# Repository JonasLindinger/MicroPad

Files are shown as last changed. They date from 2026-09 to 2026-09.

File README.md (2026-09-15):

# MicroPad — Wi-Fi MQTT Controller for Home Assistant

> AI-assisted development — firmware, HA automation, config generator and docs were created with AI (LLM) help, reviewed and tested by the author. Provided as-is, without warranty; verify on your own hardware, don't use for safety-critical applications.

MicroPad is a small ESP32-S3 desk controller with a 2.9" e-paper display, a 3×4
key matrix, and a rotary encoder. It talks to Home Assistant over MQTT and shows
clickable pages of your devices, media, scripts, scenes, and numbers. This
repository contains the firmware, the Home Assistant automation generator, the
web configurator, and the deployment/service assets.

## Safety

- **Not safety-critical.** This project is a convenience input device. Do not use
  it, or rely on it, for safety-critical applications (life-safety, medical,
  security, or anything where a missed or delayed press could cause harm). The
  room always retains the Home Assistant UI as the authoritative control surface.
- **Verify on your own hardware.** Firmware behaviour is validated by the compile
  matrix and host/static suites on this build machine, but no physical MicroPad
  hardware was available during development. Every hardware acceptance row is
  intentionally unchecked until an operator executes it on real hardware. Never
  assume a feature works on your specific board; test it.
- **Neutral placeholders only.** Source contains no real credentials. The broker
  host placeholder is `192.168.0.100`, the service user is `micropad`, and the
  placeholder password is `replace-me`. Real Wi-Fi/MQTT credentials are entered
  only through the on-device setup portal and stored in NVS.
- **Charge-only chargers.** A charge-only wall charger (no enumerated USB host)
  intentionally follows normal battery sleep behaviour: no power icon is drawn
  and light sleep is allowed. Only an enumerated USB data host keeps the device
  fully awake. See `docs/hardware-acceptance.md`.

## Reproducibility

The Python dependency graph is locked: `uv.lock` is the resolved source of
truth, and `requirements-lock.txt` is its content-hash materialization (every
wheel pinned with `sha256`, regenerated with `uv export --frozen`). The build
backend is pinned exactly (`setuptools==84.0.0`). This freezes dependency
*versions and content*; it does **not** claim byte-identical builds, because
pip/setuptools release artifacts can still vary between environments. Generated
automation/payload artifacts are deterministic per configuration (see below).

## Quick start

Create a virtualenv and install the package and dev tools (Ubuntu/Debian shown):

```bash
python3 -m venv .venv
.venv/bin/pip install --requirement requirements-dev.txt
```

For a content-hash-pinned runtime install (every transitive dependency locked in
`uv.lock` and materialized as `requirements-lock.txt` with `sha256` hashes)
instead use:

```bash
.venv/bin/pip install --requirement requirements-lock.txt
```

Run the configurator locally for development (Flask dev server):

```bash
.venv/bin/python -m flask --app micropad.wsgi:app run --host 127.0.0.1 --port 8080
```

Check it is healthy:

```bash
curl http://127.0.0.1:8080/healthz
# -> {"ok": true, "service": "micropad-configurator"}
```

For production, install the systemd service under `/opt/micropad/app` (root):

```bash
sudo ./scripts/setup.sh --enable-service
journalctl -u micropad.service -f
```

The on-device network setup and the build/flash workflow are described in
`docs/firmware.md`.

## Firmware

The firmware lives in `firmware/` (`MicroPad_HA_Controller.ino`,
`micropad_core.*`, and `protocol_contract.h`). It is built with Arduino CLI 1.5.1,
ESP32 core 3.3.11, GxEPD2 1.6.9, ArduinoJson 7.4.3, and PubSubClient 2.8.

```bash
./scripts/install-arduino-toolchain.sh        # pin the exact toolchain
./scripts/compile-firmware.sh --print-matrix  # list the three pinned FQBNs
./scripts/compile-firmware.sh                 # compile all matrix FQBNs
```

See `docs/firmware.md` for the pin map, build/flash commands, the setup portal,
and sleep behaviour.

## Home Assistant

A single MQTT automation (id `micropad_controller`) turns `micropad/event` and
`micropad/power` publications into device actions and re-publishes the
authoritative `micropad/pages/all`, `micropad/page/current`, and `micropad/keymap`
retained payloads. The automation and the retained initial payloads are generated
by `src/micropad/generator.py` and are byte-identical for the same configuration.

You can deliver the generated automation two ways:

- **API upload** — the configurator writes the automation directly to Home
  Assistant via its REST API and verifies the read-back, then publishes the
  retained MQTT payloads.
- **SSH upload** — the configurator uploads a YAML file to your Home Assistant
  host over SFTP/SSH with strict host-key checking and reloads, for setups where
  the REST API path is not available.

Both are covered in `docs/home-assistant.md`.

## Configurator

The Flask web configurator (`src/micropad/app.py`) validates your configuration,
lets you edit pages, key maps, and entity bindings in the browser, discovers
Home Assistant entities, and generates or uploads the automation.

- `GET /api/config` — current public configuration (credentials redacted).
- `POST /api/config` — validate and save a configuration.
- `POST /api/validate` — validate without saving.
- `POST /api/upload/api` — deploy via the Home Assistant REST API.
- `POST /api/upload/ssh` — deploy via SFTP/SSH.
- `GET /api/meta` — contract version, the fourteen key IDs, actions, item types,
  templates, and the default keymap.

See `docs/configurator.md` for the pages editor, key editor, entity discovery,
and validation rules, and `docs/deployment.md` for install/update/logs/uninstall.

---

Licensed under the [MIT License](LICENSE) (Copyright (c) 2026 Jonas Lindinger).
All content above is written in neutral English and uses only the placeholder
values described in the **Safety** section.

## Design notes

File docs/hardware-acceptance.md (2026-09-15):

# MicroPad Hardware Acceptance

> AI-assisted development — firmware, HA automation, config generator and docs were created with AI (LLM) help, reviewed and tested by the author. Provided as-is, without warranty; verify on your own hardware, don't use for safety-critical applications.

This document is a repeatable, row-by-row hardware acceptance gate for a physical
MicroPad bench unit. It is the English release companion to
`docs/firmware-hardware-validation.md`, which holds the full per-row checklists and
the compile/static evidence. Every check below records an **observed result** and a
**pass/fail**; no check may be marked pass from compilation or reasoning alone.

**IMPORTANT — observation rows.** No MicroPad hardware was available on the build
machine during development, so all physical device checks are intentionally left
**unchecked** in the committed revision, exactly as the F14/IT precedent did. The
compile matrix and the host/static suites prove the firmware builds green and the
source asserts hold; they prove *nothing* about physical behaviour. Each check must
be executed by an operator on real hardware and marked from direct observation.

> **Hardware validation not executed: compatible MicroPad hardware unavailable**

Credentials are the neutral placeholders only: broker host `192.168.0.100`, user
`micropad`, password `replace-me`. Real credentials are entered only through the
on-device setup portal and stored in NVS; never edit firmware, source, or docs to
embed real credentials.

## Record file, schema, and validator

The operator records every check in an anonymous, local acceptance record:

- **File (never committed):** `release/local-hardware-acceptance.json`
- **Strict contract:** `release/hardware-acceptance.schema.json`
  (`schema_version: 1`, 64-lowercase-hex `firmware_sha256`, anonymous `board_id`
  matching `bench-[0-9]{2}`, the exact 21 check IDs below all `true`, evidence
  entries `{check_id, kind, sha256, captured_at}`, `additionalProperties: false`
  throughout).
- **Validator:** `scripts/validate_hardware_acceptance.py` validates the record and,
  only when it is fully valid, writes the redacted
  `build/evidence/hardware-acceptance-summary.json` (check IDs, booleans,
  timestamps, firmware SHA-256, per-check evidence SHA-256). No operator, Wi-Fi,
  MQTT, Home Assistant, broker host, or device-entity data ever enters the summary.

```bash
.venv/bin/python scripts/validate_hardware_acceptance.py \
    --input release/local-hardware-acceptance.json \
    --output build/evidence/hardware-acceptance-summary.json
```

An incomplete record exits nonzero and lists every missing/invalid check; a fully
passing bench exits `0`. The local record stays ignored; only the redacted summary
joins the approval bundle.

## Equipment

- **Board:** ESP32-S3 (USB-CDC), wired as in the pin map in `docs/firmware.md`.
- **Display:** GxEPD2_290_T94_V2 2.9" e-paper (native 128x296, driven at rotation 1 as a 296x128 landscape canvas), CS8/DC40/RST41/BUSY42.
- **Inputs:** 3×4 matrix rows 47/48/45, columns 21/14/13/12; rotary encoder A10/B11
  (push = `r0c3` enter).
- **Power:** Li-Ion through a BQ24075 charge path; USB-C host or charge-only supply.
- **Network:** an MQTT broker on the host placeholder `192.168.0.100:1883` and a
  Home Assistant instance (or MQTT bridge) to reconcile state.

Timing checks use a hand stopwatch or the on-device/timing log; reference times are
exact thresholds, not approximations.

## Power and sleep

### `usb-host-icon-after-1500ms` — data-host icon edge-in

- **Setup:** bench unit awake on battery; attach an enumerated **USB-C data host**.
- **Action:** connect the data host and leave the device idle.
- **Observable:** **no** power icon before 1500 ms of host stability; after the
  stable window the power icon is drawn and the retained `micropad/power`
  `{"usb_host":true}` is published. Icon-edge interval measured **1.3–1.8 s**.
- **Evidence kind:** `video` (icon edge) + `timing-log` (edge interval).
- **Pass gate:** edge within 1.3–1.8 s and `usb_host:true` observed once.

### `usb-disconnect-clears-after-1500ms` — data-host icon edge-out

- **Setup:** data host enumerated (prior check state).
- **Action:** detach the data host.
- **Observable:** host removal is debounced the same window and the icon is cleared
  with `{"usb_host":false}` published; edge interval measured **1.3–1.8 s**.
- **Evidence kind:** `video` (icon removal) + `timing-log` (edge interval).
- **Pass gate:** `usb_host:false` observed once, edge within 1.3–1.8 s.

### `usb-host-prevents-sleep`

- **Setup:** enumerated data host connected, device awake.
- **Action:** leave idle past the normal idle-sleep threshold.
- **Observable:** while a data host is enumerated the device **never** enters light
  sleep — no sleep entry, no power icon change.
- **Evidence kind:** `timing-log` (elapsed idle) + `manual-observation`.
- **Pass gate:** no sleep entry for ≥ the idle-sleep threshold while host is up.

### `charge-only-follows-battery-sleep`

- **Setup:** attach a **charge-only wall charger** (no enumerated host).
- **Action:** leave idle past the normal idle-sleep threshold.
- **Observable:** the charger does **not** inhibit sleep — no power icon, and light
  sleep is entered at the normal battery idle threshold (mirror of the host case).
- **Evidence kind:** `timing-log` + `video`.
- **Pass gate:** light sleep entered at normal idle threshold; no power icon.

### `battery-idle-sleeps-near-60s`

- **Setup:** on battery, no USB host, freshly woken, no held keys.
- **Action:** stop touching the device; measure with a stopwatch.
- **Observable:** light sleep after ≈60 000 ms of idle; stopwatch threshold
  **55–70 s**; **no post-sleep watchdog reset** (loop-task TWDT mitigation).
- **Evidence kind:** `timing-log` (stopwatch) + `serial-disabled` (no marker output).
- **Pass gate:** sleep between 55 and 70 s; no watchdog reset after wake.

### `wake-action-immediate`

- **Setup:** device asleep on battery (prior sleep check).
- **Action:** wake with a matrix press or an encoder detent.
- **Observable:** the **waking press becomes the first action** and its effect is
  visible in the **first rendered post-wake snapshot**; no ghost pixels from the
  renderBusy race window; the encoder wake does not lose the next detent.
- **Evidence kind:** `video` (first post-wake snapshot) + `manual-observation`.
- **Pass gate:** first post-wake snapshot shows the waking action; no ghosting.

## Input

Input IDs: matrix `r0c0`…`r2c3` (12 IDs) plus `enc_up` and `enc_down` (14 bindable
IDs, `KEY_COUNT == 14`). Every press must emit exactly one `micropad/event` after
the 25 ms debounce, with no repeat while held.

### `matrix-all-twelve`

- **Setup:** awake, default keymap.
- **Action:** press each of the twelve matrix keys once.
- **Observable:** exactly one `micropad/event` per debounced press, no repeat while
  held, and all **twelve** matrix IDs (`r0c0`…`r2c3`) emit their expected binding.
- **Evidence kind:** `video` (visible presses) + `manual-observation`.
- **Pass gate:** all 12 IDs emit exactly once per press; no repeats while held.

### `encoder-clockwise-down`

- **Setup:** awake, on a page with a selection.
- **Action:** one clockwise/right detent.
- **Observable:** emits `enc_down` and the selection moves **+1**; one step per
  detent with no repeat while the knob stays in a detent.
- **Evidence kind:** `video` + `timing-log`.
- **Pass gate:** `enc_down` on clockwise detent and selection +1.

### `encoder-counterclockwise-up`

- **Setup:** awake, on a page with a selection.
- **Action:** one counterclockwise/left detent.
- **Observable:** emits `enc_up` and the selection moves **−1**; one step per detent.
- **Evidence kind:** `video` + `timing-log`.
- **Pass gate:** `enc_up` on counterclockwise detent and selection −1.

### `encoder-push-r0c3`

- **Setup:** awake, on a page where `r0c3` is the enter action.
- **Action:** press the enclosure **push** button on the encoder.
- **Observable:** the push acts as `r0c3` (enter): one `micropad/event` for `r0c3`
  and the mapped enter action fires.
- **Evidence kind:** `video` + `manual-observation`.
- **Pass gate:** push produces a single `r0c3` event and the enter action.

### `input-during-refresh`

- **Setup:** awake, a display refresh is about to be triggered.
- **Action:** trigger a refresh and hold a key during the BUSY window.
- **Observable:** the input state change is applied **before the refresh
  completes** — input scanning on Core 1 never starves matrix/encoder.
- **Evidence kind:** `video` + `manual-observation`.
- **Pass gate:** the held key registers before the refresh finishes.

## Display

The panel is a 2.9-inch e-paper (native 128x296) driven at rotation 1 as a 296x128
landscape logical canvas. "Four visible rows" refers to the readable item list
that must render fully across the 296-px-wide landscape canvas.

### `boot-full-refresh`

- **Setup:** device powered down/off.
- **Action:** power on / reset.
- **Observable:** boot performs a **full refresh** — the whole 128×296 panel clears
  and redraws before any partial content appears.
- **Evidence kind:** `video`.
- **Pass gate:** full-panel refresh visible once at boot.

### `display-four-rows`

- **Setup:** a page with at least four bindings, default keymap.
- **Action:** navigate to that page.
- **Observable:** the UI is readable: title/status strip, **four item rows**,
  selection cursor, conditional scrollbar, and network-status cell all render
  clearly in the 296×128 landscape canvas.
- **Evidence kind:** `photo`.
- **Pass gate:** four item rows fully visible and readable.

### `full-panel-partial-refresh`

- **Setup:** awake on a page with multiple rows.
- **Action:** trigger a navigation partial refresh.
- **Observable:** every partial refresh is a **single full-native-panel**
  `setPartialWindow(0,0,128,296)` window — no per-row windows and no partial-row
  striping.
- **Evidence kind:** `video` + `timing-log`.
- **Pass gate:** partial refresh uses the full native 128×296 window each time.

### `ghosting-bound`

- **Setup:** awake; perform several refreshes.
- **Action:** run repeated (partial) refreshes over the same area.
- **Observable:** **no per-row waveform / ghost banding** — prior content leaves no
  residual banding layer across refreshes (bounded ghosting).
- **Evidence kind:** `photo` + `manual-observation`.
- **Pass gate:** no visible residual banding after repeated refreshes.

## Connectivity

### `portal-random-password`

- **Setup:** first boot with no saved settings.
- **Action:** power on and observe the setup access point, then exit and
  re-enter the setup portal (or reboot twice).
- **Observable:** AP `MicroPad-Setup` appears and the panel shows a
  **16-character password**. The password is **generated once from hardware
  entropy and persisted in NVS** — the same password is shown on every later
  portal entry, so a phone that already joined reconnects with the saved
  network instead of a new code.
- **Evidence kind:** `photo` + `manual-observation`.
- **Pass gate:** AP name present, a 16-character password shown, and the same
  password after portal exit/re-entry.

### `portal-never-sleeps`

- **Setup:** setup portal open, battery powered.
- **Action:** leave the portal idle past the normal battery idle-sleep
  threshold (~60 s), then keep waiting.
- **Observable:** the portal stays fully awake — the AP keeps beaconing, the
  DNS/web server keeps answering, the phone stays connected. No light-sleep
  entry while the portal is active; the portal's own
  ≈5-minute inactivity restart is the only shutdown path.
- **Evidence kind:** `video` + `manual-observation`.
- **Pass gate:** no sleep entry while the portal is open (sleep only after
  portal exit / settings saved).

### `portal-input-responsive`

- **Setup:** setup portal open.
- **Action:** operate matrix/encoder while the portal is open.
- **Observable:** matrix and encoder remain **responsive** while the portal is open —
  inputs are never starved by the portal loop.
- **Evidence kind:** `video` + `manual-observation`.
- **Pass gate:** inputs respond while the portal is open.

### `portal-back-no-save`

- **Setup:** portal open with unsaved edits.
- **Action:** select **Back** / cancel.
- **Observable:** the portal exits leaving **NVS/settings unchanged** — no save and
  no reconnect to any saved network.
- **Evidence kind:** `video` + `manual-observation`.
- **Pass gate:** after Back, no stored credential change and no reconnect.

### `wifi-mqtt-nonblocking`

- **Setup:** device connected to station network and broker.
- **Action:** navigate and toggle while the network transmits/reconnects.
- **Observable:** Wi-Fi/MQTT operations **never block** matrix/encoder input (Core 1
  input scanning continuous), and there is **no USB CDC output on any hot path**.
- **Evidence kind:** `video` + `serial-disabled`.
- **Pass gate:** responsive input throughout; no CDC output on hot paths.

### `mqtt-reconnect-resubscribe`

- **Setup:** device connected; broker running.
- **Action:** interrupt the broker link (stop then restore the broker), then wait.
- **Observable:** the stale socket is invalidated and MQTT **reconnects immediately**
  after the interruption, **resubscribing** to `micropad/pages/all`,
  `micropad/page/current`, and `micropad/keymap`; retained payloads are recovered on
  (re)connect with concrete values.
- **Evidence kind:** `video` + `timing-log`.
- **Pass gate:** reconnect immediate; all three retained topics recovered.

### `authoritative-resync`

- **Setup:** local display diverges from authoritative state.
- **Action:** publish an authoritative update, then leave the device idle.
- **Observable:** an **authoritative correction arrives after the 350 ms quiet-period
  resync** when local and authoritative disagree; retained `micropad/pages/all` and
  `micropad/page/current` carry concrete states, not `{{ states(...) }}` templates.
- **Evidence kind:** `video` + `manual-observation`.
- **Pass gate:** correction arrives after resync; no templated retained payloads.

MicroPad is not safety-critical. It is provided as-is, without warranty, and every
row here must be verified on your own hardware before relying on the device.

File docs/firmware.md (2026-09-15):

# MicroPad Firmware Guide

> AI-assisted development — firmware, HA automation, config generator and docs were created with AI (LLM) help, reviewed and tested by the author. Provided as-is, without warranty; verify on your own hardware, don't use for safety-critical applications.

This guide covers building and flashing the MicroPad firmware
(`firmware/MicroPad_HA_Controller.ino`, `firmware/micropad_core.*`,
`firmware/protocol_contract.h`). It is written in English and contains no real
credentials — only the neutral placeholders described below.

## Contract

`contracts/mqtt-contract.json` is the single source of truth for the wire
protocol: version, topics, key IDs, actions, item types, the descriptor row per
item type, the payload ceilings and the device caps. Everything else is derived
from it:

- `firmware/protocol_contract.h` is **generated** —
  `python3 scripts/generate_contract.py --write` after a contract change, and
  `--check` is the drift gate (also asserted by
  `tests/integration/test_mqtt_contract.py`). Never hand-edit the header.
- `src/micropad/constants.py` and `src/micropad/ui_meta.py` read the contract at
  import time, so the backend, `/api/meta` and the browser cannot lag behind it.
- the browser's `static/js/contracts.js` key-ID/version block is generated too.

Adding an action, an item type, a topic or a limit is therefore a contract edit
plus a regenerate — no code path has to be kept in sync by hand. A static test
additionally asserts that the firmware's `Action`/`ItemType`/`KeyId` enums are in
contract order, that `micropad_core.h`'s caps equal the contract's, and that
`micropad_core.cpp`'s `ITEM_TYPE_DESCRIPTORS` table matches `item_type_meta`.

## Pin map

| Function | GPIO(s) |
|---|---|
| E-Paper CS / DC / RST / BUSY | 8 / 40 / 41 / 42 |
| Matrix rows (active-low) | 47, 48, 45 |
| Matrix columns | 21, 14, 13, 12 |
| Encoder A / B | 10 / 11 |

The display is a GxEPD2_290_T94_V2 2.9" e-panel (`128×296`, full-width partial
windows). Three rows × four columns plus the two encoder detents give the
fourteen bindable input IDs: `r0c0 … r2c3`, `enc_up`, `enc_down`. Rows are
driven active-low and restored after scanning.

## Build

The toolchain is pinned to Arduino CLI **1.5.1**, ESP32 core **3.3.11**,
GxEPD2 **1.6.9**, ArduinoJson **7.4.3**, and PubSubClient **2.8**. Preface the
commands with the repo `python3`-based workflows as needed; the toolchain script
is self-contained bash.

```bash
./scripts/install-arduino-toolchain.sh          # install + verify the pins (rootless, repo-local .arduino/)
./scripts/compile-firmware.sh --print-matrix    # show the three pinned FQBNs
./scripts/compile-firmware.sh                   # stage + compile all matrix FQBNs
./scripts/compile-firmware.sh --one <FQBN>      # stage + compile a single validated FQBN
./scripts/compile-firmware.sh --stage-only <FQBN>  # stage only (no toolchain), into build/arduino/
```

The script stages the reviewed sources into
`build/arduino/MicroPad_HA_Controller/`, compiles with `--warnings all`
plus `-Werror=return-type`, and compiles the three FQBNs:

```
esp32:esp32:esp32s3:USBMode=hwcdc,CDCOnBoot=cdc,PSRAM=opi
esp32:esp32:esp32s3:USBMode=default,CDCOnBoot=cdc,PSRAM=opi
esp32:esp32:esp32s3:USBMode=hwcdc,CDCOnBoot=default,PSRAM=disabled
```

## Flash

The recommended upload FQBN for a USB-CDC data host is
`esp32:esp32:esp32s3:USBMode=hwcdc,CDCOnBoot=cdc,PSRAM=opi`. Upload a staged
sketch with Arduino CLI against its enumerated serial device:

```bash
arduino-cli upload \
  --config-file arduino-cli.yaml \
  -p /dev/ttyACM0 \
  --fqbn "esp32:esp32:esp32s3:USBMode=hwcdc,CDCOnBoot=cdc,PSRAM=opi" \
  build/arduino/MicroPad_HA_Controller/
```

Do not embed real Wi-Fi or MQTT credentials in the firmware; they are entered
at runtime through the setup portal and stored in NVS.

## Setup portal

On first boot (or when no network settings are saved) the device starts a captive
portal AP named `MicroPad-Setup` with a 16-character password shown on the
panel. The password is generated once from hardware entropy, stored in NVS, and
**reused by every later portal entry** — it never rotates between sessions, so a
phone that already joined the AP reconnects with the same saved network. From
the portal you save the station Wi-Fi credentials and the MQTT broker
settings (host, port, user, password), then the device restarts its AP and
reconnects to the network and broker. The matrix and encoder remain responsive
while the portal is open; `Back` cancels and leaves settings unchanged; the
portal restarts itself after roughly 5 minutes of inactivity. Entering the portal
is bound to the `settings` action. While the setup portal is open the device
**never enters light sleep** — sleeping would silence the AP, DNS and web server
mid-setup.

The portal is also reachable without a working keymap: if the pad has stored
settings but cannot associate for 24 consecutive attempts (~2 minutes), it
re-opens the setup portal by itself, so a mistyped Wi-Fi password or a moved
access point cannot strand the device. The panel shows the portal view, and
`Back` (bound by default) cancels it and keeps the stored settings.

A save is applied atomically in the sense that the NVS commit marker (`cfg_ver`)
is cleared before the first field is written and set to `1` only after every
field was stored. An interrupted save is therefore an invalid record, and the
next boot falls back to the setup portal instead of connecting with a mixture of
old and new credentials.

The broker host placeholder used in source is `192.168.0.100`, the user
placeholder is `micropad`, and the password placeholder is `replace-me`. Replace
these only through the portal.

## Sleep

When the device is on battery and idle for about 60 seconds **and not powered by
a USB data host**, it enters warm light sleep (`esp_light_sleep_start`), waking on
the matrix or encoder (EXT1, ANY_LOW). Behaviours worth knowing:

- Sleep is refused while USB-powered, and "powered" means an enumerated **data**
  host. Detection lives in `isPowered()`: the USB-serial-JTAG host check
  (`Serial.isPlugged()`, the IDF SOF watchdog — true while a host holds the port
  open, even with no serial monitor attached) plus the HWCDC session flag. The
  debounced state (`stableUsbHost`, 500 ms sample / 1500 ms stable) blocks both
  sleep guards as well, so a single flapping raw read cannot open the sleep path.
- `configureCdc()` calls `Serial.begin(115200)` in the hwcdc build: the core
  starts USB CDC automatically for the TinyUSB build only
  (`cores/esp32/main.cpp`: `#if ARDUINO_USB_CDC_ON_BOOT && !ARDUINO_USB_MODE`), and
  without the driver being started the HWCDC interrupt handler — the only setter
  of the CDC session flag — and the D+ pull-up never exist. A pad on a plain USB
  cable would then read as battery-powered.
- A **charge-only wall charger** (no enumerated host) intentionally follows normal
  battery sleep behaviour: no power icon and light sleep allowed.
- Light sleep is currently **disabled** (`LIGHT_SLEEP_ENABLED = false`) until the
  S3 wake path is fixed (phantom key presses after wake, see the `loop()` comment).
  The detection above still drives the power icon and the retained
  `micropad/power` state, and it is what has to be correct before sleep is
  re-enabled.
- The 15-second MQTT keepalive is used to invalidate a stale socket after a long
  sleep, so MQTT reconnects immediately on wake.
- The render task's watchdog entry is removed before sleep and restored after
  wake; matrix rows are driven low and restored on wake so the waking press
  becomes the first action.
- After wake there is a short brake so the device does not immediately re-sleep.

For the full acceptance rows (including the >60 s sleep, watchdog, and ghost-pixel
checks) see `docs/hardware-acceptance.md`.

## Input, payload and stack limits

- **Values are never rejected for being long.** Item names, page titles, states
  and units are *clipped* to their 32-character fields (the renderer shows 12
  characters of a value and 22 of a title), so a long Home Assistant state — for
  example a template sensor with a verbose string — cannot discard a whole page
  or catalog payload. Identifiers (`page_id`, `entity`, `target_page`) keep the
  strict check: a silently clipped entity id would address the wrong device.
- **The MQTT buffer bounds the catalog.** The client buffer is 16 KiB
  (`MQTT_BUFFER_BYTES`, mirrored in `contracts/mqtt-contract.json`); a retained
  `micropad/pages/all` that exceeds it is discarded by PubSubClient without
  telling the application. While the pad is connected but has no catalog, it
  re-requests the catalog every 60 seconds, so a lost publication is repaired
  instead of leaving an empty page.
- **The loop task stack is 16 KiB.** The MQTT callback parses the PubSubClient
  receive buffer in place (no payload copy), which keeps its frame near 7 KB;
  16 KiB leaves a ~2.3x margin and returns the rest of the former 32 KiB to the
  heap, where the 16-KiB MQTT buffer and the WiFi/lwIP buffers live. The value is
  the core constant `LOOP_TASK_STACK_BYTES`, so the sketch, the device-info
  payload and the tests cannot disagree about it.
- **The pad advertises its own limits.** On every MQTT connection the device
  publishes the *retained* payload `micropad/device`:

  ```json
  {"fw": "1.2.0", "contract": 2, "caps": {"pages": 24, "items": 20, "name": 32,
   "title": 32, "page_id": 32, "entity": 96, "state": 32, "unit": 16,
   "mqtt_buffer": 16384, "stack": 16384}}
  ```

  Every value is read from the firmware's own constants, so it describes what
  this build really enforces instead of what the backend assumes. A late
  subscriber (the backend, the configurator) gets it without asking, which is
  what lets `/api/meta` report the pad's real field caps and warn before a value
  would be clipped on the panel.

## Input gestures

Each of the fourteen inputs behaves the same whether it is tapped or held, with one
exception that costs no extra binding storage: **holding the Enter key fires the
item's *alternate* action instead of its default one.** The item-type descriptor
decides which types have one — a light or a switch turns **off** on a hold instead
of toggling; every other type ignores the hold (`alternate_action` in
`contracts/mqtt-contract.json`, mirrored by `ITEM_TYPE_DESCRIPTORS`). The gesture
dispatches an ordinary action, so the MQTT event, the Home Assistant automation and
the payload schemas are unchanged.

* `LONG_PRESS_MS` (600 ms, core) is measured from the *debounced* press, so a tap
  can never fire it, and it fires exactly once per hold.
* A hold keeps the pad awake (it counts as input activity) and therefore cannot
  race the 60 s sleep gate.
* The press that woke the device from light sleep is consumed by the immediate wake
  scan, so holding it does not also fire the gesture — otherwise holding the key
  that woke the pad would turn something off.

## Stored settings and the setup portal

Settings live in NVS under the namespace `micropad`, guarded by a `cfg_ver` commit marker that
is invalidated first and written last, so an interrupted save is an invalid record rather than a
mixture of old and new credentials. A record is accepted only when the marker is current, every
expected key exists, every value reads back inside its field, and the whole candidate validates
(`micropad::validateSettings`), which is defined in terms of `settingsError()` so the rule and
the message cannot drift apart. A rejected record means the pad starts its own setup portal -
which is also what makes the read path worth pinning:

* **Strings are read with string APIs** (`isKey()` for presence, `getString()` for the value,
  which refuses an oversized value instead of truncating) and integers with the type-aware
  `getType()`/`getUShort()` pair. `Preferences::getBytesLength()` must never be used for either:
  it is a *blob* accessor (it calls `nvs_get_blob`), and an IDF blob read on an entry written
  with `nvs_set_str` fails with `ESP_ERR_NVS_TYPE_MISMATCH`. It therefore reports 0 for a value
  that is present, which makes every stored string look absent, rejects a complete record, and
  sends a fully configured pad back into the portal on **every boot**. A static test pins the
  type-correct API usage precisely because this failure is silent and looks like a Wi-Fi problem.
* A refused save answers with the reason (`settingsError()`: which field and what is expected,
  never its value), so the portal is fixable in place instead of showing "invalid settings".

## Diagnostics

The payload carries `uptime_s`, `mqtt_connects`, the accept/reject counters per payload type,
`event_drops`, the heap free and heap high-water figures, and `stack_min` - the loop task's stack
high-water mark in bytes free, sampled with `uxTaskGetStackHighWaterMark()` from the loop task
itself. `stack_min` is what confirms the 16 KiB loop stack on real hardware: the linked call
frames say the worst callback uses 6,704 B, and this number shows how much was actually left.
The worst-case payload (ten 10-digit values) measures 254 bytes against a 320-byte cap.

Every connection publishes the retained `micropad/diag` payload, refreshed once a
minute while connected:

```json
{"uptime_s":3661,"mqtt_connects":3,"catalog_parses":2,"catalog_rejects":1,
 "page_rejects":4,"keymap_rejects":5,"event_drops":6,"heap_free":123456,
 "heap_min":100000}
```

The counters answer the questions a serial console used to answer: is the pad
reconnecting in a loop, did a retained payload get rejected, did events get dropped
because the queue was full, and how close did the heap get to exhaustion. The
struct and the formatter live in `micropad_core.h`/`.cpp` (`formatDiagnostics`,
host-tested byte for byte), so the sketch only bumps counters and publishes; the
payload is rendered into a 256-byte stack buffer with no JSON document, and the
formatter refuses to write rather than emitting a truncated object.

## Host simulator (panel preview)

`tools/micropad_sim.cpp` compiles `micropad_core.cpp` into a host binary that
answers "what does the panel render for this page, and what does this key do?":

```bash
./scripts/build-simulator.sh                 # g++ only, no Arduino toolchain
printf 'page home Home\nitem Desk light\t on\t\t0\tlight\tlight.desk\t\nkey r0c3\tenter\tlight.desk\t\npress r0c3\n' \
  | ./build/host/micropad_sim
```

It prints one JSON object: the row window, the prim list from `layoutNormalUi` /
`layoutPortalUi`, `would_reject` plus `findings` for anything the pad would clip or
refuse, and — when a `press` directive is given — what the binding and the item
under the cursor resolve to. The configurator's preview and budget panel are
driven by it (`docs/configurator.md`), and `tests/test_simulator.py` pins the
output, including a check that the recorded browser fixture still matches the
current core.

The tool contains no geometry or policy of its own: it reads a small directive
format and calls the core. `fillPageSnapshot()` in the core is the shared
snapshot builder used by both the sketch and the simulator, so the row window,
title and selection flags cannot differ between the panel and the preview.

## Not safety-critical

This firmware drives an e-paper controller and sends MQTT events; it is a
convenience input device, not a safety mechanism. It is provided as-is, without
warranty, and must be verified on your own hardware. Do not use it for
safety-critical applications.

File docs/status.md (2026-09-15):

# MicroPad — status: what is done, what is left

> AI-assisted development — firmware, HA automation, config generator and docs were created with AI (LLM) help, reviewed and tested by the author. Provided as-is, without warranty; verify on your own hardware, don't use for safety-critical applications.

**Merged into `main`** through PR #9 (merge commit `de680e2`, both histories preserved: `main`'s own
line and this branch's, which share no ancestor). **Release: `v1.2.0`** — firmware `1.2.0`,
contract revision `2`; see `CHANGELOG.md` for what is in it, what was measured and what is
deliberately left out. Every claim below was verified with real
runs; nothing is "should work".

**Current baseline** (real `arduino-cli` build, pinned `hwcdc/PSRAM` FQBN):
flash **1 006 963 B (76 %)** · static RAM **173 364 B (52 %)** · 302 757 B flash free.
**Tests:** 834 pytest (44 of them browser) · 199 firmware static · host core binary · 193 release.

---

## ✅ Done (shipped, tested, pushed)

### Phase A — makes adding features cheap

| ID | What | Commit | Proof |
|---|---|---|---|
| **A1** | **Contract is the single source of truth.** `contracts/mqtt-contract.json` drives everything; `scripts/generate_contract.py --write/--check` generates `firmware/protocol_contract.h` + the browser key-ID block; Python derives at import | `ee98fcf` | 8 drift gates (codegen, enum order = wire order, firmware caps = contract caps, descriptor table = contract, backend rules, `/api/meta`, browser fixture) |
| **A2** | **One descriptor row per item type** (`ItemTypeDescriptor`: default action, alternate action, editable) drives `actionForSelectedItem`, `models.py`, `generator.py`, `/api/meta`, the editor | `ee98fcf` | host test `testItemTypeDescriptorTable` + drift gate |
| **A3** | **Pad advertises its own limits**: retained `micropad/device` (`fw`, `contract`, `caps` from its own constants) | `ee98fcf` | `/api/meta` exposes `limits`/`caps`/`item_type_meta` |
| **A4** | **Firmware-in-the-loop simulator**: `tools/micropad_sim.cpp` compiles the shipped core; the sketch's row loop moved into the core (`fillPageSnapshot`) so panel and preview share one builder | `6e2b1ce` | `tests/test_simulator.py`; fixture recorded from the real binary + a drift gate |
| **A5** | **`/api/simulate`** renders a page (or the portal) through that binary; 503 when missing, 400 with the offending field | `6e2b1ce` | route tests |
| **A6** | **Config-lint CLI** `scripts/lint_config.py` (exit 0/1/2, `--strict`, `--json`) + **a CI hole closed**: the `firmware-host` stage now also runs `test_core.cpp` and the 142 static tests (they ran nowhere in CI before) | `18644b9` | stage dry-run green |
| **A7** | **Golden-file tests**: automation YAML + the three published payloads frozen in `tests/fixtures/golden/`, regenerate with `MICROPAD_UPDATE_GOLDEN=1` | `d0f319d` | negative test: mutating a golden fails two tests |
| **A8** | **Pre-commit gate** `.githooks/pre-commit` (ruff, mypy, contract drift, firmware host ≈ 4 s) — documented, deliberately **not** auto-enabled | `d0f319d` | hook dry-run |
| **A9** | **Developer guide** `docs/developer.md`: recipes (action / item type / topic / template), gate table, conventions tests enforce | `d0f319d` | — |

### Phase B — the config website

| ID | What | Commit | Proof |
|---|---|---|---|
| **B1** | **Faithful panel preview**: `panel-preview.js` draws the core's prim model as SVG (296×128, monochrome, FreeMono) + portal toggle — no layout knowledge in the browser | `6e2b1ce` | browser tests against a real recorded model |
| **B2** | **Budget meters**: page/catalog/MQTT-buffer/pages/items from `/api/lint` | `6e2b1ce` | browser test |
| **B3** | **"What the device changes"**: `field_clipped` warnings vs `identifier_too_long` errors with `where` paths | `6e2b1ce` | route + browser tests |
| **B4** | **Hardware-shaped keymap board**: 3×4 + encoder; each face shows the effective action and its origin (`global` / `inherited` / `override`) | `a8d4262` | browser test incl. the scope transitions |
| **B5** | **Page generation from the entity cache**: `/api/entity-groups` + `/api/build-pages` (one page per domain, split at 20, 24-page ceiling, real `number` ranges, clipping reported in `notes`) + UI buttons | `a9be614` | 8 backend + 3 browser tests |
| **B7** | **Config history / diff / restore**: content-addressed snapshots beside the config (mode 600, git-ignored), list, structural diff that never prints secrets, confirmed restore in the UI | `26f41d0` | 10 backend + 3 browser tests incl. traversal + stale revision |

### Phase C — device features

| ID | What | Commit | Proof |
|---|---|---|---|
| **C1** | **Long press**: a hold dispatches the item's *alternate* action (light/switch → off); timing in the core (`LONG_PRESS_MS` 600, once per hold), wake press exempt, no protocol change, +184 B flash / +48 B RAM | `a6467cb` | host test (tap/hold/re-arm/None) + static pin |
| **C2** | **Diagnostics**: retained `micropad/diag` (uptime, MQTT connects, parse accept/reject counters, dropped events, heap high-water), formatter in the core, 256 B stack buffer, +768 B flash / +40 B RAM | `38cffc0` | host test byte-for-byte incl. worst case |
| **Fix** | **The pad re-entered the setup portal on every boot**: the NVS read helpers used the blob accessor `getBytesLength()`, which reports 0 for a value stored as a string, so `loadSettings()` rejected a complete record every time. Fixed with the string-shaped APIs and pinned by a static test (the old test *required* the broken accessor) | `e751e45` | 199 static + host core; needs one flash to confirm on hardware |
| **Fix** | **The `ci` workflow was red on this branch, and nobody was watching it**: a test read `Dockerfile.local`, a file that only ever existed on one machine, so the workflow failed at the `coverage` stage and the eleven stages behind it never ran. Fixed by shipping the (secret-free) Dockerfile and testing the tracked file; the whole stage list now runs | *CI fix* | the deployment test was re-run in a clean checkout, i.e. the exact CI condition |
| **Fix** | **The firmware CI stage silently skipped four contract classes** — `unittest.main()` sat above them, so the stage exercised 142 of 198 cases and reported green | `28ce2ea` | the stage and pytest now report the same count |
| **C4** | **Four new item types**: `cover`, `fan`, `input_boolean`, `lock` — each one contract row + one firmware descriptor row + the HA service mapping; the editor, `/api/meta` and the validation follow automatically. Tapping toggles (a lock *locks*), holding turns off (a lock *unlocks*); a cover has no hold action because HA's cover integration has no `turn_off` | `d2ec93b` | 7 new generator service rows, host descriptor assertions, all item-type pins updated. +64 B flash, 0 B RAM |

---

## 🔜 Left, and unblocked

| ID | Item | Effort |
|---|---|---|
| **C4b** | **`select`/`input_select` item type** — the encoder cycles the options; needs the option list in the payload plus a "next option" behaviour, i.e. a small contract decision | M |
| **C6** | **Icon/glyph set** in the prim model (wifi-error, lock, play/pause, thermometer, brightness) | S |
| **C7** | **Portal: factory reset + connection result** (reset part; OTA is bigger) | M |
| **C8** | **Per-page refresh policy** + dashboard template (periodic partial refresh) | M |
| **C9** | **Breadcrumb depth in the title strip** + long-press context menu on a row | S–M |
| **B8** | **Post-upload read-back**: after upload, re-read the retained topics and compare (`scripts/verify_live_mqtt.py` is the basis) | S–M |
| **B9** | **German/English, dark mode, mobile layout** of the configurator | S–M |
| **C5** | **Dimmer interaction** (hold + encoder steps a light's brightness) | M |

## ⛔ Left, blocked on an open decision

| ID | Item | The decision |
|---|---|---|
| **B6** | **Live device mirror + remote key press** — would have made the last debugging session much faster | The backend needs **broker credentials** (a new secret surface in the configurator, redaction, and a paho-mqtt dependency). Or: skip the mirror, do only remote key press via HA's `mqtt.publish` service (uses the existing HA token). |
| **C1b** | **Double press + encoder acceleration** (rest of C1) | A *contract* decision: a repeat/step parameter, or a second action + target per key (≈ +1.8 KB RAM) — or drop double press and do only encoder acceleration. |
| **B12** | **"One page per *room*"** | Needs the HA **area registry** (WebSocket API / a second credential), not `/api/states`. |
| **B11** | **Move payload decoding into the core** (removes the last mirrored logic and ArduinoJson from the hot path) | Device-facing refactor of the MQTT callback — needs a hardware test pass to be called done. |

## 🔌 Left, needs the real pad

| ID | Item |
|---|---|
| **D1** | Battery gauge (needs a PCB revision) |
| **D2** | Wall-dashboard mode (timer wake + deep sleep) |
| **D3** | Encoder push button (verify the part first) |
| **C1/C2** | the shipped gestures/diagnostics are host-verified only — one press on the pad and one look at `micropad/diag` would close them (the payload now carries `stack_min`, the loop stack's high-water mark, so the 16 KiB stack is confirmed by reading a topic) |
| **Settings fix** | flash, configure once through the portal, restart: the pad must come up in normal mode instead of reopening the portal |
| **C3** | Notification banner (HA → pad): firmware render work, then a real-pad check |
| **C10** | Multi-device support |

---

## How to verify any of this yourself

```bash
bash scripts/test_firmware_contract.sh        # contract + core host + 142 static (~2 s)
.venv/bin/python -m pytest -q                 # everything (~75 s)
.venv/bin/python -m pytest tests/browser -q   # just the UI in Chromium (~30 s)
python3 scripts/lint_config.py config.json    # would the pad store/show this config
python3 scripts/generate_contract.py --check  # generated sources not stale
./scripts/build-simulator.sh                  # the host binary the preview uses
./scripts/compile-firmware.sh --one "esp32:esp32:esp32s3:USBMode=hwcdc,CDCOnBoot=cdc,PSRAM=opi"
```

Explicitly **not** done, on purpose: a second protocol version, any cloud dependency, a scripting
engine on the device, bigger buffers, OTA outside the portal. ("Don't do" list kept honest: see the
roadmap at `docs/roadmap.md` for effort/risk per item and the reasoning.)

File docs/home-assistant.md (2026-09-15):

# MicroPad × Home Assistant

> AI-assisted development — firmware, HA automation, config generator and docs were created with AI (LLM) help, reviewed and tested by the author. Provided as-is, without warranty; verify on your own hardware, don't use for safety-critical applications.

This guide explains how MicroPad talks to Home Assistant and the two ways to
deploy the generated automation. The broker host placeholder used throughout is
`192.168.0.100` (user `micropad`, password `replace-me`); real values are entered
only through the configurator or the on-device setup portal, never in source.

## MQTT contract

MicroPad and Home Assistant share one versioned contract
(`contracts/mqtt-contract.json`, bindings in `firmware/protocol_contract.h` and
`src/micropad/constants.py`, contract version **1**). Seven exact topics:

| Topic | Direction | Retain | Purpose |
|---|---|---|---|
| `micropad/event` | device → HA | no | decoded key/encoder action |
| `micropad/pages/all` | HA → device | yes | boot-time page catalog |
| `micropad/page/current` | HA → device | yes | current page payload |
| `micropad/keymap` | HA → device | yes | effective per-page key map |
| `micropad/power` | device → HA | yes | USB/power state (`usb_host` true/false) |
| `micropad/device` | device → HA | yes | firmware build + the caps the pad enforces (`fw`, `contract`, `caps`) |
| `micropad/diag` | device → HA | yes | uptime, MQTT connects, parse accept/reject counters, dropped events, heap high-water mark |

The generator (`src/micropad/generator.py`) turns a validated configuration into
one automation with id `micropad_controller` plus the three retained initial
publications (`micropad/pages/all`, `micropad/page/current`, `micropad/keymap`).
Payload ceilings are 8192 bytes per page, 16000 per catalog, 16380 per keymap,
with a 16384-byte firmware MQTT buffer. Generation is deterministic: the same
config produces byte-identical YAML, JSON, and MQTT payloads.

## API upload

`POST /api/upload/api` (implemented by `src/micropad/ha_deploy.py`) deploys
directly to a running Home Assistant over its REST API:

1. verifies auth (`/api/ha/test`), then create-or-update the automation by id;
2. calls `automation.reload`, then **reads back** the automation and confirms the
   structure matches what was generated;
3. re-generates with fresh entity state and publishes the three retained MQTT
   topics, verifying each publication.

Requirements: a Home Assistant long-lived access token
(`settings.ha_token`), the instance URL (`settings.ha_url`, e.g.
`http://homeassistant.local:8123`), and **TLS verification on by default**
(`settings.verify_tls` defaults to `true`). The token is redacted from every
public response (`ha_token_configured` reports only a boolean). A verified
evidence record (automation id, SHA-256, request order, published-topic list) is
emitted through the deployer's evidence sink.

## SSH upload

`POST /api/upload/ssh` (implemented by `src/micropad/ssh_upload.py`) targets
installations where the REST/automation path is not usable, by pushing the
generated YAML over SFTP/SSH with **strict host-key checking**:

- writes a temp copy next to `settings.remote_path` (default
  `/config/automations/micropad.yaml`);
- runs a fixed, in-code validation `test -s <temp>` — no user-supplied command;
- atomically `mv`s it into place, then applies the fixed reload for the
  `settings.ssh_reload_strategy` enum (`core_restart` → `ha core restart`, or
  `none` to skip);
- rejects placeholders, non-absolute remote paths, and any shell-metacharacter
  path values. No free-form remote command is accepted from the API, so a
  compromised config endpoint can never inject a remote shell command.

`GET /api/download/ssh` returns a secret-free `upload_micropad.sh` operator
script that reproduces the same SFTP upload from environment variables
(`SSH_KEY`, `AUTOMATION_YAML`) without embedding credentials.

**Difference from API upload:** SSH upload transfers only the automation YAML and
reloads; it does **not** publish the three retained MQTT topics itself, and it
relies on your existing Home Assistant automation layer (and the reload to pick
it up) rather than creating the automation through the REST API. Choose SSH when
the device cannot be reached over the HA REST API, and API upload when it can
(the API path is fully verified end-to-end).

## Rollback

- **API upload:** because the automation is create-or-update by a fixed id, deploy
  replaces it. To roll back, re-generate from a known-good configuration and
  deploy again, or restore the previous automation in Home Assistant's automation
  editor. The retained MQTT topics are re-published on every successful deploy, so
  the device re-syncs to the new state on reconnect.
- **SSH upload:** the deployed file replaces `settings.remote_path`
  atomically. Keep a backup of the previous file; to roll back, `scp`/`sftp` your
  backup back to `remote_path` and re-apply the fixed reload
  (`ssh_reload_strategy: core_restart` → `ha core restart`).
- **Local previews:** the live-deployment gate is hash-locked. Run
  `scripts/render_live_ha_preview.py --config <config> --output build/live-ha-preview`
  to produce `automation.json`, `automation.yaml`, `mqtt-publications.json`, and
  a `release.sha256`, approve that digest, then `scripts/apply_live_ha_preview.py`.
  **Operator note:** after a live apply, the automation read-back and the actual
  retained publications can drift from the rendered preview; re-render (regenerate
  `mqtt-publications.json`) using the same config to keep the digest, preview, and
  live broker in lock-step, then re-verify retained payloads with
  `scripts/verify_live_mqtt.py`. That live-broker verifier requires the
  `paho-mqtt` package (it is listed in `requirements-dev.txt`) and `jsonschema`;
  it reads the broker endpoint from the git-ignored `config.json`.

MicroPad is not safety-critical; always keep the Home Assistant web UI as the
authoritative control surface and verify deployment behaviour on your own
installation.

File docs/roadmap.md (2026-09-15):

# MicroPad — feature roadmap / backlog (2026-09-15)

> AI-assisted development — firmware, HA automation, config generator and docs were created with AI (LLM) help, reviewed and tested by the author. Provided as-is, without warranty; verify on your own hardware, don't use for safety-critical applications.

Working document for choosing the next work packages. Every item carries its effort, risk and
whether it can be validated without the physical pad; "done" means the definition of done at the top
of each phase was actually met, not that code exists.

**Status: Phase A complete (A1–A9); B1–B5 and B7 shipped; C1 (long press), C2 (diagnostics) and
C4 (cover, fan, input_boolean, lock) shipped.** See `docs/status.md` for the current ship list and
how each item was verified. Next slice: B8 (post-upload read-back), C6 (icon set), C7 (portal
factory reset) — or the items marked "blocked" once their open decision is made.

**How to read it**
* **Effort:** S ≤ 2 h · M ≈ half a day · L ≈ 1–2 days · XL = 3+ days (incl. tests/docs).
* **Risk:** low = host-testable, no hardware · med = touches a pinned contract or the core data model ·
  high = only verifiable on the physical pad.
* **HW** = needs the real MicroPad (or someone pressing keys on it) before it counts as done.
* **DoD** = definition of done; every item ends in the existing gates: host core binary +
  `test_firmware_static.py` + `scripts/test_firmware_contract.sh` + the 3-FQBN compile matrix
  (+ browser/backend suites for UI work), no push without approval.

Current baseline for reference: flash 1 006 747 B (76 %), static RAM 173 364 B (52 %), free DRAM
154 316 B, live catalog 118 344 B, callback frame 6 704 B, loop stack 16 KiB.
Measured with a real `arduino-cli` build of the pinned hwcdc/PSRAM FQBN: A1–A3 +1 004 B flash /
0 B RAM, A4's shared snapshot builder +36 B, C2's diagnostics +768 B flash / +40 B RAM, C1's long
press +184 B flash / +48 B RAM. Flash is not the constraint: 23 % of the partition (302 973 B) is
free.)

---

## Shipped (2026-09-15)

**A1 — contract is the single source of truth.** `contracts/mqtt-contract.json` gained
`action_meta`, `item_type_meta`, `caps` and the sixth topic; `scripts/generate_contract.py`
(`--write` / `--check`) renders `firmware/protocol_contract.h` and the browser's key-ID/version
block, and `micropad.constants` / `micropad.ui_meta` derive from the JSON at import time.
Drift gates: `scripts/test_firmware_contract.sh`, the new
`tests/integration/test_mqtt_contract.py` block (generated sources, enum order, firmware caps,
descriptor table, backend item rules, `/api/meta`), and `tests/test_frontend_delivery.py` (browser
fixture vs live meta). The codegen `--check` runs inside the `mqtt-contract` CI stage, so no new CI
stage (the stage list is a pinned release contract) was needed.
*Deviation from the plan:* Python is derived at import (no generated file) — one less artefact to
keep in sync; the C++ header and the JS block still need codegen because they cannot read JSON.

**A2 — one descriptor row per item type.** `ItemTypeDescriptor` + `ITEM_TYPE_DESCRIPTORS` in
`micropad_core.h/.cpp` (`{type, defaultAction, editable}`) now feeds `actionForSelectedItem`; the
contract's `item_type_meta` feeds `models.py` (entity/target-page rules), `generator.py`
(reflected/state-column types), `/api/meta` and the editor's `draftErrors`. Magic table sizes
(`kActionNames[21]`, `kItemTypeNames[11]`, the loop-stack literal, `items max_length=20`) replaced
by enum-bounded/contract constants. Room for the item-type row: this is the baseline for C4.
*Deviation:* the firmware row carries only what the firmware uses (`defaultAction`, `editable`);
HA domains stay in `item_type_meta`, and a test asserts the two agree.

**A3 — the pad advertises its own limits.** Every connection publishes the retained
`micropad/device` payload (`fw`, `contract`, `caps` — all read from the firmware's own constants,
`…_CAP - 1` for the string fields). `/api/meta` now exposes `limits`, `caps` and `item_type_meta`
so the configurator can warn before the pad clips a value or drops a catalog.
*Deviation:* the topic is `micropad/device` (a sixth contract topic) instead of `micropad/hello`;
the payload is flat `caps` rather than top-level fields. Backend-side *enforcement* (refusing to
publish) is still A6/B3 — today the data is exposed, the warning UI is not built yet.

**Still to do from this slice:** A6's config-lint gate and B2/B3 (budget meters + callouts) are the
natural follow-ups that consume A3's caps.

**A4 — firmware-in-the-loop core.** `tools/micropad_sim.cpp` (+ `scripts/build-simulator.sh`,
plain g++) compiles the shipped core into a host binary that answers "what does the panel render
for this page / what does this key do" in one JSON object: the row window, the prim list from
`layoutNormalUi`/`layoutPortalUi`, `would_reject` + `findings` for clipped or refused fields, and
the resolved binding/item action for a pressed key. The sketch and the simulator now share one
snapshot builder (`fillPageSnapshot()` moved from the sketch into the core), so the row window
cannot differ between panel and preview. Cost: +36 B flash, 0 B RAM.
*Honest limitation:* the JSON→struct decoding still lives in the sketch (ArduinoJson), so the
simulator reads a tiny documented directive format instead. Moving the payload decoder into the
core remains a named follow-up (it would also remove ArduinoJson from the hot path) — see B11 below.

**A5 — `/api/simulate`.** POST a page (draft accepted) + pad state, get the core's model back.
`src/micropad/simulator.py` owns the wrapper; a missing binary answers 503 `simulator_unavailable`
and rejected input answers 400 with the offending field, so the UI never shows an invented panel.

**B1/B2/B3 — the website.** `static/js/panel-preview.js` draws the prim model as SVG at hardware
resolution (296x128, monochrome, FreeMono) with a "show setup portal" toggle; it contains no layout
knowledge — the geometry is whatever the firmware returns. `static/js/analysis-panel.js` renders the
budget meters (page/catalog/MQTT buffer/pages/items) and the findings list from `/api/lint`
(`src/micropad/lint.py`), which combines the contract caps with the real generator's byte sizes and
reports `field_clipped` (warning) vs `identifier_too_long` (blocks publish) with a `where` path.
Tests: `tests/test_simulator.py` (12, including a gate that the recorded browser fixture still
matches the current core), `tests/browser/test_preview_and_budgets.py` (3, drawing a recorded
real-core model), plus a browser-fixture-vs-`/api/meta` drift test.

**A6 — the same analysis without the browser.** `scripts/lint_config.py` exposes `micropad.lint`
on the command line (exit 0 publishable / 1 findings / 2 unreadable, `--strict`, `--json`), and the
`firmware-host` CI stage now also builds and runs `tests/firmware/test_core.cpp` and
`tests/firmware/test_firmware_static.py`. Those two ran *only* on a developer machine before: the
stage called `scripts/test_firmware_contract.sh`, which covered the header/contract checks alone, so
a core regression could reach review unnoticed. The stage takes ~1 s longer.

**C1 (long press) — the first gesture.** A hold on the row under the cursor dispatches that item
type's **alternate action** (light/switch: turn *off* instead of toggling); every other type ignores
the hold. Deliberately storage-free: the alternate comes from a new `alternate_action` column in
`item_type_meta`, so no per-binding gesture fields were added (that would have cost ~1.8 KB of RAM
and a keymap-schema change for the same user-visible behaviour). The core owns the timing
(`LONG_PRESS_MS` = 600 ms from the *debounced* press, emitted once per hold as `Edge::LongPress`),
the dispatch reuses the ordinary action path — so the MQTT event, the HA automation and the payload
schemas are untouched. The wake press is exempt: holding the key that woke the pad never fires the
gesture (a host test caught that case). Cost: +184 B flash, +48 B RAM.
*Still open from C1:* double-press and encoder acceleration — both need a parameter or a binding
field (a "repeat N" / second action per key), i.e. a contract decision rather than more core code.

**C2 — diagnostics.** The pad publishes the retained `micropad/diag` payload on every connect and
then once a minute while connected: uptime, MQTT connects, catalog/page/keymap parse accept+reject
counters, dropped events (queue full) and the heap high-water mark. `Diagnostics` +
`formatDiagnostics()` live in the core (host-tested byte for byte, incl. the worst-case length), the
sketch only bumps counters and publishes from a 256-byte stack buffer — no ArduinoJson document, so
the format is testable on the host and costs no heap. Cost: +768 B flash, +40 B RAM. The topic was
added by editing the contract and running the codegen — the A1 foundation doing its job.

**A7 — golden files.** `tests/test_golden_output.py` freezes the automation YAML and the three
published payloads for `tests/fixtures/golden_config.json` (3 pages, category with target page,
editable number, scene, per-page keymap override) into `tests/fixtures/golden/` as real files, so an
intended change produces a reviewable diff. Regenerate with `MICROPAD_UPDATE_GOLDEN=1`. The unit
tests assert properties, so a generator refactor could change published bytes silently before this.
Also verified negatively: mutating one golden key fails two tests.
*Note:* the captured artifacts are exempt from the "every file carries the AI notice" rule (same
reasoning as the machine-generated lock file) — a notice field would change the payload under test.

**A8 — pre-commit gate.** `.githooks/pre-commit` runs ruff, mypy, the contract drift check and the
firmware host checks (~4 s). Deliberately not enabled automatically: the hook changes the behaviour
of every other session/agent in the clone, so `git config core.hooksPath .githooks` is an explicit
operator decision (documented in `docs/developer.md`).

**A9 — developer guide.** `docs/developer.md`: recipes the codegen cannot express (add an action /
item type / topic / page template), the generated-vs-derived table, the gate table with timings, the
golden regeneration workflow, and the conventions tests enforce (enum order = wire order, caps mirror
the contract, clipped vs rejected fields, manifest completeness, the AI notice, the no-secrets gate).

**B5 — page generation from the entity cache.** `/api/entity-groups` reports the cached domains with
counts and their item type (from `item_type_meta`); `/api/build-pages` returns page drafts — one page
per domain, split at 20 entities, stopping at the 24-page ceiling, `number` items carrying the
entity's real min/max/step, names/states/units clipped to the firmware caps with every shortening
reported in `notes`, and non-pageable domains listed in `skipped`. The UI (`page-generator.js`) adds
one button per domain plus "all pageable domains" and a cache-refresh button; drafts are appended to
the open configuration, which autosaves like any other edit. Room grouping is deliberately not
offered: `/api/states` carries no area information, so "one page per room" would need the area
registry (WebSocket API) — a separate decision (B12 below).

**B12 (new)** — area/room grouping for page generation: needs the HA area registry (WebSocket API or
`/api/config/area_registry/list` with a long-lived token), i.e. a new credential/API surface.
Effort M, risk med (new HA API surface), decision needed.

**B11 (new)** — move the payload decoding into the core so the sketch and the simulator share the
JSON→struct step as well (removes the last mirrored logic and ArduinoJson from the hot path).
Effort M/L, risk med (device-facing path), needs a hardware pass.

---

## Phase A — make "adding a feature" cheap (foundations, no hardware)

| ID | Item | Why | Effort | Risk |
|---|---|---|---|---|
| **A1** | **Contract codegen** — `scripts/generate_contract.py` emits `protocol_contract.h`, the Python constants and `static/js/contracts.js` from one source (`contracts/mqtt-contract.json`), plus a CI drift check | Actions/item types/key ids are hand-maintained in 5 places today; this is the single biggest drag on new features | M | low |
| **A2** | **Item-type descriptor table in the core** — one host-tested row per type: `{ha_domain, default_action, editable, has_value, needs_target_page, unit_hint}`; `actionForSelectedItem`, the generator and the UI read the same table | A new item type becomes one row instead of edits in 6 files | M | med |
| **A3** | **Firmware capability handshake** — pad publishes retained `micropad/hello` (`fw_version`, `contract_version`, `mqtt_buffer_bytes`, field caps, `max_pages`, `max_items`) | Lets the backend refuse a config the device cannot parse and lets the UI say "firmware too old"; closes the silent-drop class we just fixed | M | low |
| **A4** | **Firmware-in-the-loop core CLI** — compile `micropad_core.cpp` into a small host binary (`parse page/keymap JSON → apply key event → emit prim model`), used by tests *and* by the configurator | Preview, lint and simulate all run the **real** firmware logic instead of a re-implementation | M | low |
| **A5** | **`/api/simulate`** — feed a page payload + a key event, return the prim model, the resulting event queue and whether the payload would be clipped/rejected | Turns "does this config work on the device?" into a button; basis for the preview in B1 | S–M | low |
| **A6** | **Config lint CLI + CI** — `scripts/lint_config.py config.json` = validate → generate → byte budgets → real-core parse → exit non-zero with the reason; add it (and the host core/static tests) to CI plus a **contract-drift gate** | Catches an unpublishable config before it reaches the broker | S | low |
| **A7** | **Golden-file tests for generated output** — snapshot the generated automation YAML + retained payloads per example config | A generator refactor can currently change published payloads silently | S | low |
| **A8** | **Pre-commit hook** (ruff, mypy, host core, static firmware tests) | Cheap to add, removes the "which suite do I run" friction | S | low |
| **A9** | **Developer guide "add an action / item type / page template"** (`docs/developer.md`) with the checklist the codegen can't cover | Makes the process explicit for future sessions | S | low |

**Suggested first slice: A1 + A2 + A3** (one coherent "contract is the source of truth" step).

## Phase B — config website (no hardware needed)

| ID | Item | Why | Effort | Risk |
|---|---|---|---|---|
| **B1** | **Faithful panel preview** (SVG from the prim model: 296×128, FreeMono metrics, title clip 22, value column 12, cursor, scrollbar, portal view) | "What will the panel look like" is asked every single time; there is no preview at all today | M | low |
| **B2** | **Budget meters + limits in `/api/meta`** (page 8192, catalog 16000 vs 16384 buffer, items ≤ 20, pages ≤ 24, field caps name/title/state 32, entity 96) | The UI currently cannot warn about clipping or an oversized catalog | S | low |
| **B3** | **"What the device changes" callout** (clipped values, dropped pages, entity mismatch) on top of A5 | Makes the silent behaviour of the firmware visible while editing | S | low |
| **B4** | **Hardware-shaped keymap editor** — clickable 3×4 matrix + encoder wheel, inherited-vs-overridden per page, drag action chips | Keymaps are edited as text rows today; the physical layout is the mental model | M | low |
| **B5** | **Entity-first page generation** — pick areas/domains/favourites → generated pages ("one page per room", lights/scenes/media/Spotiify) on top of the template picker | Adding a page becomes a 3-click operation | M | low |
| **B6** | **Live device mirror + remote key injection** — backend subscribes to `micropad/event`/`power`, UI shows the pad state and adds "press r0c3" buttons | Test a keymap without touching the pad; would have made the last debugging session much faster | M | low |
| **B7** | **Config history / undo / diff-before-apply** — versioned snapshots (the approval-hash flow already exists) + one-click rollback | Recover from a bad config in seconds | M | low |
| **B8** | **Apply read-back verification** — after upload, re-read the retained topics from the broker and compare with the generated payloads (`scripts/verify_live_mqtt.py` is the basis) | Proves the broker really holds what was published | S–M | low |
| **B9** | **UI polish**: German/English switch, dark mode, keyboard navigation, mobile layout | The UI is English-only and desktop-ish | S–M | low |
| **B10** | **Diagnostics tab** — render A3/C2 data: firmware version, uptime, heap, reconnect count, rejected payloads, last error | Field debugging without a serial console | S | low |

## Phase C — device features (firmware/HA, host-testable)

| ID | Item | Why | Effort | HW |
|---|---|---|---|---|
| **C1** | **Gesture layer in the core**: long-press, double-press, hold-to-repeat, encoder acceleration | 14 inputs → ~40 actions with no hardware change; purely host-testable | M | – |
| **C2** | **Diagnostics topic** (`micropad/diag`, retained): uptime, min free heap, MQTT reconnects, parse rejections, stack high-water mark, queue overflow | We just removed a lot of silence; this makes the next issue visible | S–M | – |
| **C3** | **Notification service** — HA publishes `micropad/notify`, the pad shows a banner row until dismissed (any key) | Turns the pad into an output device, not just an input | M | – |
| **C4** | **New item types**: `cover` (blinds), `climate` (setpoint), `select`/`input_select` (encoder cycles options), `fan`, `lock`, `input_boolean` | Depends on A2: each is one descriptor row + generator mapping + UI entry | M per 2–3 types | – |
| **C5** | **Dimmer interaction** — `edit` on a light steps brightness (5 % steps via the encoder), optimistic state | The encoder currently only scrolls; a dimmer is the most-requested missing interaction | M | – |
| **C6** | **Icon/glyph set** in the prim model (wifi-error, lock, play/pause, thermometer, battery, brightness) | Cheap (~200 B flash), lifts the UI a lot | S | – |
| **C7** | **Portal: factory reset + connection result + OTA upload** — "forget settings / erase NVS", show the Wi-Fi/MQTT result on the page after saving, and accept a firmware `.bin` behind the portal (`Update.h`) | No more USB-tethering, and no bricked-feeling device after a bad save | M (reset/test) / L (OTA) | OTA yes |
| **C8** | **Per-page refresh policy** — optional periodic partial refresh for sensor/dashboard pages (e.g. every 5 min) + a dashboard page template | Sensor values are static until the backend republishes; a wall display wants fresh numbers | M | – |
| **C9** | **Elapsed/back-stack indicator** in the title strip (breadcrumb depth) + long-press context menu on a row (toggle/pin/edit) | Better orientation in deep page trees | S–M | – |
| **C10** | **Multi-device support** — per-device pages/keymaps (client ids already derive from the MAC) + a device picker in the UI | Two pads, different keymaps, one configurator | L | – |

## Phase D — hardware-dependent (needs the pad + a decision)

| ID | Item | Note | Effort |
|---|---|---|---|
| **D1** | **Battery gauge** — ADC divider → battery % in the retained `micropad/power` payload, low-battery icon | Needs a PCB revision (Rev C) before it can be built | M + PCB |
| **D2** | **Wall-dashboard mode** — timer wake → refresh a dashboard page → deep sleep, with a battery/no-USB profile | The sleep path and the render mailbox already exist; battery life depends on the panel refresh cost | L |
| **D3** | **Encoder push button** (if the part has one) / additional inputs | Verify the PCB and the encoder datasheet first | S–M + HW |

## Phase E — deliberately not doing (keeps the project clean)

* A second protocol version or a compatibility matrix beyond A3's handshake.
* Any cloud dependency; the pad talks to its own broker and nothing else.
* A scripting/template engine inside the firmware (RAM-bound: live catalog is already 118 KB).
* Bigger event queue/buffers — the contract limits are pinned and the RAM cost is real.
* OTA *without* the portal (an unauthenticated update path is a security regression).

## Mapping to the earlier chat list (nothing lost)

* "One source of truth + codegen" → **A1** · "Item-type descriptor table" → **A2** ·
  "Capability handshake" → **A3** · "Firmware-in-the-loop preview" → **A4/A5**.
* "Faithful panel preview" → **B1** · "Budget meters" → **B2/B3** · "Hardware-shaped keymap editor" → **B4** ·
  "Entity-first authoring" → **B5** · "Live device mirror + key injection" → **B6** ·
  "Config history/undo/diff" → **B7**.
* "Gestures" → **C1** · "OTA via portal" → **C7** · "Diagnostics topic" → **C2** ·
  "Battery gauge" → **D1** · "Icon/glyph table" → **C6** · "Multi-device" → **C10**.

## Proposed order (my recommendation)

1. **A1 + A2 + A3** — contract single-source + handshake (unblocks everything else).
2. **A4 + A5 + B1 + B2 + B3** — real-core preview + budget meters on the website.
3. **C1 + C2** — gestures and diagnostics (device value, host-testable).
4. **B4 + B5 + B6** — keymap editor, page generation, live mirror.
5. **C7 (portal)** — factory reset + OTA.
6. Everything else as it fits; **D*** only with hardware on the desk.

Pick the items (or a different order) and I start with the first two or three.

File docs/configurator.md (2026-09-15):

# MicroPad Configurator

> AI-assisted development — firmware, HA automation, config generator and docs were created with AI (LLM) help, reviewed and tested by the author. Provided as-is, without warranty; verify on your own hardware, don't use for safety-critical applications.

The configurator is the Flask web app (`src/micropad/app.py`) that validates your
configuration, edits pages and key maps, discovers Home Assistant entities, and
generates or uploads the automation. It talks to the repo over these endpoints:

| Endpoint | Purpose |
|---|---|
| `GET /` | web UI (`src/micropad/templates/index.html`, `static/js/*`) |
| `GET /healthz` | liveness probe → `{"ok": true, "service": "micropad-configurator"}` |
| `GET/POST /api/config` | read / validate-and-save configuration |
| `POST /api/validate` | validate without saving |
| `GET /api/meta` | contract version, key IDs, actions, item types **and their descriptors** (`item_type_meta`), payload ceilings (`limits`), device caps (`caps`), templates, default keymap |
| `GET /api/generate` | generated automation YAML + retained MQTT payloads |
| `POST /api/lint` | payload budgets (per page + catalog) and "what the device changes" findings for a candidate config |
| `POST /api/simulate` | the panel's prim model for one page (or the setup portal), rendered by the firmware core |
| `POST /api/ha/test` | test Home Assistant auth |
| `GET /api/ha/entities` | discover and cache Home Assistant entities |
| `GET /api/entity-groups` | cached domains with entity counts and the item type each maps to |
| `POST /api/build-pages` | page drafts built from cached entities (nothing is saved) |
| `POST /api/upload/api` | deploy via Home Assistant REST API |
| `POST /api/upload/ssh` | deploy via SFTP/SSH (see `docs/home-assistant.md`) |

## Configuration history

Every save leaves a revision next to the configuration file
(`config.json.history/<UTC stamp>-<content hash>.json`), so a bad edit is a restore
instead of a re-typing session:

- `GET /api/history` lists the revisions (metadata only, newest first), `GET
  /api/history/<id>` returns one revision with the structural diff against the
  current configuration, and `POST /api/history/<id>/restore` makes it current again
  through the normal validated save path.
- Revisions are **content-addressed**: an unchanged document is not recorded, so the
  UI's autosave does not bury the interesting revisions, and restoring a state that
  is already in the history adds no duplicate. The newest 20 are kept.
- The diff is structural ("page \"office\" added (3 items)", "global keymap r0c0:
  home -> back") rather than a text diff, and it compares secrets without printing
  them: a changed Home Assistant token reads `ha_token: changed`.
- Snapshot ids are validated against an exact pattern before any file is opened, so
  a revision id from the browser can never escape the history directory.
- Snapshots contain the same credentials as the configuration itself: they are
  written with mode 600, live beside the config file and are git-ignored. They are
  never part of the release manifest.

## Keymap editor

The key editor is laid out like the hardware: three rows of four keys next to the
encoder, in the same arrangement the operator's fingers find on the pad. Each key
face shows its id and the action that key currently performs, and `data-binding-origin`
marks where that action comes from — `global`, `inherited` (from global or an
ancestor page) or `override` (this page's own) — so a page's whole keymap is readable
without clicking through fourteen keys. Selecting a face loads it into the binding
panel below, which is the only place a binding is edited, and the scene remains the
single source of the effective action (`keymap-model.js`).

## Page generation

"One page per domain" is one click. `GET /api/entity-groups` reports the domains in
the cached entity list with their counts and the item type each maps to (that mapping
comes from the contract's `item_type_meta`, so it cannot drift from the firmware).
`POST /api/build-pages` turns the cache into page drafts: one page per domain, split
when a domain holds more entities than a page takes (20), named "Lights" / "Lights 2",
with item types that match the entity domains, `number` items carrying the entity's
real min/max/step, and names/states/units clipped to the firmware's field caps — every
shortening is reported in `notes` rather than applied silently. Pages stop at the
pad's 24-page ceiling, and drafts are appended to the open configuration (which
autosaves like any other edit); publishing to the pad stays the normal deploy action.
Domains with no item type are listed in `skipped`, never dropped quietly.

Rooms are not offered yet: the REST endpoints the configurator uses (`/api/states`)
carry no area information. Area grouping would need the area registry (WebSocket API),
which is a separate decision.

## Panel preview and budgets

The editor shows the panel as the device will draw it. The picture is not redrawn
in JavaScript: `POST /api/simulate` runs `tools/micropad_sim.cpp`, which compiles
the shipped core (`firmware/micropad_core.cpp`) and answers with the core's prim
model for the page (296x128, FreeMono metrics, title/value clipping, selection
cursor, scrollbar, status icons) or for the setup portal view. Build the tool once
with `./scripts/build-simulator.sh`; when it is missing the endpoint answers 503
`simulator_unavailable` and the UI says so instead of showing an invented panel.

`POST /api/lint` reports the byte budgets and the changes the device would make:

- per-page payload bytes against 8192, the catalog against 16000 and against the
  pad's 16384-byte MQTT buffer (a catalog over the buffer is dropped by the MQTT
  client without an error), pages against 24 and items against 20;
- `field_clipped` warnings for display fields (title/name/state/unit) that exceed
  the firmware's 32-character budgets, and `identifier_too_long` errors for
  `page_id`/`entity`/`target_page`, which make the pad discard the whole payload.

The same analysis is available without the web UI, for CI or a pre-deployment
check:

```bash
python3 scripts/lint_config.py config.json          # 0 publishable, 1 errors, 2 unreadable
python3 scripts/lint_config.py config.json --strict # warnings fail too
python3 scripts/lint_config.py config.json --json   # machine-readable
```

The limits and caps come from `contracts/mqtt-contract.json` — the same values the
pad advertises on its retained `micropad/device` payload — and the byte sizes come
from the real generator, so the meters cannot drift from what a deployment
publishes. `docs/firmware.md` describes the firmware side.

Configuration is stored in `config.json` (git-ignored local) or the path in
`MICROPAD_CONFIG_PATH`. Secrets (`ha_token`, `ssh_key`) are redacted from every
public response — only `ha_token_configured` / `ssh_key_configured` booleans are
exposed. All placeholder values used in this documentation are neutral
(`192.168.0.100`, user `micropad`, password `replace-me`).

## Authentication

Sensitive API routes are fail-closed. The admin secret comes only from the
`MICROPAD_ADMIN_SECRET` environment variable (in production, the optional
`EnvironmentFile` `/etc/micropad/admin.env` described in `docs/deployment.md`):

- `GET /healthz` and `GET /api/meta` are anonymous and expose no sensitive data.
- With a secret configured, every other `/api/*` route requires
  `Authorization: Bearer <secret>` (constant-time comparison). Without a
  configured secret, sensitive routes are served to loopback clients only, and a
  non-loopback bind refuses to start — an unauthenticated public endpoint cannot
  come up silently.
- State-changing requests from non-loopback clients also require the
  `X-Requested-With: XMLHttpRequest` cross-site guard.
- The browser holds the secret in `sessionStorage` only (never in the URL, the
  persisted config, logs, or generated files) and sends it as a request header.
  On a `401` it shows the sign-in dialog; entering the secret re-loads the app.

Use HTTPS (reverse proxy) for remote `ha_url` values; `http` is accepted only as
a local-trust-network value such as `http://homeassistant.local:8123`.

## Pages editor

A configuration contains up to 24 pages. Each page has an id (a normalized
lowercase slug), a title, an optional parent (for navigation), up to 20 items,
and a per-page key-map override. Item types are: `category`, `light`, `switch`,
`script`, `button`, `scene`, `sensor`, `media_player`, `number`, `cover`, `fan`,
`input_boolean`, `lock`, `settings`, and `back`. A `category` item requires a
`target_page`; entity-backed item types require an entity in the matching domain
(`light.foo` for a `light`, etc.). Tapping a `cover`/`fan`/`input_boolean` toggles it
and holding turns it off; a `cover` has no hold action (the cover integration has no
turn_off service); a `lock` locks on tap and unlocks on hold, because the lock
integration has no toggle service.
Editable starter templates (Spotify, Discord, Lights, generic media) are offered
by the pages editor.

## Key editor

Every input maps to an action. The fourteen key IDs are fixed by the contract:
`r0c0, r0c1, r0c2, r0c3, r1c0, r1c1, r1c2, r1c3, r2c0, r2c1, r2c2, r2c3, enc_up,
enc_down`. The global key map must contain all fourteen in canonical order; a page
may override any subset. Actions (from `src/micropad/ui_meta.py`):

- **Navigation:** `enter`, `back`, `home`, `navigate`, `keymap`.
- **Scrolling:** `scroll`, `scroll_up`, `scroll_down`.
- **Device:** `toggle`, `on`, `off`, `press`, `edit`, `confirm`.
- **Media:** `volume_up`, `volume_down`, `media_next`, `media_prev`.
- **System:** `settings`, `get_all_pages`, `none`.

`navigate` and `keymap` take a `target_page`; the device actions (except `none`,
`settings`, `get_all_pages`) take an `entity` argument.

## Entity discovery

`GET /api/ha/entities` calls Home Assistant's entity API with the stored token,
returns the discovered entities, and caches them in `entity_cache` so the UI can
autocomplete entity ids. Discovery requires a configured `ha_url` and `ha_token`;
**TLS verification defaults to on** (`verify_tls: true`). Entities are matched for
editing against the item-type domains, and the generator reflects current state
(light switch state, number value/min/max/step, media volume, sensor unit) into
generated retained payloads whenever the cached state is concrete. Unknown or
`unavailable` states are left alone rather than guessing.

## Validation

Validation is strict and real:

- **Model validation** (`src/micropad/models.py`): unknown fields are rejected,
  page-graph cycles/unknown parents are rejected, key maps must use only the
  fourteen known ids, global keys must be exactly the canonical set, item shape
  rules (category needs `target_page`; entity types need a matching-domain
  entity; `min <= max`).
- **Generation validation**: every publishable payload is generated and rejected
  if it exceeds its byte budget (page 8192, catalog 16000, keymap 16380).
- **Template safety**: user-controlled Jinja delimiters (`{{`, `{%`, `{#`) and
  malformed entity ids are rejected before any payload is embedded.
- **Net effect**: `POST /api/validate`, `POST /api/config`, and every upload
  path fail closed (HTTP 422 validation error / 502 upload error) rather than
  shipping a partial or unsafe configuration.

MicroPad is not safety-critical; always keep the Home Assistant UI as the
authoritative control surface.

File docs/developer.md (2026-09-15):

# MicroPad Developer Guide

> AI-assisted development — firmware, HA automation, config generator and docs were created with AI (LLM) help, reviewed and tested by the author. Provided as-is, without warranty; verify on your own hardware, don't use for safety-critical applications.

How to change this project without breaking the parts that are pinned. It answers
the question the codegen cannot: *which files do I touch, and what proves it still
works?* Companion docs: `docs/firmware.md` (device), `docs/configurator.md` (web),
`docs/home-assistant.md` (broker/automation), `docs/security-release.md` (release).

## The one rule

`contracts/mqtt-contract.json` is the only source of truth for the wire protocol:
version, topics, key IDs, actions, item types, the descriptor row per item type,
payload ceilings and device caps. Everything else is either **generated** from it or
**derived at import time**:

| Consumer | How it stays in sync |
|---|---|
| `firmware/protocol_contract.h` | generated — `scripts/generate_contract.py --write` |
| `src/micropad/static/js/contracts.js` (key IDs, version) | generated, same script |
| `src/micropad/constants.py`, `ui_meta.py` | read the JSON at import |
| `firmware/micropad_core.{h,cpp}` enums + caps | asserted by tests (enum order, caps, descriptors) |

So: **edit the contract, run the generator, run the tests.** Never hand-edit
`protocol_contract.h` or the generated block in `contracts.js`.

## Recipes

### Add an action (a new keymap verb)

1. `contracts/mqtt-contract.json`: append to `actions` **at the end** (the firmware
   indexes its name table by enum value, so insertion reorders the wire vocabulary),
   and add a matching `action_meta` row (label, group, argument kind).
2. `firmware/micropad_core.h`: add the enumerator to `enum class Action` in the same
   position; `micropad_core.cpp`: add the name to `kActionNames` in the same position.
3. `python3 scripts/generate_contract.py --write`.
4. Implement the behaviour in the sketch (`applyAction`) and the Home Assistant
   template if it needs a service call.
5. Tests: extend `tests/firmware/test_core.cpp` (`testAllActionsReachDefinedOutcome`
   covers "every action has a defined outcome"), and the generator tests.
   `scripts/test_firmware_contract.sh` compares the header, the JSON and the sketch.

### Add an item type

1. Contract: append to `item_types`, add an `item_type_meta` row
   (`ha_domains`, `default_action`, `alternate_action`, `editable`, `has_value`,
   `needs_target_page`) — `alternate_action` is what a *hold* on the row dispatches
   (`none` when the type has no meaningful second action).
2. Regenerate (`--write`), then add the enumerator + name in `micropad_core.{h,cpp}`
   and one row to `ITEM_TYPE_DESCRIPTORS`
   (`{type, defaultAction, alternateAction, editable}`).
3. Nothing else: `models.py` (entity/target-page rules), `generator.py`
   (reflected/state types), `/api/meta`, the editor's validation and the keymap
   editor read the descriptor rows. A test asserts the firmware table and
   `item_type_meta` agree, so a half-done addition fails immediately.
4. Tests: `testItemTypeDescriptorTable` (host), `test_generator.py` for rendering.

### Add a topic

1. Contract `topics` — `{name, retain}`; `python3 scripts/generate_contract.py --write`.
2. Subscribe/publish it in the sketch via `mp::TOPIC_<KEY>` (never a literal: a static
   test asserts the sketch does not contain the topic strings).
3. Docs: the topic table in `docs/home-assistant.md`; the topic list in
   `tests/firmware/test_firmware_static.py` and `tests/integration/test_mqtt_contract.py`.
4. If Home Assistant must react, extend the automation template **and** the golden
   files (below).

### Add or change a page template

`src/micropad/ui_meta.py` (`page_templates()`). `/api/meta` publishes the list, so
the configurator's template picker and the API test pick it up automatically; the
browser test `tests/browser/test_items_and_entities.py::test_template_cards_create_editable_child_page`
covers the flow end to end. A template that changes a generated payload also needs
the golden update below.

### Change generated output (payloads, YAML)

The exact bytes are frozen in `tests/fixtures/golden/`. Change the generator, then

```bash
MICROPAD_UPDATE_GOLDEN=1 .venv/bin/python -m pytest tests/test_golden_output.py
git diff tests/fixtures/golden/          # review the diff: this is what gets published
```

## The gates

| Command | What it proves | Time |
|---|---|---|
| `scripts/test_firmware_contract.sh` | header↔contract↔sketch, core host tests, 140+ static contract tests | ~2 s |
| `.venv/bin/pytest tests/browser` | the real UI in Chromium against a mocked API | ~30 s |
| `.venv/bin/pytest tests/release` | manifest, notices, public-release audit | ~15 s |
| `.venv/bin/python -m pytest -q` | everything above plus backend/integration | ~70 s |
| `scripts/ci.sh` | the full stage list CI runs (adds the 3-FQBN firmware compile matrix) | minutes |
| `scripts/compile-firmware.sh --one <FQBN>` | one real firmware build + flash/RAM numbers | ~3 min |
| `python3 scripts/lint_config.py <config>` | would the pad store and show this config | <1 s |
| `python3 scripts/generate_contract.py --check` | generated sources are not stale | <1 s |

`scripts/build-simulator.sh` builds `tools/micropad_sim.cpp` (the host binary the
preview and lint use); `tests/test_simulator.py` builds it automatically.

### Pre-commit hook

```bash
git config core.hooksPath .githooks
```

Runs ruff, mypy, the contract drift gate and the firmware host tests before each
commit. It is **not** enabled automatically: enabling it changes the behaviour of
every other session and agent working in this clone.

## Conventions that are enforced by tests

- `protocol_contract.h` and the generated block in `contracts.js` must match the
  contract (`--check`; also asserted from `tests/integration/test_mqtt_contract.py`).
- Firmware `Action`/`ItemType`/`KeyId` enum order **is** the wire order.
- Firmware caps (`…_CAP`, `MAX_PAGES`, `MQTT_BUFFER_BYTES`, `LOOP_TASK_STACK_BYTES`)
  equal the contract's `caps` block, which is what the pad advertises on
  `micropad/device`.
- Display fields clip (name/title/state/unit at 32 chars); identifiers are rejected
  (`page_id`, `entity`, `target_page`). `micropad.lint` and the simulator report
  which of the two applies.
- Every file a deployment publishes must satisfy the JSON Schemas in `contracts/`.
- New files must be added to `release/software-files.txt` (bytewise sorted) — a
  release test compares that manifest with `git ls-files`.
- Every source/doc file carries the AI-assisted-development notice
  (`python3 scripts/audit_notices.py`).
- Never commit real credentials, private IPs, entity lists or keys: the
  public-release audit (`scripts/audit_public_release.py`) is the gate, and
  `release/allowed-public-values.json` lists the only approved placeholders.

## Where things live

```
contracts/          the contract + JSON Schemas (and the audit allowlist in release/)
firmware/           sketch (device I/O, WiFi, MQTT, NVS, portal) + dependency-free core
tools/              micropad_sim.cpp — the core on the host (preview and lint)
src/micropad/       Flask configurator, generator, models, lint, simulator wrapper, static UI
tests/              backend, integration, browser (playwright), firmware, release, cpp
scripts/            toolchain, compiles, gates, codegen, lint CLI, approvals
docs/               this guide, firmware, configurator, home-assistant, deployment, security
```

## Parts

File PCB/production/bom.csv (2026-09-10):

Designator | Footprint | Quantity | Value | LCSC Part #
C1 | CP_Elec_6.3x7.7 | 1 | 220u
C10, C13, C14, C9 | 0805 | 4 | 1uF
C11, C12 | 0805 | 2 | 4,7uF
C15, C8 | 0805 | 2 | 100n
C7 | 0805 | 1 | 10u
D1 | D_DO-201AD_P15.24mm_Horizontal | 1 | 1N5822
D10, D11, D12, D13, D14, D15, D4, D5, D6, D7, D8, D9 | D_SMA | 12 | D
D16 | LED_D3.0mm | 1 | BLUE
D17, D19 | LED_D3.0mm | 2 | GREEN
D18 | LED_D3.0mm | 1 | ORANGE
F1 | 0805 | 1 | 2A
FB1 | 0805 | 1 | BLM21PG220
J10, J11, J12, J9 | SolderJumper-2_P1.3mm_Open_TrianglePad1.0x1.5mm | 4 | Conn_01x02
J2 | USB_C_Receptacle_GCT_USB4085 | 1 | USB_C_Receptacle_USB2.0_16P
J4 | PinHeader_2x03_P2.54mm_Vertical | 1 | Programming header
J5 | PinHeader_1x08_P2.54mm_Vertical | 1 | SPI for E-Ink Display
J6 | JST_B2B-PH-K-S | 1 | B2B-PH-K-S (Battery)
R1, R2 | 0805 | 2 | 5.1k
R10, R11, R8 | 0805 | 3 | 10k
R12 | 0805 | 1 | 100
R13 | 0805 | 1 | 330
R14, R15, R16 | 0805 | 3 | 1,5k
R17 | 0805 | 1 | 1,8k
S1 | SW_500ASSP1SM6QE | 1 | 500ASSP1SM6QE
SW1 | SW_PUSH_6mm | 1 | RESET
SW10, SW11, SW13, SW14, SW3, SW4, SW5, SW6, SW7, SW8, SW9 | SW_Cherry_MX_1.00u_PCB | 11 | SWITCH
SW12 | RotaryEncoder_Alps_EC11E-Switch_Vertical_H20mm | 1 | RotaryEncoder_Switch
SW2 | SW_PUSH_6mm | 1 | BOOT
U1 | VQFN-16-1EP_3x3mm_P0.5mm_EP1.6x1.6mm | 1 | BQ24075RGT
U2 | SOT-23-6 | 1 | USBLC6-2SC6
U3 | ESP32-S3-WROOM-1 | 1 | ESP32-S3-WROOM-1
U6 | SOT-23-5 | 1 | AP2112K-3.3

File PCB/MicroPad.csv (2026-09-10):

Status | Reference | Qty | Value | Footprint | Datasheet
In Liste | C1 | 1 | 220u | Capacitor_SMD:CP_Elec_6.3x7.7
hab ich | C7 | 1 | 10u | Capacitor_SMD:C_0805_2012Metric_Pad1.18x1.45mm_HandSolder
hab ich | C8,C15 | 2 | 100n | Capacitor_SMD:C_0805_2012Metric_Pad1.18x1.45mm_HandSolder
hab ich | C9,C10,C13,C14 | 4 | 1uF | Capacitor_SMD:C_0805_2012Metric_Pad1.18x1.45mm_HandSolder
In Liste | C11,C12 | 2 | 4,7uF | Capacitor_SMD:C_0805_2012Metric_Pad1.18x1.45mm_HandSolder
In Liste | D1 | 1 | 1N5822 | Diode_THT:D_DO-201AD_P15.24mm_Horizontal | http://www.vishay.com/docs/88526/1n5820.pdf
hab ich | D4,D5,D6,D7,D8,D9,D10,D11,D12,D13,D14,D15 | 12 | D | Diode_SMD:D_SMA
hab ich | D16 | 1 | BLUE | LED_THT:LED_D3.0mm
hab ich | D17,D19 | 2 | GREEN | LED_THT:LED_D3.0mm
hab ich | D18 | 1 | ORANGE | LED_THT:LED_D3.0mm
In Liste | F1 | 1 | 2A | Fuse:Fuse_0805_2012Metric_Pad1.15x1.40mm_HandSolder
In Liste | FB1 | 1 | BLM21PG220 | Inductor_SMD:L_0805_2012Metric_Pad1.05x1.20mm_HandSolder
hab ich | J2 | 1 | USB_C_Receptacle_USB2.0_16P | Connector_USB:USB_C_Receptacle_GCT_USB4085 | https://www.usb.org/sites/default/files/documents/usb_type-c.zip
hab ich | J4 | 1 | Programming header | Connector_PinHeader_2.54mm:PinHeader_2x03_P2.54mm_Vertical
hab ich | J5 | 1 | SPI for E-Ink Display | Connector_PinHeader_2.54mm:PinHeader_1x08_P2.54mm_Vertical
 | J6 | 1 | B2B-PH-K-S (Battery) | B2B-PH-K-S:JST_B2B-PH-K-S
hab ich | J9,J10,J11,J12 | 4 | Conn_01x02 | Jumper:SolderJumper-2_P1.3mm_Open_TrianglePad1.0x1.5mm
hab ich | R1,R2 | 2 | 5.1k | Resistor_SMD:R_0805_2012Metric_Pad1.20x1.40mm_HandSolder
hab ich | R8,R10,R11 | 3 | 10k | Resistor_SMD:R_0805_2012Metric_Pad1.20x1.40mm_HandSolder
hab ich | R12 | 1 | 100 | Resistor_SMD:R_0805_2012Metric_Pad1.20x1.40mm_HandSolder
In Liste | R13 | 1 | 330 | Resistor_SMD:R_0805_2012Metric_Pad1.20x1.40mm_HandSolder
In Liste | R14,R15,R16 | 3 | 1,5k | Resistor_SMD:R_0805_2012Metric_Pad1.20x1.40mm_HandSolder
In Liste | R17 | 1 | 1,8k | Resistor_SMD:R_0805_2012Metric_Pad1.20x1.40mm_HandSolder
hab ich | SW1 | 1 | RESET | Button_Switch_THT:SW_PUSH_6mm
hab ich | SW2 | 1 | BOOT | Button_Switch_THT:SW_PUSH_6mm
Amazon | SW3,SW4,SW5,SW6,SW7,SW8,SW9,SW10,SW11,SW13,SW14 | 11 | SWITCH | Button_Switch_Keyboard:SW_Cherry_MX_1.00u_PCB
hab ich | SW15 | 1 | RotaryEncoder_Switch_MP | Rotary_Encoder:RotaryEncoder_Alps_EC11E-Switch_Vertical_H20mm_MountingHoles
In Liste | U1 | 1 | BQ24075RGT | Package_DFN_QFN:VQFN-16-1EP_3x3mm_P0.5mm_EP1.6x1.6mm | http://www.ti.com/lit/ds/symlink/bq24075.pdf
hab ich | U2 | 1 | USBLC6-2SC6 | Package_TO_SOT_SMD:SOT-23-6 | https://www.st.com/resource/en/datasheet/usblc6-2.pdf
hab ich | U3 | 1 | ESP32-S3-WROOM-1 | RF_Module:ESP32-S3-WROOM-1 | https://www.espressif.com/sites/default/files/documentation/esp32-s3-wroom-1_wroom-1u_datasheet_en.pdf
In Liste | U6 | 1 | AP2112K-3.3 | Package_TO_SOT_SMD:SOT-23-5 | https://www.diodes.com/assets/Datasheets/AP2112.pdf

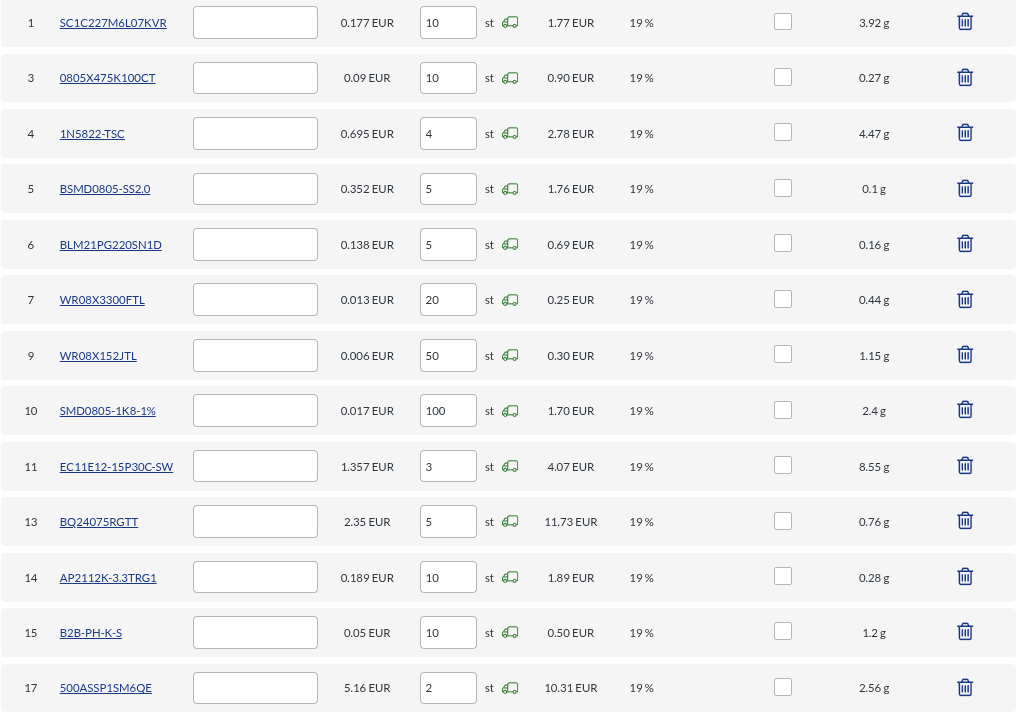
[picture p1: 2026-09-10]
PCB/Parts.png

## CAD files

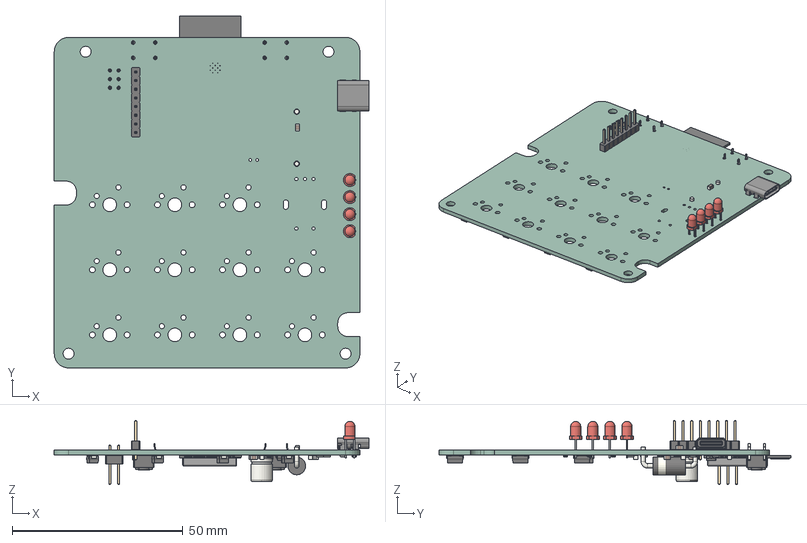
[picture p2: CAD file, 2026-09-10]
PCB/MicroPad.step
92.1 x 103.1 x 18.7 mm
C_0805_2012Metric x 9
PinHeader_1x08_P254mm_Vertical
LED_D3.0mm x 4
USB_C_Receptacle_GCT_USB4085
R_0805_2012Metric x 11
CP_Elec_63x77
D_SMA x 12
PinHeader_2x03_P254mm_Vertical
L_0805_2012Metric
SW_PUSH_6mm x 2
Fuse_0805_2012Metric
SOT-23-6
D_DO-201AD_P15.24mm_Horizontal
SOT-23-5
ESP32-S3-WROOM-1
MicroPad_PCB

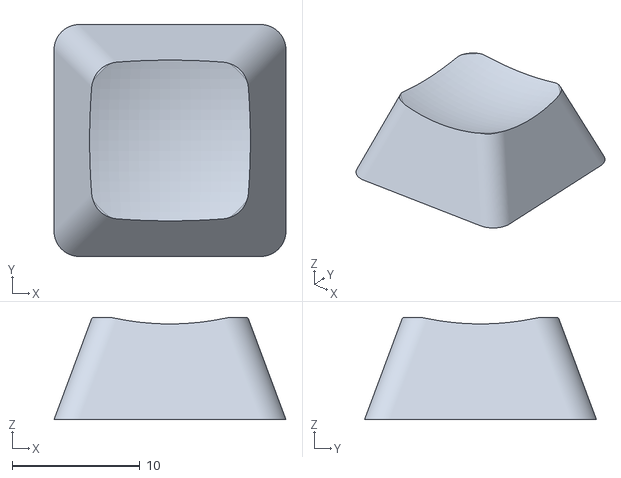
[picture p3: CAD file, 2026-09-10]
STL Files/Keycap.stl
18.2 x 18.2 x 8.00

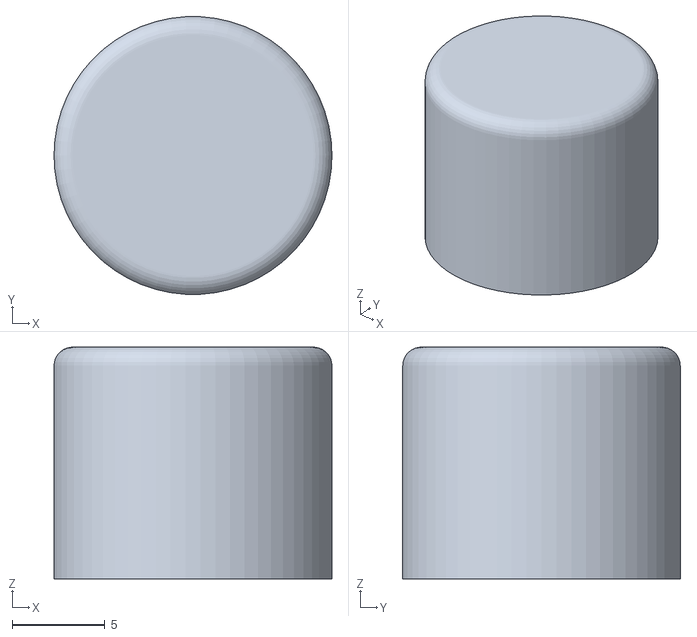
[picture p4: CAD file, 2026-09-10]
STL Files/Knob.stl
15.0 x 15.0 x 12.5

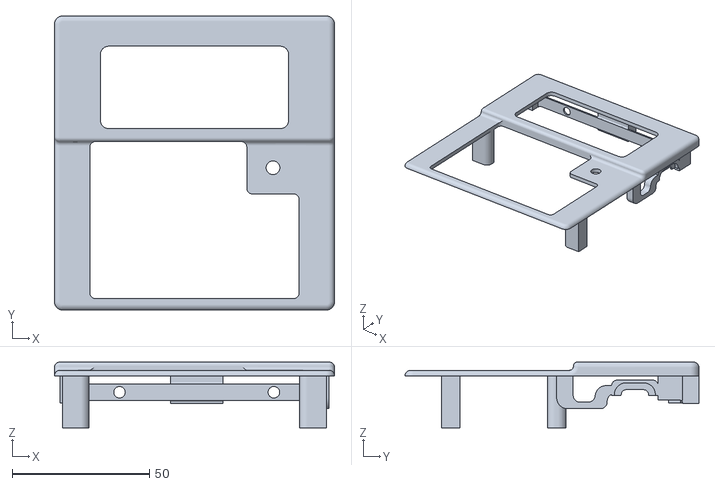
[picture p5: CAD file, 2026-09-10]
STL Files/Top.stl
102.0 x 107.0 x 24.0

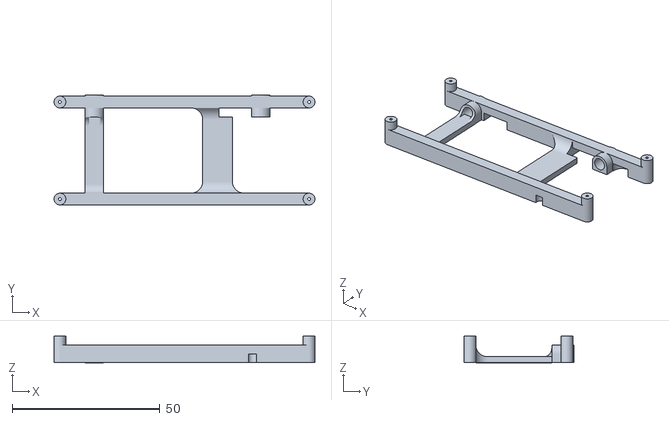
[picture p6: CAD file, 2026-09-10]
STL Files/E-Ink Display mount.stl
88.2 x 37.2 x 9.11

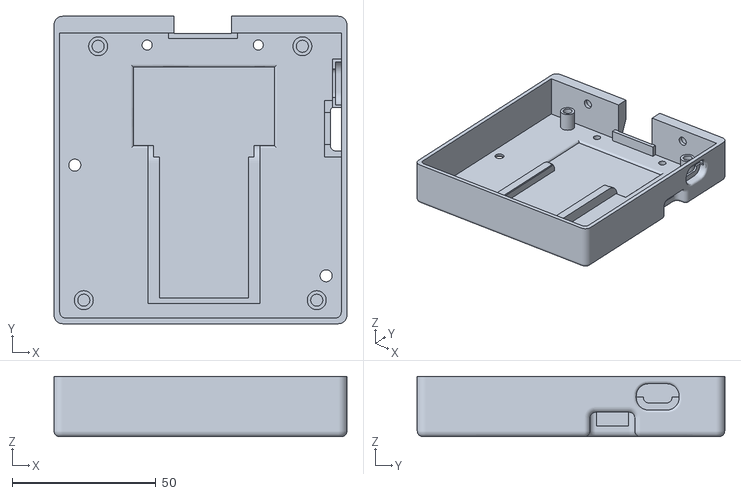
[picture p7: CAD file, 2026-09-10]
STL Files/Case.stl
102.0 x 107.0 x 21.0

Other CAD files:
PCB/MicroPad.stl

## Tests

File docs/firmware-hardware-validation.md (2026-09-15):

# MicroPad Firmware Hardware Acceptance Gate

> AI-assisted development — firmware, HA automation, config generator and docs were created with AI (LLM) help, reviewed and tested by the author. Provided as-is, without warranty; verify on your own hardware, don't use for safety-critical applications.

This document is a repeatable, row-by-row hardware acceptance gate for the clean-room MicroPad firmware. Execution requires a physically attached MicroPad (ESP32-S3 + GxEPD2_290_T94_V2 e-paper + 3×4 matrix + rotary encoder + Li-Ion/BQ24075 + USB-CDC), a running MQTT broker on the documented test namespace, and a Home Assistant instance (or its MQTT bridge) to reconcile state. Every row records an **observed result** and a **pass/fail**; no row may be marked pass from compilation or reasoning alone.

**IMPORTANT — observation rows.** The Final Verification Gate scripted on this build machine (Step 8) has no MicroPad hardware, so *all* acceptance rows below are intentionally left **unchecked** in this committed revision. The compile matrix and static/host suites prove the firmware builds green and the source asserts hold; they prove *nothing* about the physical behaviour. Each hardware row must be executed by an operator on real hardware and marked from direct observation.

> **Hardware validation not executed: compatible MicroPad hardware unavailable**

---

## 1. Executed environment (record at run time)

| Field | Value |
|---:|---|
| Firmware commit SHA | `48b970ac347acbf76fad7f1cfe1f6c4bed190a63` |
| Compile-mode FQBN (matrix row used to flash) | `esp32:esp32:esp32s3:USBMode=hwcdc,CDCOnBoot=cdc,PSRAM=opi` |
| Arduino CLI | 1.5.1 |
| ESP32 (esp32:esp32) core | 3.3.11 |
| GxEPD2 | 1.6.9 |
| ArduinoJson | 7.4.3 |
| PubSubClient | 2.8 |
| Broker test namespace | `micropad` (topics below) |
| Broker host (authoritative config via on-device portal) | `192.168.0.100` (placeholder; real credentials are never in source) |
| MQTT port | `1883` |
| Run start (UTC) | *fill in* |
| Run end (UTC) | *fill in* |
| Operator / notes | *fill in* |

> **Credentials.** Source contains only the neutral placeholders (`192.168.0.100`, user `micropad`, password `replace-me`). Real Wi-Fi/MQTT credentials are entered **only through the on-device captive portal** and stored in NVS; never edit firmware, `micropad_core.*`, scripts, or this document to embed real credentials.

**Flash command (record the exact binary and upload line).**

```bash
# Stage produces build/arduino/MicroPad_HA_Controller/ from the sourced firmware.
./scripts/compile-firmware.sh --one esp32:esp32:esp32s3:USBMode=hwcdc,CDCOnBoot=cdc,PSRAM=opi
# Binary (build-generated path, confirm before upload):
#   build/arduino/MicroPad_HA_Controller/build/.../*.bin
# Upload, e.g.:
#   arduino-cli upload -p /dev/ttyACM0 --fqbn <FQBN> build/arduino/MicroPad_HA_Controller/
```

Record each emitted `micropad/event`, `micropad/power`, and received `micropad/pages/all`, `micropad/page/current`, `micropad/keymap` payload verbatim in the row's notes.

**Carried-in acceptance items.** The following were recorded as Important carries to T14 and are explicit acceptance items, not footnotes:

- **HA template round-trip (retained catalog/current-page).** The backend publishes retained `micropad/pages/all`, `micropad/page/current`, and `micropad/keymap` payloads. If those payloads carry HA template strings (`{{ states(...) }}`, etc.), the firmware parsers reject them because they accept only concrete values. During the MQTT cache row (Step 5b below), capture the **actual retained bytes** of `micropad/pages/all` and `micropad/page/current` on-device and confirm they contain concrete states, not templates. If the retained payloads carry literal `{{ ... }}` templates, the backend publish path must be fixed to publish concrete payloads (or the parsers relaxed) — do not ship templated retained payloads to the firmware.
- **`CONFIG_ARDUINO_LOOP_STACK_SIZE`.** The 16-KiB MQTT callback buffer plus a `Page` (and `Binding[KEY_COUNT]`) on the Arduino loop-task stack exceeds the default 8-KiB loop-task stack. The firmware setup/build must raise `CONFIG_ARDUINO_LOOP_STACK_SIZE` (**sdkconfig/setup bump**, e.g. via `-DCONFIG_ARDUINO_LOOP_STACK_SIZE=32768` in the compile build-properties, or a target-specific `sdkconfig`). Confirm the callback path does not overflow the loop task under a full `micropad/pages/all` payload. *(The compile matrix in Task 13 compiles with the pinned properties; add and verify the stack bump as part of hardware bring-up.)*
- **Loop-task TWDT through light sleep.** A sleep longer than the default loop-task watchdog period can trip a post-sleep watchdog reset. The firmware removes/suspends the render task and the mitigation is `esp_task_wdt_deinit()` at sleep entry with re-init on wake. Row W1 (Step 7) must validate a >60 s sleep explicitly and confirm no watchdog reset after wake.
- **`renderBusy` race window.** Core 0 can claim a render notify between the sleep gate's acquire-load and `vTaskSuspend`, freezing mid-`drawSnapshot`; it resumes post-wake and completes. Row W3 (Step 7) must confirm no ghost pixels appear after resume.

---

## 2. Result notation

- `[ ]` **unchecked** — not executed (no hardware on this build machine), or not yet observed.
- `[x]` **PASS** — observed directly and matching the numbered acceptance criterion.
- `[x]` **FAIL** — observed directly and not matching; record the observed bytes/times in the notes.

---

## Step 4. Matrix and encoder acceptance

### 4.1 Physical inputs (one MQTT event per debounced press, no repeat while held)

For each input, press once and observe exactly one `micropad/event` publish (after the 25 ms debounce), then hold and observe **no further** publish while still held (release emits one `Released` edge only when an action uses the release edge).

| Input | Observed result | Pass/Fail | Emitted `micropad/event` payload |
|---:|---|---:|---|
| `r0c0` | *record* | [ ] | *record* |
| `r0c1` | *record* | [ ] | *record* |
| `r0c2` | *record* | [ ] | *record* |
| `r0c3` (encoder push / enter) | *record* | [ ] | *record* |
| `r1c0` | *record* | [ ] | *record* |
| `r1c1` | *record* | [ ] | *record* |
| `r1c2` | *record* | [ ] | *record* |
| `r1c3` | *record* | [ ] | *record* |
| `r2c0` | *record* | [ ] | *record* |
| `r2c1` | *record* | [ ] | *record* |
| `r2c2` | *record* | [ ] | *record* |
| `r2c3` | *record* | [ ] | *record* |
| `enc_up` | *record* | [ ] | *record* |
| `enc_down` | *record* | [ ] | *record* |

### 4.2 Encoder direction and selection increment

| Criterion | Observed result | Pass/Fail |
|---:|---|---:|
| Clockwise/right detent emits `enc_down` and selection moves `+1` | *record* | [ ] |
| Counterclockwise/left detent emits `enc_up` and selection moves `-1` | *record* | [ ] |
| One encoder step per detent, no repeat while the knob stays in a detent | *record* | [ ] |

### 4.3 Rebinding changes behaviour without reflashing

Prove that a per-page `micropad/keymap` update changes behaviour on the device without a reflash: publish a keymap rebinding `r0c0` (and `enc_up`/`enc_down`) to different actions, observe the new action on the next press/detent, then restore. Record the before/after payloads.

| Criterion | Observed result | Pass/Fail |
|---:|---|---:|
| Rebinding a matrix key changes its action without reflashing | *record* | [ ] |
| Rebinding `enc_up`/`enc_down` changes selection/action without reflashing | *record* | [ ] |

### 4.4 Held key during refresh

During a display refresh (busy), hold a key and confirm the input state change is applied before the refresh completes (input is scanned on Core 1 continuously; the refresh never starves matrix/encoder input).

| Criterion | Observed result | Pass/Fail |
|---:|---|---:|
| Key held during an active refresh changes input state before refresh completion | *record* | [ ] |

---

## Step 5a. Captive-portal acceptance

| # | Criterion | Observed result | Pass/Fail |
|--:|---:|---|---:|
| P1 | First boot with no saved settings shows AP `MicroPad-Setup` with a 16-character password on the panel; the password persists in NVS and the same password appears on portal re-entry | *record* | [ ] |
| P2 | Matrix/encoder remain responsive while the portal is open | *record* | [ ] |
| P3 | Back/cancel exits the portal leaving NVS/settings unchanged (no save, no reconnect to saved network) | *record* | [ ] |
| P4 | Valid save stores Wi-Fi/MQTT credentials, restarts the AP, and reconnects to the station network + broker | *record* | [ ] |
| P5 | Portal restarts (inactivity) near 300 000 ms (≈5 min) of no activity | *record elapsed ms* | [ ] |

---

## Step 5b. MQTT cache and queue acceptance

| # | Criterion | Observed result | Pass/Fail |
|--:|---:|---|---:|
| Q1 | Disconnect the broker, perform discrete actions (navigate, toggle, press) and value edits; reconnect | *record* | [ ] |
| Q2 | After reconnect, the queue flushes **at most four** events per `loop()` pass (via the compile-time debug counter — `#if MICROPAD_DEBUG`), **without CDC output** | *record counter* | [ ] |
| Q3 | Retained `micropad/pages/all` catalog, `micropad/page/current`, and `micropad/keymap` are recovered on (re)connect | *record* | [ ] |
| Q4 | **Carried-in:** capture the actual retained `micropad/pages/all` / `micropad/page/current` bytes and confirm concrete values, not `{{ states(...) }}` templates (see §1) | *record bytes* | [ ] |

---

## Step 5c. Predictive display and resync acceptance

| # | Criterion | Observed result | Pass/Fail |
|--:|---:|---|---:|
| R1 | Immediate local navigation/toggle/number rendering appears without waiting for the broker | *record* | [ ] |
| R2 | Authoritative correction arrives after the 350 ms quiet-period resync when local and authoritative disagree | *record* | [ ] |

---

## Step 6. Display and USB/power acceptance

### 6.1 Refresh policy

| # | Criterion | Observed result | Pass/Fail |
|--:|---:|---|---:|
| D1 | Boot performs a full refresh | *record* | [ ] |
| D2 | Ten partial refreshes followed by an 11th forced full refresh | *record counts* | [ ] |
| D3 | Portal enter and portal exit each perform a full refresh | *record* | [ ] |
| D4 | UI is readable: title/status strip, four item rows, selection cursor, conditional scrollbar, and network-status cell | *record* | [ ] |
| D5 | **No per-row waveform / ghost banding** — every partial refresh is a single full-native-panel `setPartialWindow(0,0,128,296)` window | *record* | [ ] |

### 6.2 USB-CDC host connect/disconnect (enumerated data host)

| # | Criterion | Observed result | Pass/Fail |
|--:|---:|---|---:|
| U1 | Connect an enumerated CDC host: **no** power icon before 1500 ms of stability | *record ms* | [ ] |
| U2 | After the 1500 ms stable window: power icon drawn **and** retained `micropad/power` `{"usb_host":true}` published | *record* | [ ] |
| U3 | While a host is enumerated, light sleep is prevented (no sleep entry) | *record* | [ ] |
| U4 | Host removal is debounced the same 1500 ms: icon removed and `{"usb_host":false}` published symmetrically | *record ms* | [ ] |
| U5 | A charge-only supply (no enumerated host) intentionally follows normal battery sleep behaviour (no power icon, light sleep allowed) | *record* | [ ] |

---

## Step 7. Warm-sleep and reconnect acceptance (battery / no host)

| # | Criterion | Observed result | Pass/Fail |
|--:|---:|---|---:|
| W1 | On battery/no host, light sleep after ≈60 000 ms idle; **carried-in:** validate a >60 s sleep with no post-sleep watchdog reset (TWDT mitigation) | *record ms* | [ ] |
| W2 | No sleep with a held key or an active/pending refresh (`renderBusy` / pending snapshot) | *record* | [ ] |
| W3 | Immediate matrix wake: the waking press becomes the first action; **carried-in:** confirm no ghost pixels from the renderBusy race window | *record* | [ ] |
| W4 | Encoder wake does not lose the next detent after wake | *record* | [ ] |
| W5 | No second sleep for at least 3000 ms after wake (post-wake brake) | *record ms* | [ ] |
| W6 | Wi-Fi association is preserved across sleep/wake (no reassociation) | *record* | [ ] |
| W7 | When sleep exceeded the 15 s MQTT keepalive, the stale socket is invalidated and MQTT reconnects immediately | *record* | [ ] |

---

## 3. Compile / static evidence (this build machine)

Executed and green on this build machine (no hardware):

| Check | Result |
|---:|---:|
| Host C++ behaviour suite (`scripts/test-firmware-host.sh` step 1) | PASS (exit 0, `-Wall -Wextra -Werror`) |
| Static contract suite (`tests/firmware/test_firmware_static.py`) | ALL PASS |
| Compile-matrix wrapper (`tests/firmware/test_compile_matrix.py`) | ALL PASS |
| Compile matrix: HWCDC/JTAG + PSRAM (`USBMode=hwcdc,CDCOnBoot=cdc,PSRAM=opi`) | exit 0 |
| Compile matrix: TinyUSB CDC + PSRAM (`USBMode=default,CDCOnBoot=cdc,PSRAM=opi`) | exit 0 |
| Compile matrix: CDC-disabled / no PSRAM (`USBMode=hwcdc,CDCOnBoot=default,PSRAM=disabled`) | exit 0 |
| `git diff --check` | silent |
| Working tree after the acceptance commit | clean (only the doc + static-test change in the commit) |

The compile and static results do **not** transmit to any hardware row; hardware rows stay unchecked until executed.

---

## 4. Release assertions encoded in `tests/firmware/test_firmware_static.py`

The final static layer pins, in source:

- **Step 1a** — exact pins (CS8/DC40/RST41/BUSY42, rows 47/48/45, cols 21/14/13/12, encoder A10/B11), active-low row drive + restore, and all fourteen bindable input IDs (`r0c0`..`r2c3`, `enc_up`, `enc_down`) with `KEY_COUNT == 14`.
- **Step 1b** — 16384-byte MQTT buffer, 16-slot queue, 4-event flush cap, exactly three subscriptions (`micropad/pages/all`, `micropad/page/current`, `micropad/keymap`), single-pass deserialization, and one first-connect `get_all_pages`.
- **Step 1c** — two fixed render slots (`SLOT_COUNT == 2`), the two independent sleep power guards, 500/1500 ms USB sample/stable window, only the full-native-panel partial window, `display.init(0)`, `DISABLE_DIAGNOSTIC_OUTPUT`, and no unconditional draw in `loop()`.
- **Step 1d** — neutral placeholder credentials only (no real/routable IP, no `mqtt://`/`wss://`), no CDC/Serial writes on any hot path, and the exact AI-assisted notice in **every** firmware, test, script, workflow, config, `.gitignore`, and firmware-document file.

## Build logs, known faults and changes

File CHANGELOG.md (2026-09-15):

# Changelog

> AI-assisted development — firmware, HA automation, config generator and docs were created with AI (LLM) help, reviewed and tested by the author. Provided as-is, without warranty; verify on your own hardware, don't use for safety-critical applications.

Two numbers describe a build. The **firmware version** is what the pad publishes on
`micropad/device` and what the configurator shows; the **contract revision** is the wire
format both sides speak. The clean-room line was merged into `main` through PR #9 and is
released from there; the entries below are grouped by the release they shipped in.

## [Unreleased]

### Fixed

- **A powered pad is no longer treated as battery.** `isPowered()` used
  `static_cast<bool>(Serial)` only, which in the hwcdc build is
  `HWCDC::isCDC_Connected()`: its session flag is set by the HWCDC interrupt
  handler, and that handler is installed **only** by `HWCDC::begin()`. The sketch
  never called it (the core calls `Serial.begin()` automatically for the TinyUSB
  build only, `cores/esp32/main.cpp`: `#if ARDUINO_USB_CDC_ON_BOOT && !ARDUINO_USB_MODE`),
  so `isPowered()` was permanently `false`: the pad counted as battery-powered on
  every cable, slept after 60 s idle, stopped pumping `mqttClient.loop()`, lost the
  15 s keepalive, and the broker dropped it. Detection now uses the USB-serial-JTAG
  host check (`Serial.isPlugged()`, the IDF SOF watchdog) before the session flag —
  the v6 semantics, restored — and `configureCdc()` starts the HWCDC driver. The
  TinyUSB build uses the v6 `tud_cdc_n_connected(0)` arm, and both sleep guards
  additionally honour the debounced `stableUsbHost` state.
- **Repository cleanup:** the `.arduino` toolchain symlink and the
  `src/micropad_configurator.egg-info/` build artifacts that an accidental commit
  added to the tree are removed again, and `.gitignore` ignores both (the
  `*.egg-info/` line had been merged into `*.egg-info/.arduino`). The committed
  symlink pointed at a local `/tmp` toolchain tree, which made the firmware CI job
  fail at the toolchain install step.

## [1.2.0] — 2026-09-15

First release of the clean-room line: 13 commits, and every claim here was measured, not
assumed.

### Added

- **Four item types** — `cover`, `fan`, `input_boolean`, `lock`, each one contract row plus
  one firmware descriptor row plus the Home Assistant service mapping.
- **Long press** — holding Enter dispatches an item's *second* action (a light turns off, a
  lock unlocks), resolved through the same descriptor table as a tap.
- **`micropad/diag`** — retained diagnostics: uptime, MQTT connects, accept/reject counters
  per payload type, dropped events, the heap high-water mark and `stack_min`, the loop task's
  stack high-water mark, so the 16 KiB stack is confirmed by reading a topic rather than by
  attaching a debugger. Formatted in the core with a
  256-byte stack buffer, no ArduinoJson.
- **`micropad/device`** — the pad advertises its firmware version, contract revision and
  field caps, so the configurator can refuse a configuration the device cannot parse
  instead of watching it disappear.
- **Firmware-in-the-loop preview** — `tools/micropad_sim.cpp` compiles the shipped core into
  a host binary; the configurator's panel preview (`/api/simulate`) and the browser SVG are
  drawn from that model, so the preview cannot disagree with the device's layout code.
- **Config lint** — `scripts/lint_config.py` (exit 0/1/2, `--strict`, `--json`) and
  `POST /api/lint`, with budget meters for page bytes, catalog bytes, pages, items and
  per-field length against the firmware caps.
- **Config history** — every save leaves a content-addressed revision beside the config
  file (mode 600, git-ignored); `GET /api/history`, a structural diff that never prints a
  secret, and a restore behind a confirmation dialog.
- **Page generation from the entity cache** — `/api/entity-groups` and `/api/build-pages`
  turn Home Assistant domains into pages, reporting every shortened name and every skipped
  domain instead of silently trimming.
- **Single source of truth** — `contracts/mqtt-contract.json` drives `protocol_contract.h`,
  the browser constants and the Python constants; `scripts/generate_contract.py --write/--check`
  plus drift tests keep them from diverging.
- **Developer documentation** — `docs/developer.md` (how to add an action, an item type, a
  topic or a template), `docs/roadmap.md` (the 33-item backlog) and `docs/status.md` (what is
  shipped, with its evidence).

### Changed

- **Contract revision 1 → 2.** The wire format gained two topics (`micropad/device`,
  `micropad/diag`), four item types and the `alternate_action` binding field. A
  contract-2 configuration must not be pushed to a pad that reports revision 1 on
  `micropad/device`; the configurator warns on the mismatch. The codegen refuses a
  revision it has not been taught, so a future bump is a conscious edit.
- **Display strings are clipped, identifiers are not.** A 40-character name is shortened to
  fit the panel; a too-long entity id is still rejected, because silently trimming one
  would address a different device.
- Display caps 49 → 33 bytes and the render prim budget 48 → 32 (still > 25 % headroom over
  the measured worst case).

### Fixed

- **Silent failure paths** (the 1.2.0 firmware set): the MQTT payload is parsed in place
  (the 16 385-byte stack copy is gone); a failed `subscribe`, `publish` or watchdog
  subscription is treated as a lost connection instead of being ignored; an NVS save
  invalidates its commit marker first, so an interrupted write cannot boot with a mixture
  of old and new credentials; an unreachable Wi-Fi record re-opens the setup portal
  instead of stranding the device; a missing retained catalog is re-requested every 60 s.
- **A configured pad re-entered the setup portal on every boot.** The NVS read helpers used
  `Preferences::getBytesLength()`, a *blob* accessor (`nvs_get_blob`) that fails with
  `ESP_ERR_NVS_TYPE_MISMATCH` on an entry written with `nvs_set_str` and therefore reports 0 for a
  value that is present. Every stored string looked absent, so `loadSettings()` rejected the
  complete record and the pad fell back to the portal - which reads exactly like a Wi-Fi problem.
  Presence and values now use the string-shaped APIs, the port uses the type-aware `getType()`,
  and a static test keeps the blob accessor out of the sketch. A refused save now names the field
  and the rule instead of answering "invalid settings".
- **The firmware CI stage silently skipped four contract classes.** `unittest.main()` sat
  above them in `tests/firmware/test_firmware_static.py`, so the stage reported green with
  142 cases while 190 were collected — including every check for the fixes above. The entry
  point now sits at the end of the file, pinned by two tests that fail if it moves again.
- The long-press gesture no longer fires on the key press that wakes the pad; the panel
  simulator no longer drops the key id it was asked to press; configuration history lists
  revisions by write time, so several edits in one second keep their order.

### Measured

| Metric | Before | 1.2.0 |
|---|---|---|
| Flash | 1 004 527 B (76 %) | 1 006 811 B (76 %) |
| Static RAM | 181 548 B (55 %) | 173 364 B (52 %) |
| MQTT callback frame | 23 424 B | 6 704 B |
| Arduino loop stack | 32 KiB | 16 KiB (≈ +16 KiB heap at runtime) |
| Diagnostics payload | 9 fields | 10 fields, worst case 254 B of a 320 B cap |

Internal-heap gain from the fix set: ≈ 24.7 KB. Flash is not the constraint (≈ 303 KB free).

### Verified

832 pytest plus the tests added with the release commit (44 browser), 199 firmware static, 193 release tests,
the host core binary, a real `arduino-cli` build for
`esp32:esp32:esp32s3:USBMode=hwcdc,CDCOnBoot=cdc,PSRAM=opi`, plus ruff, mypy, the notice
audit and the public-release audit.

### Not verified on hardware

Nothing in this release has been flashed to a physical pad. What a flash and one press each
would close:

1. **The settings fix** - flash, configure once through the portal, restart: the pad must come
   up in normal mode with the panel showing the last page, and must *not* open the portal again.
2. **`stack_min`** - read `micropad/diag` after a full catalog parse: the number is the loop
   stack's remaining bytes (the linked frames predict 6,704 B used of 16 KiB).
3. **Long press and the four new item types** - hold Enter on a light (turns off), hold on a
   lock (unlocks), press a cover (toggles).
4. **Two behaviours worth watching** - the 250 ms sleep-predicate sampling, and the portal
   fallback after ~24 failed associations (it must not fire on a pad whose Wi-Fi is merely slow
   to come up).

### Deliberately not changed

Moving the catalog into PSRAM (≈ −122 KB static RAM) and shrinking `ENTITY_CAP` — both trade
a known-good failure mode for an unknown one and need their own change set with hardware
validation. No second protocol version, no cloud dependency, no scripting engine on the
device, no OTA outside the setup portal.

## 1.1.0 — clean-room baseline

Unreleased baseline for this branch; no changelog was kept. The firmware version it
publishes is `1.1.0` and the contract revision is `1`.

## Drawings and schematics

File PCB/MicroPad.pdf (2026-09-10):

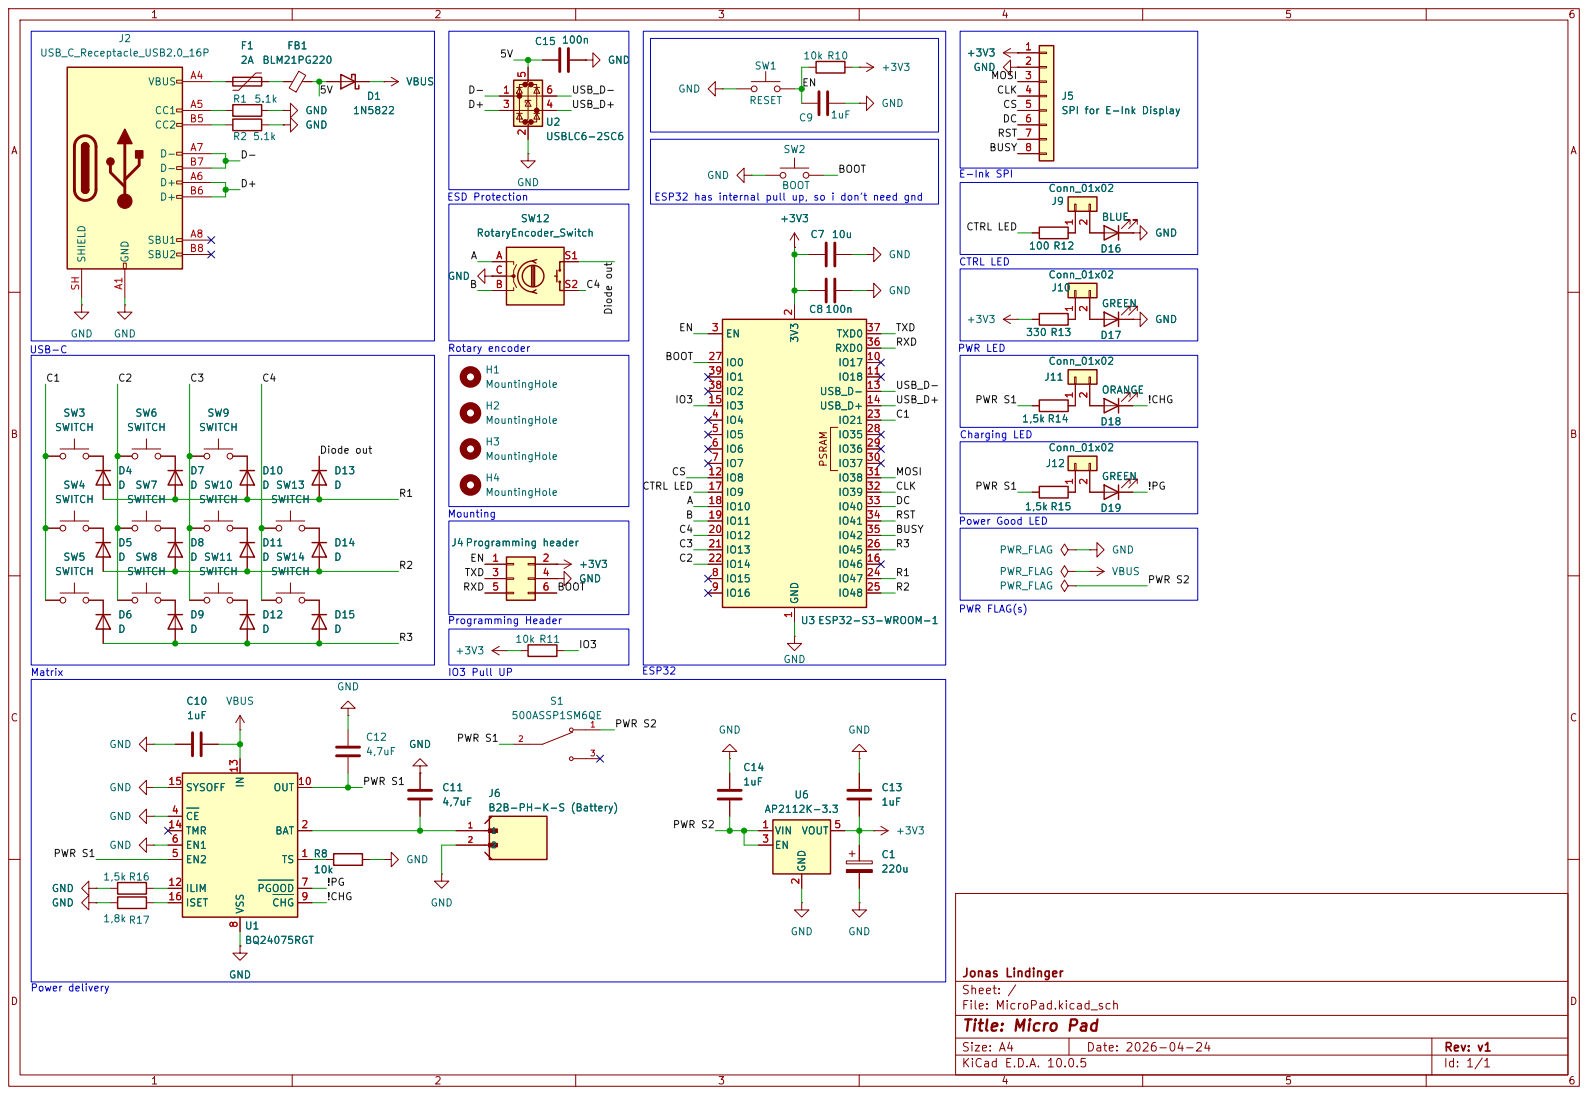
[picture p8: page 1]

SPI for E-Ink Display GND

Programming Header Matrix Power delivery

Size: A4 | Rev: v1
KiCad E.D.A. 10.0.5 | Id: 1/1

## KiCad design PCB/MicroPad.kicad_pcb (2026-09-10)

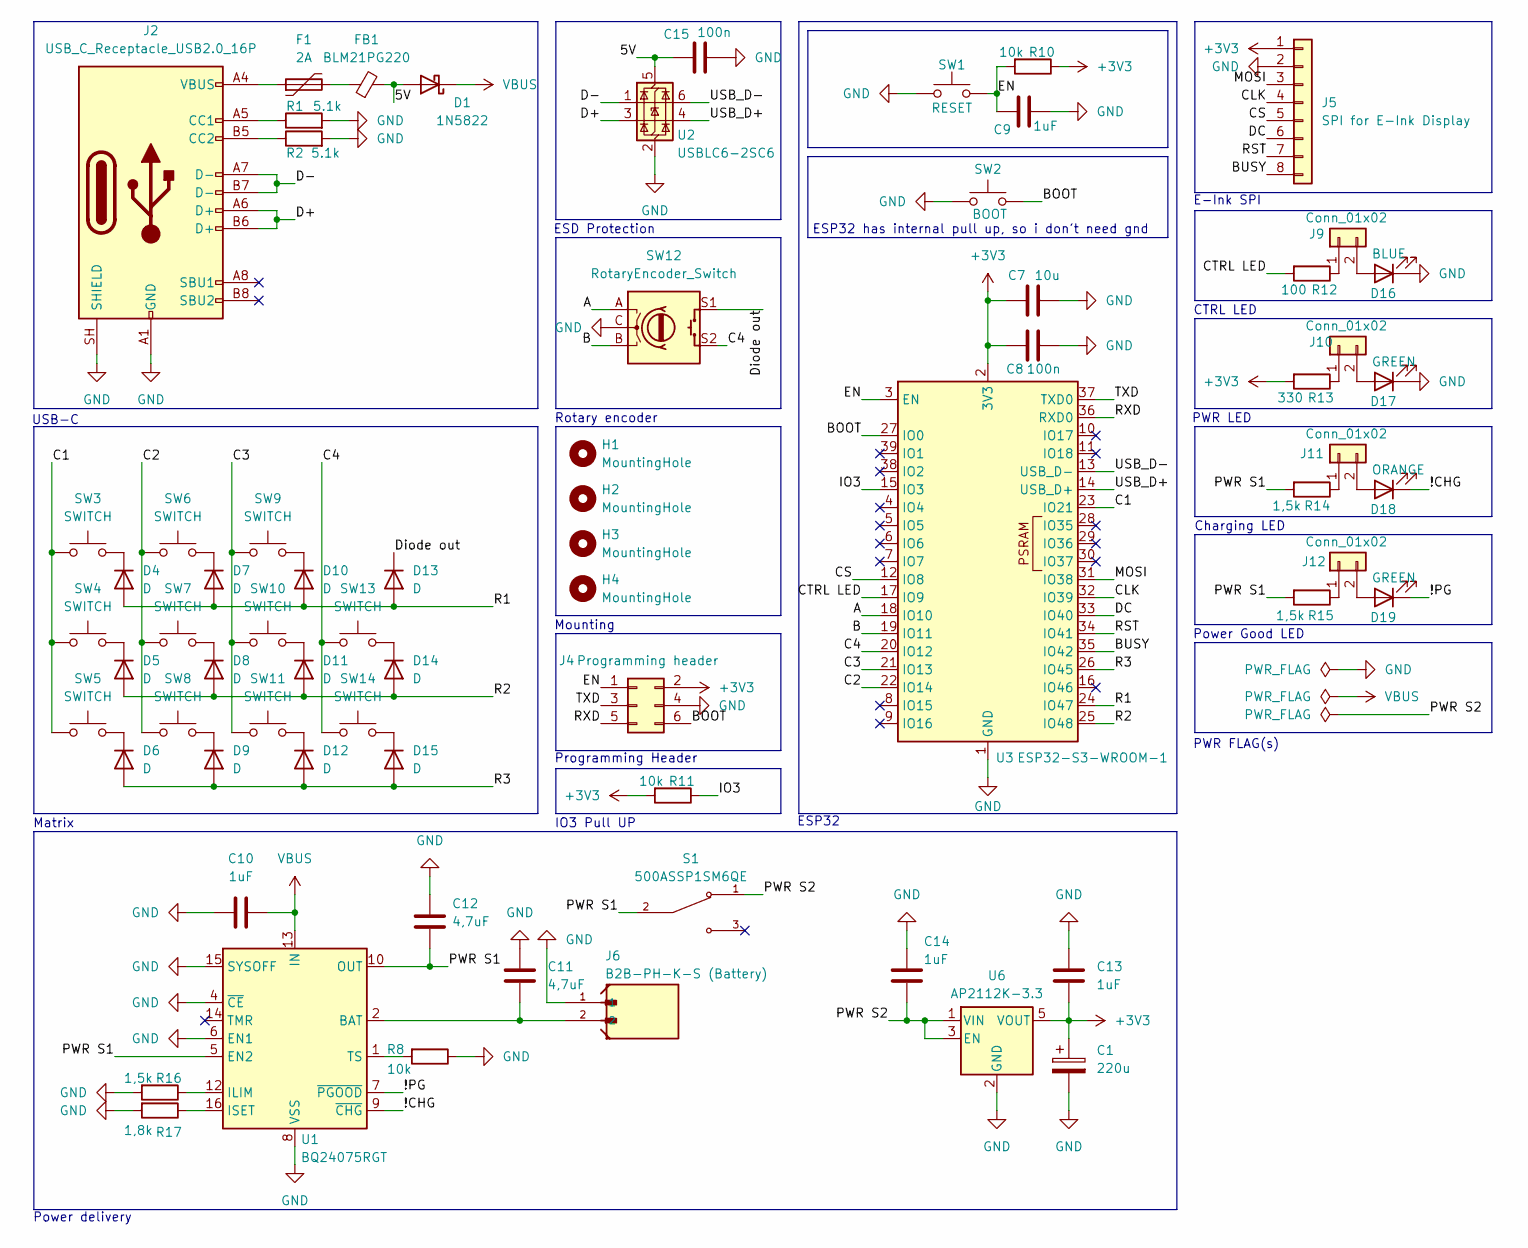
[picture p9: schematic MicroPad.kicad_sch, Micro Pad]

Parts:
C1: 220u; CP_Elec_6.3x7.7
C7: 10u; C_0805_2012Metric_Pad1.18x1.45mm_HandSolder
C8, C15: 100n; C_0805_2012Metric_Pad1.18x1.45mm_HandSolder
C9, C10, C13, C14: 1uF; C_0805_2012Metric_Pad1.18x1.45mm_HandSolder
C11, C12: 4,7uF; C_0805_2012Metric_Pad1.18x1.45mm_HandSolder
D1: 1N5822; D_DO-201AD_P15.24mm_Horizontal
D4, D5, D6, D7, D8, D9, D10, D11, D12, D13, D14, D15: D; D_SMA
D16: BLUE; LED_D3.0mm
D17, D19: GREEN; LED_D3.0mm
D18: ORANGE; LED_D3.0mm
F1: 2A; Fuse_0805_2012Metric_Pad1.15x1.40mm_HandSolder
FB1: BLM21PG220; L_0805_2012Metric_Pad1.05x1.20mm_HandSolder
H1, H2, H3, H4: MountingHole; MountingHole_3.2mm_M3_DIN965
J2: USB_C_Receptacle_USB2.0_16P; USB_C_Receptacle_GCT_USB4085
J4: Programming header; PinHeader_2x03_P2.54mm_Vertical
J5: SPI for E-Ink Display; PinHeader_1x08_P2.54mm_Vertical
J6: B2B-PH-K-S (Battery); JST_B2B-PH-K-S
J9, J10, J11, J12: Conn_01x02; SolderJumper-2_P1.3mm_Open_TrianglePad1.0x1.5mm
R1, R2: 5.1k; R_0805_2012Metric_Pad1.20x1.40mm_HandSolder
R8, R10, R11: 10k; R_0805_2012Metric_Pad1.20x1.40mm_HandSolder
R12: 100; R_0805_2012Metric_Pad1.20x1.40mm_HandSolder
R13: 330; R_0805_2012Metric_Pad1.20x1.40mm_HandSolder
R14, R15, R16: 1,5k; R_0805_2012Metric_Pad1.20x1.40mm_HandSolder
R17: 1,8k; R_0805_2012Metric_Pad1.20x1.40mm_HandSolder
S1: 500ASSP1SM6QE; SW_500ASSP1SM6QE; PARTREV A
SW1: RESET; SW_PUSH_6mm
SW2: BOOT; SW_PUSH_6mm
SW3, SW4, SW5, SW6, SW7, SW8, SW9, SW10, SW11, SW13, SW14: SWITCH; SW_Cherry_MX_1.00u_PCB
SW12: RotaryEncoder_Switch; RotaryEncoder_Alps_EC11E-Switch_Vertical_H20mm
U1: BQ24075RGT; VQFN-16-1EP_3x3mm_P0.5mm_EP1.6x1.6mm
U2: USBLC6-2SC6; SOT-23-6
U3: ESP32-S3-WROOM-1
U6: AP2112K-3.3; SOT-23-5

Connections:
+3V3: C1.1, C7.1, C8.1, C13.2, J4.2, J5.1, R10.1, R11.2, R13.2, U3.2 (3V3), U6.5 (VOUT)
/5V: C15.1, D1.2 (A), FB1.2, U2.5 (VBUS)
/!CHG: D18.1 (K), U1.9 (~CHG)
/!PG: D19.1 (K), U1.7 (~PGOOD)
/A: SW12.A, U3.18 (IO10)
/B: SW12.B, U3.19 (IO11)
/BOOT: J4.6, SW2.2, U3.27 (IO0)
/BUSY: J5.8, U3.35 (IO42)
/C1: SW3.1, SW4.1, SW5.1, U3.23 (IO21)
/C2: SW6.1, SW7.1, SW8.1, U3.22 (IO14)
/C3: SW9.1, SW10.1, SW11.1, U3.21 (IO13)
/C4: SW12.S2, SW13.1, SW14.1, U3.20 (IO12)
/CLK: J5.4, U3.32 (IO39)
/CS: J5.5, U3.12 (IO8)
/CTRL LED: R12.2, U3.17 (IO9)
/D+: J2.A6 (D+), J2.B6 (D+), U2.3 (I/O2)
/D-: J2.A7 (D-), J2.B7 (D-), U2.1 (I/O1)
/DC: J5.6, U3.33 (IO40)
/Diode out: D13.1 (K), SW12.S1
/EN: C9.1, J4.1, R10.2, SW1.2, U3.3 (EN)
/IO3: R11.1, U3.15 (IO3)
/MOSI: J5.3, U3.31 (IO38)
/PWR S1: C12.2, R14.2, R15.2, S1.2, U1.5 (EN2), U1.10 (OUT), U1.11 (OUT)
/PWR S2: C14.2, S1.1, U6.1 (VIN), U6.3 (EN)
/R1: D4.2 (A), D7.2 (A), D10.2 (A), D13.2 (A), U3.24 (IO47)
/R2: D5.2 (A), D8.2 (A), D11.2 (A), D14.2 (A), U3.25 (IO48)
/R3: D6.2 (A), D9.2 (A), D12.2 (A), D15.2 (A), U3.26 (IO45)
/RST: J5.7, U3.34 (IO41)
/RXD: J4.5, U3.36 (RXD0)
/TXD: J4.3, U3.37 (TXD0)
/USB_D+: U2.4 (I/O2), U3.14 (USB_D+)
/USB_D-: U2.6 (I/O1), U3.13 (USB_D-)
GND: C1.2, C7.2, C8.2, C9.2, C10.2, C11.1, C12.1, C13.1, C14.1, C15.2, D16.1 (K), D17.1 (K), J2.A1 (GND), J2.A12 (GND), J2.B1 (GND), J2.B12 (GND), J2.SH (SHIELD), J4.4, J5.2, J6.1, R1.2, R2.2, R8.1, R16.2, R17.2, SW1.1, SW2.1, SW12.C, U1.4 (~CE), U1.6 (EN1), U1.8 (VSS), U1.15 (SYSOFF), U1.17 (VSS), U2.2 (GND), U3.1 (GND), U3.40 (GND), U3.41 (GND), U6.2 (GND)
unnamed: C11.2, J6.2, U1.2 (BAT), U1.3 (BAT)
unnamed: D4.1 (K), SW3.2
unnamed: D5.1 (K), SW4.2
unnamed: D6.1 (K), SW5.2
unnamed: D7.1 (K), SW6.2
unnamed: D8.1 (K), SW7.2
unnamed: D9.1 (K), SW8.2
unnamed: D10.1 (K), SW9.2
unnamed: D11.1 (K), SW10.2
unnamed: D12.1 (K), SW11.2
unnamed: D14.1 (K), SW13.2
unnamed: D15.1 (K), SW14.2
unnamed: D16.2 (A), J9.2
unnamed: D17.2 (A), J10.2
unnamed: D18.2 (A), J11.2
unnamed: D19.2 (A), J12.2
unnamed: F1.1, J2.A4 (VBUS), J2.A9 (VBUS), J2.B4 (VBUS), J2.B9 (VBUS)
unnamed: F1.2, FB1.1
unnamed: J2.A5 (CC1), R1.1
unnamed: J2.B5 (CC2), R2.1
unnamed: J9.1, R12.1
unnamed: J10.1, R13.1
unnamed: J11.1, R14.1
unnamed: J12.1, R15.1
unnamed: R16.1, U1.12 (ILIM)
unnamed: R17.1, U1.16 (ISET)
unnamed: R8.2, U1.1 (TS)
VBUS: C10.1, D1.1 (K), U1.13 (IN)

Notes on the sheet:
CTRL LED
PWR FLAG(s)
PWR LED
ESP32
E-Ink SPI
IO3 Pull UP
Programming Header
Matrix
ESD Protection
Power delivery
Rotary encoder
Power Good LED
Mounting
Charging LED
ESP32 has internal pull up, so i don't need gnd
USB-C

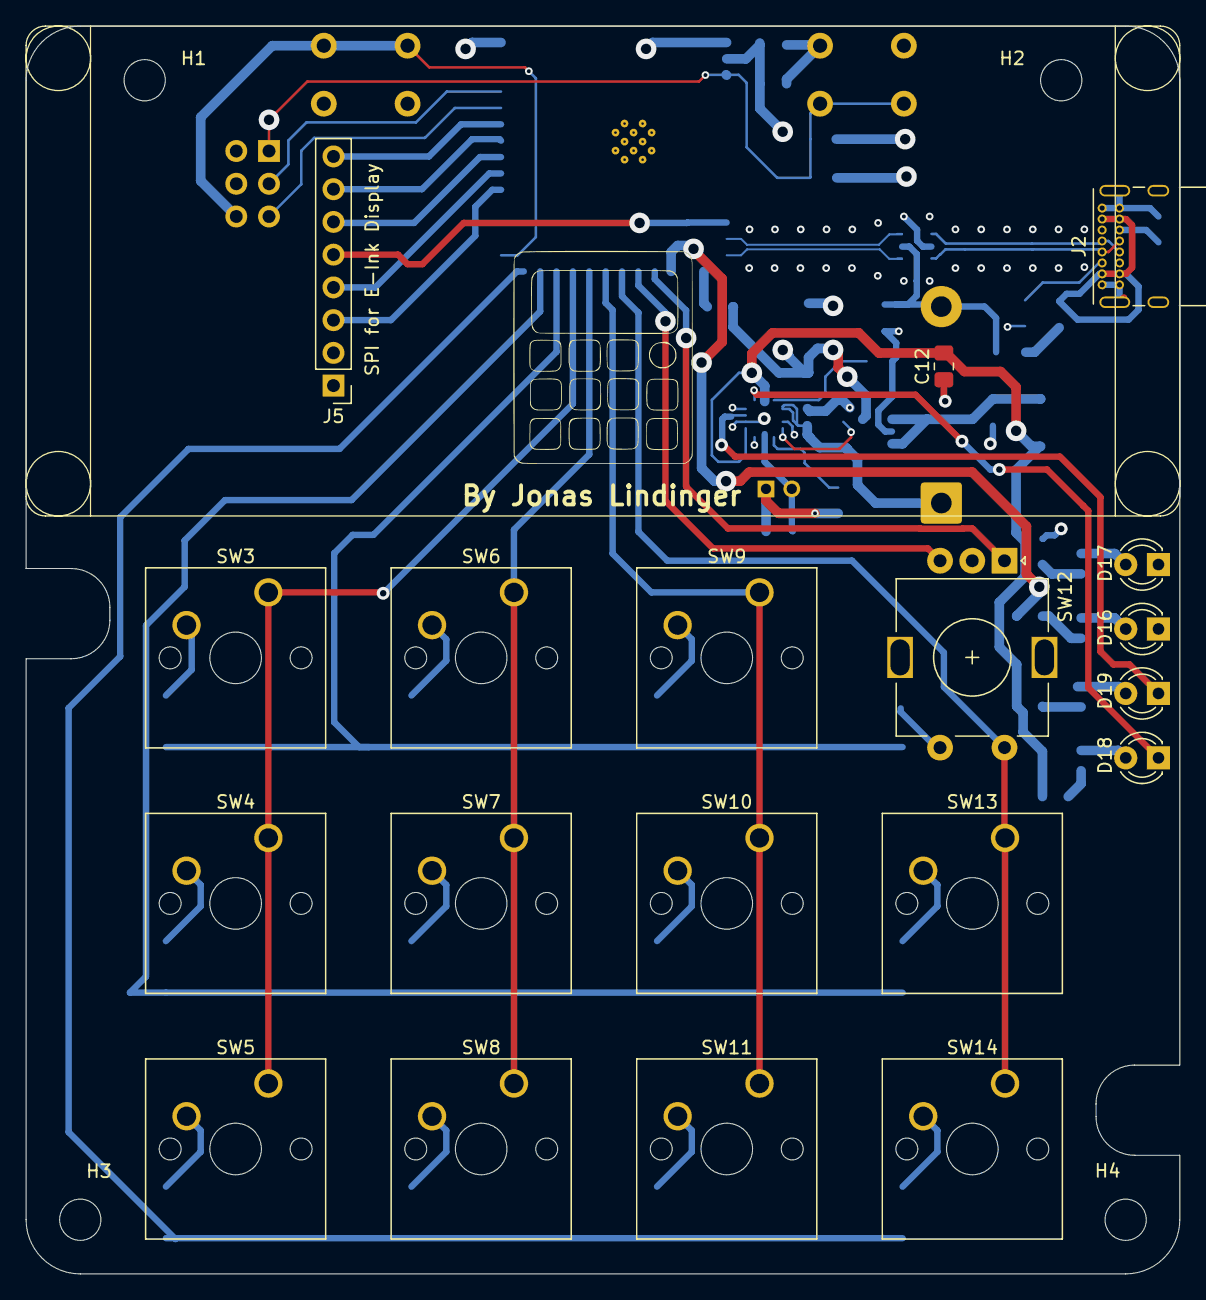
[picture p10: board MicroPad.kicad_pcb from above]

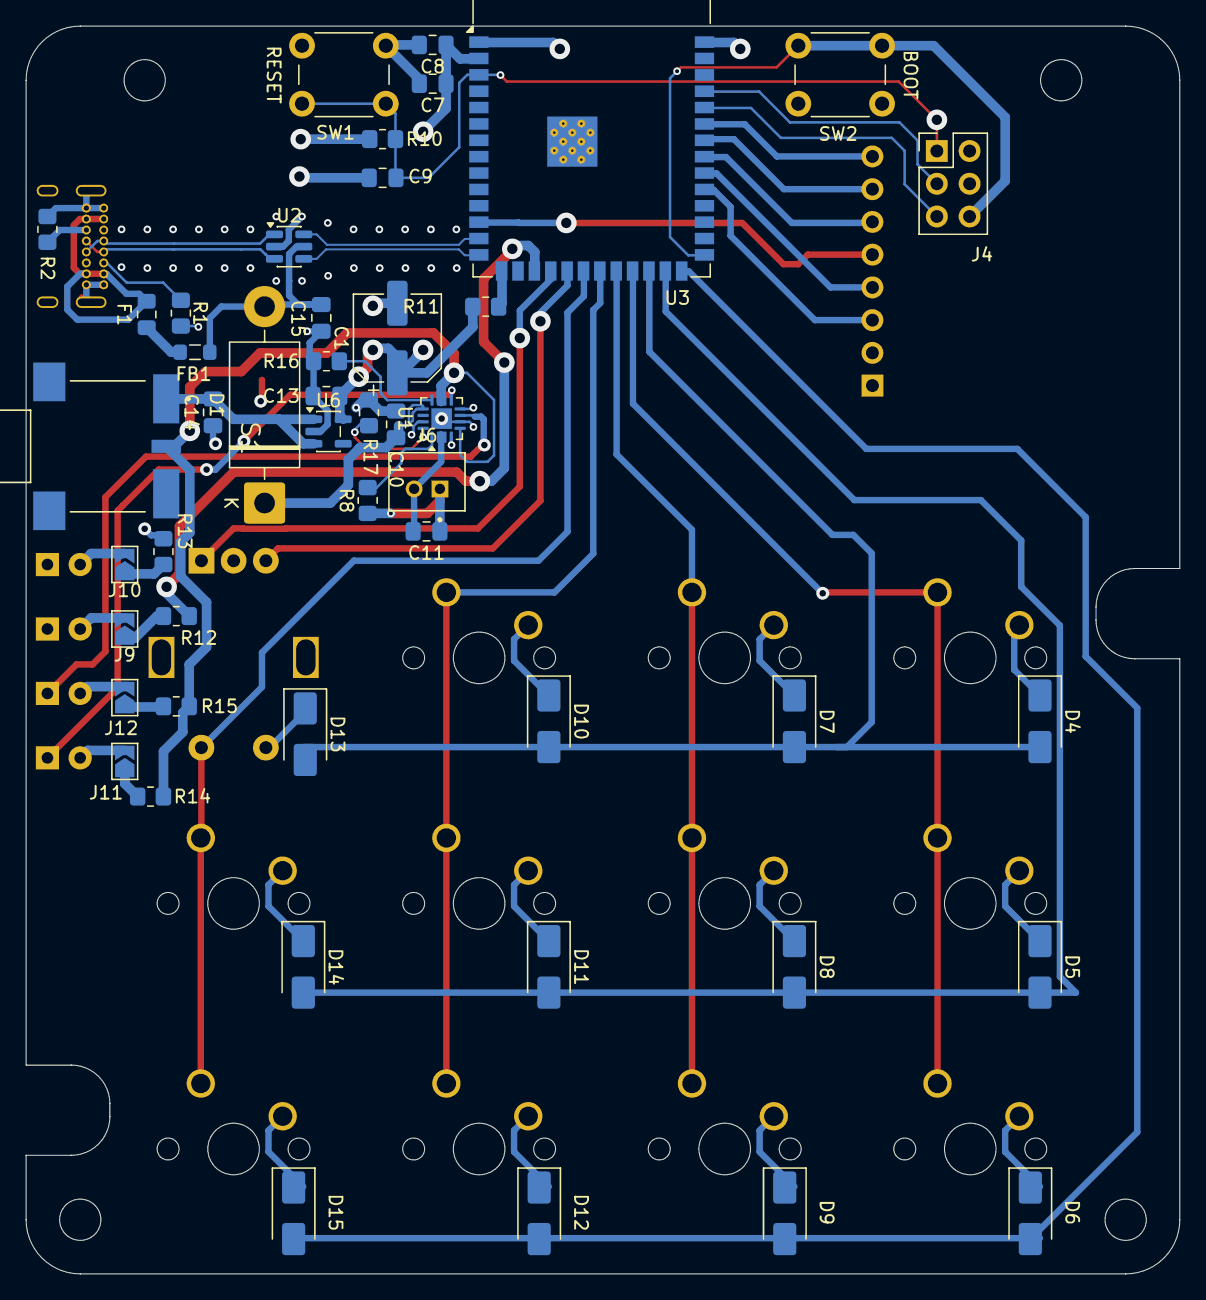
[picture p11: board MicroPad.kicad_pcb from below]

Board: 4 copper layers, 89.5 x 96.8 mm, 71 parts (48 on the bottom side), 61 nets.

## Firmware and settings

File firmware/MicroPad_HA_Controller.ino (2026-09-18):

// AI-assisted development — firmware, HA automation, config generator and docs were created with AI (LLM) help, reviewed and tested by the author. Provided as-is, without warranty; verify on your own hardware, don't use for safety-critical applications.
// MicroPad Home Assistant controller — Arduino entry point.
// This is the single Arduino sketch. All dependency-free logic lives in
// micropad_core.h/.cpp so it can be compiled and tested with a plain host C++
// toolchain (see scripts/test-firmware-host.sh and tests/firmware/).

#define DISABLE_DIAGNOSTIC_OUTPUT
#define MICROPAD_DEBUG 0
#include <GxEPD2_BW.h>
#include <Fonts/FreeMonoBold9pt7b.h>
#include <ArduinoJson.h>
#include <DNSServer.h>
#include <Preferences.h>
#include <PubSubClient.h>
#include <SPI.h>
#include <WebServer.h>
#include <WiFi.h>
#include <atomic>
#include <cassert>
#include <cmath>
#include <cstdio>
#include <cstdlib>
#include <cstring>
#include <esp_heap_caps.h>
#include <esp_sleep.h>
#include <esp_system.h>
#include <esp_task_wdt.h>
#include <esp_timer.h>
// USB-host detection (isPowered()): TinyUSB's tud_cdc_n_connected() only exists
// in the "USB Mode: USB-OTG (TinyUSB)" build (ARDUINO_USB_MODE == 0). With
// "Hardware CDC and JTAG" (ARDUINO_USB_MODE == 1) there is no TinyUSB stack, so
// the include stays conditional and the HWCDC host check is used instead.
#if defined(ARDUINO_USB_CDC_ON_BOOT) && ARDUINO_USB_CDC_ON_BOOT && \
    defined(ARDUINO_USB_MODE) && !ARDUINO_USB_MODE
#include "tusb.h"
#endif
#include <freertos/FreeRTOS.h>
#include <freertos/task.h>
#include "micropad_core.h"
#include "protocol_contract.h"

// Bring the bounded copy helpers into the sketch namespace. safeCopy() and
// safeCopyClip() are micropad templates taking char[N]/const char* args —
// neither is a micropad type, so unqualified calls get no ADL and only an
// explicit using-declaration resolves them. Every other core call is either
// prefixed (micropad::) or found by ADL from a micropad:: argument type.
using micropad::safeCopy;
using micropad::safeCopyClip;

// The Arduino loop task runs setup/loop and the MQTT callback. The callback no
// longer copies the payload onto this stack (it parses the PubSubClient buffer
// in place), which shrank its frame from 23,424 to ~7 KB; 16 KiB therefore
// keeps a ~2.3x margin over the measured frame while returning 16 KiB to the
// heap, where the 16-KiB MQTT buffer and the WiFi/lwIP buffers are allocated.
// The value lives in the core so the device-info payload (micropad/device) and
// the tests report the same number the linker actually reserves.
size_t getArduinoLoopTaskStackSize(void) { return micropad::LOOP_TASK_STACK_BYTES; }

// Render adapters defined at the end of the sketch (see the Task 8 render
// block): requestDraw publishes on Core 1, renderTask draws on pinned Core 0.
void buildSnapshot(micropad::RenderSnapshot &out);
void renderTask(void *argument);

constexpr uint8_t PIN_EPD_CS = 8;
constexpr uint8_t PIN_EPD_DC = 40;
constexpr uint8_t PIN_EPD_RST = 41;
constexpr uint8_t PIN_EPD_BUSY = 42;
constexpr uint8_t PIN_EPD_SCK = 39;
constexpr uint8_t PIN_EPD_MOSI = 38;
constexpr uint8_t ROW_PINS[3] = {47, 48, 45};
constexpr uint8_t COL_PINS[4] = {21, 14, 13, 12};
constexpr uint8_t ENCODER_A_PIN = 10;
constexpr uint8_t ENCODER_B_PIN = 11;

// First MATRIX_KEY_COUNT entries map to KeyIds r0c0..r2c3 by (row*4+col).
micropad::DebouncedInput matrixDebounce[micropad::MATRIX_KEY_COUNT];
micropad::QuadratureDecoder encoderDecoder;

// ============================================================================
// Nonblocking captive portal. One DNSServer + WebServer pass runs per loop
// (portalTick), input scanning continues while the portal is active, Back
// cancels without touching NVS, and a valid POST saves through saveSettings()
// after the complete candidate validates. The AP password is generated once
// from hardware entropy, saved to NVS, and reused by every later portal entry
// (issue #7); while the portal is open the device never light-sleeps (issue
// #6). No credential is a source constant.
// ============================================================================

// Fixed sketch-side portal display state, copied by the display task into
// RenderSnapshot (Task 8). Only the three fields the panel renders are kept:
// the former `active` and `instructions` members were written and never read.
struct PortalViewState {
  char ssid[33];
  char password[micropad::SETUP_PASSWORD_LENGTH + 1];
  char address[16];
};

bool portalActive = false;
bool portalExitSaved = false;
bool portalRoutesRegistered = false;
uint32_t portalLastActivityMs = 0;
char setupPassword[micropad::SETUP_PASSWORD_LENGTH + 1] = {};
PortalViewState portalView = {};
DNSServer dnsServer;
WebServer webServer(80);

// ============================================================================
// Streamed video player mode (the `player` action, sibling of `settings`).
// While playerActive the pad draws raw 1-bit frames from micropad/display/frame
// instead of the menu snapshot, and the buttons steer the host player service
// through micropad/player/control. Frames only render while the mode is open
// (the menu is never painted over); the PlaybackViewState holds the last
// micropad/player/state payload so buildSnapshot can render a title/status
// screen when no frame has arrived yet. playerFramePending is written by the
// MQTT callback on Core 1 and consumed by the render task on Core 0.
// ============================================================================
struct PlaybackViewState {
  char title[65];
  char status[16];
  char index[8];
  char videos[8];
};

bool playerActive = false;
std::atomic<bool> playerFramePending{false};
uint8_t playerFrame[micropad::PLAYER_FRAME_BYTES] = {};
PlaybackViewState playbackView = {};
// Core 0 -> Core 1 ready handshake (same shape as recoveryDrawNeeded): the
// render task must not call mqttClient (PubSubClient is not thread-safe), so it
// only raises this flag and loop() publishes the frame-ack topic once.
std::atomic<bool> playerReadyPending{false};

// 6-bit password alphabet: the & 0x3f index below needs exactly 64 entries.
constexpr char SETUP_ALPHABET[] =
    "ABCDEFGHIJKLMNOPQRSTUVWXYZabcdefghijklmnopqrstuvwxyz0123456789-_";
static_assert(sizeof(SETUP_ALPHABET) - 1 == 64);

// Active-low matrix pins: every column pull-up means a released switch reads
// HIGH and a pressed switch pulls it LOW. Rows idle HIGH and are driven LOW one
// at a time while a single column is sampled, then restored HIGH before the
// next row is strobed so no address ghost leaks into an unattended switch.
void setupInputPins() {
  for (uint8_t row = 0; row < micropad::MATRIX_ROWS; ++row) {
    digitalWrite(ROW_PINS[row], HIGH);
    pinMode(ROW_PINS[row], OUTPUT);
  }
  for (uint8_t col = 0; col < micropad::MATRIX_COLS; ++col) {
    pinMode(COL_PINS[col], INPUT_PULLUP);
  }
  pinMode(ENCODER_A_PIN, INPUT_PULLUP);
  pinMode(ENCODER_B_PIN, INPUT_PULLUP);
  encoderDecoder.reset(static_cast<uint8_t>(
      (digitalRead(ENCODER_A_PIN) << 1) | digitalRead(ENCODER_B_PIN)));
}

bool readMatrixKey(uint8_t row, uint8_t col) {
  digitalWrite(ROW_PINS[row], LOW);
  const bool pressed = digitalRead(COL_PINS[col]) == LOW;
  digitalWrite(ROW_PINS[row], HIGH);
  return pressed;
}

// Seam where every debounced input leaves the scanners. Resolving the
// effective keymap and dispatching the resolved action (queue, optimistic
// state, portal, sleep) is wired by the event-queue task; scanners never call
// any other subsystem directly.
micropad::PadController pad;
bool catalogReady = false;

// Activity clocks for the warm-sleep gate (Task 11). lastActivityMs is
// refreshed by every emitted input so the idle timeout counts real inactivity;
// awakeStartedMs anchors the 3000 ms post-wake minimum-awake brake and is set
// at every wake (setup() seeds it at boot in Task 12).
uint32_t lastActivityMs = 0;
uint32_t awakeStartedMs = 0;

void requestDraw(micropad::DrawReason reason);

void emitInput(const micropad::InputEvent &input) {
  const size_t index = static_cast<size_t>(input.key);
  if (index >= micropad::KEY_COUNT) return;
  lastActivityMs = input.atMs;  // every emitted event is input activity
  const micropad::Binding &binding = pad.activeKeymap[index];
  micropad::Action action = micropad::resolveBinding(binding, input);
  if (!input.pressed) return;
  // P1.1: a direct key binding steers exactly its own entity. Enter is the one
  // device-owned resolution that acts on the selected item, so the item's
  // entity is bound into a local copy of the binding — the stored keymap is
  // never rewritten and no selected item is substituted for a keymap entity.
  micropad::Binding resolved = binding;
  if (action == micropad::Action::Enter) {
    // A hold asks the item for its second action (light/switch: turn off instead
    // of toggle); a type without one ignores the hold, so nothing is dispatched
    // that the operator did not ask for. The tap path is untouched.
    if (input.longPress) {
      const micropad::Action alternate = pad.selectedItemLongPressAction();
      if (alternate == micropad::Action::None) return;
      action = alternate;
    } else {
      action = pad.selectedItemAction();
    }
    resolved.action = action;
    const micropad::Item *selected = pad.currentItem();
    if (selected != nullptr) safeCopy(resolved.entity, selected->entity);
  }
  // While the setup portal is active every input refreshes its inactivity
  // clock; only Back acts on it, exiting without touching saved settings.
  if (portalActive) {
    portalLastActivityMs = input.atMs;
    if (action == micropad::Action::Back) cancelPortal();
    return;
  }
  // While the video player is open the keys steer the host player service and
  // the menu item logic (including the Enter resolution below) is bypassed.
  // Enter toggles play/pause (long-press restarts the current video), the
  // encoder switches videos, Back (or the `player` action again) exits.
  if (playerActive) {
    switch (action) {
      case micropad::Action::Back:
      case micropad::Action::Home:
        stopPlayer();
        break;
      // The Enter key is keymapped to the `player` action (it opens the mode
      // from the menu), so inside the player Action::Player *is* Enter:
      // toggle play/pause, long-press restarts the current selection.
      case micropad::Action::Player:
        publishPlayerControl(input.longPress ? "restart" : "toggle");
        break;
      case micropad::Action::ScrollUp:
        publishPlayerControl("prev");
        break;
      case micropad::Action::ScrollDown:
        publishPlayerControl("next");
        break;
      default:
        break;
    }
    return;
  }
  // Settings entry through normal keymap resolution opens the setup portal.
  if (action == micropad::Action::Settings) {
    startPortal(input.atMs);
    return;
  }
  // The `player` action opens the streamed-video mode.
  if (action == micropad::Action::Player) {
    startPlayer(input.atMs);
    return;
  }
  const micropad::ApplyResult result =
      pad.applyAction(action, resolved, input.atMs);
  if (result.stateChanged) {
    requestDraw(micropad::DrawReason::StateChange);
  }
}

void scanMatrix(uint32_t nowMs) {
  micropad::scanMatrixPass(matrixDebounce, readMatrixKey, emitInput, nowMs);
}

void scanEncoder(uint32_t nowMs) {
  const uint8_t phase = static_cast<uint8_t>(
      (digitalRead(ENCODER_A_PIN) << 1) | digitalRead(ENCODER_B_PIN));
  micropad::scanEncoderPass(encoderDecoder, phase, emitInput, nowMs);
}

// Sleep-gate probe: the OR of every debounced held switch and a fresh
// active-low pass. Every row is restored HIGH before any press is acted on;
// resting encoder A/B levels are not held keys.
bool anyKeyHeld() {
  return micropad::anyMatrixKeyHeld(matrixDebounce, readMatrixKey);
}

// ============================================================================
// Persisted device settings (WiFi + MQTT), stored in Preferences/NVS. The
// dependency-free Settings type, neutral defaults and the validation rule live
// in micropad_core so host tests prove them without NVS; these two functions
// are the only NVS-touching seams and are pinned by static contract checks.
// ============================================================================

// Active settings. On first boot this is defaultSettings() (empty SSID ->
// first-boot portal); after loadSettings() it is populated from NVS when a
// complete, valid record exists.
micropad::Settings deviceSettings = micropad::defaultSettings();
bool mqttClientConfigured = false;

// Load and accept a stored settings record read-only. A value is used only
// when the version marker is current (cfg_ver == 1), every expected key is
// present, every bounded copy succeeds, and the complete result validates.
// The active settings are updated only on full success; NVS is closed on
// every path.
// Bounded, checked NVS string read (P1.5). A stored value that is absent, empty
// where the field is required, or longer than the field can hold must not be
// accepted: silently keeping a truncated value would let a corrupt record pass
// as a valid setting (and connect to a placeholder broker). Nothing is logged.
// The presence check uses isKey() and the read uses getString(): both are
// string-shaped APIs. getBytesLength() must NOT be used here - it is a blob
// accessor (nvs_get_blob under the hood) and an IDF blob read on an entry that
// was written with nvs_set_str fails with ESP_ERR_NVS_TYPE_MISMATCH, so it
// reports 0 for a value that is present. That turned every stored string into
// "absent", made loadSettings() reject a complete record, and sent a fully
// configured pad back into the setup portal on every single boot.
// getString() itself already refuses an oversized value (it returns 0 instead of
// truncating), which is the guarantee the length pre-check was trying to add.
bool readSettingString(Preferences &preferences, const char *key, char *out,
                       size_t capacity, bool required) {
  if (capacity == 0) return false;
  out[0] = '\0';
  if (!preferences.isKey(key)) return !required;  // absent: ok only if optional
  const size_t written = preferences.getString(key, out, capacity);
  if (written == 0 || written > capacity) {
    out[0] = '\0';
    return false;
  }
  return true;
}

// A wrong-sized or absent port record is not a valid setting either (P1.5).
// Type-aware for the same reason: getType() probes with the typed accessors, so
// a port stored with putUShort() is recognised as PT_U16. getBytesLength() would
// report 0 for it (blob read on an integer entry) and reject every stored port.
bool readSettingUShort(Preferences &preferences, const char *key,
                       uint16_t &out) {
  if (preferences.getType(key) != PT_U16) return false;
  out = preferences.getUShort(key, out);
  return true;
}

bool loadSettings() {
  Preferences preferences;
  if (!preferences.begin("micropad", true)) return false;

  micropad::Settings candidate = micropad::defaultSettings();
  const bool versionOk = preferences.getUChar("cfg_ver", 0) == 1;
  const bool keysPresent =
      preferences.isKey("wifi_ssid") && preferences.isKey("wifi_pass") &&
      preferences.isKey("mqtt_host") && preferences.isKey("mqtt_port") &&
      preferences.isKey("mqtt_user") && preferences.isKey("mqtt_pass") &&
      preferences.isKey("client_id");
  // Every field is read through a bounded, length-checked helper: presence,
  // stored length and maximum size are verified, so a corrupt or overlong
  // record cannot masquerade as a valid setting and fall back to a placeholder.
  const bool fieldsOk =
      readSettingString(preferences, "wifi_ssid", candidate.wifiSsid,
                        sizeof(candidate.wifiSsid), true) &&
      readSettingString(preferences, "wifi_pass", candidate.wifiPassword,
                        sizeof(candidate.wifiPassword), false) &&
      readSettingString(preferences, "mqtt_host", candidate.mqttHost,
                        sizeof(candidate.mqttHost), true) &&
      readSettingUShort(preferences, "mqtt_port", candidate.mqttPort) &&
      readSettingString(preferences, "mqtt_user", candidate.mqttUser,
                        sizeof(candidate.mqttUser), false) &&
      readSettingString(preferences, "mqtt_pass", candidate.mqttPassword,
                        sizeof(candidate.mqttPassword), false) &&
      readSettingString(preferences, "client_id", candidate.clientId,
                        sizeof(candidate.clientId), false);
  preferences.end();

  if (!versionOk || !keysPresent || !fieldsOk ||
      !micropad::validateSettings(candidate)) {
    return false;
  }
  deviceSettings = candidate;
  return true;
}

// Persist a validated settings record read-write. A complete candidate must
// validate before NVS is opened, credentials are never logged, and cfg_ver is
// written last as a commit marker so a partial write is never mistaken for a
// complete record. NVS is closed before returning.
bool putSettingsString(Preferences &preferences, const char *key,
                       const char *value) {
  return preferences.putString(key, value) == strlen(value);
}

bool saveSettings(const micropad::Settings &settings) {
  if (!micropad::validateSettings(settings)) return false;

  Preferences preferences;
  if (!preferences.begin("micropad", false)) return false;

  // Invalidate the commit marker FIRST. cfg_ver is already 1 from an earlier
  // successful save, so a field write that fails midway would otherwise leave a
  // mixture of old and new values that still passes validateSettings() on the
  // next boot — for example a new SSID with the previous Wi-Fi password, i.e. a
  // pad that associates nowhere and no longer opens its own setup portal.
  // With the marker at 0 first, an interrupted save is simply an invalid record
  // and the pad falls back to the setup portal.
  bool ok = preferences.putUChar("cfg_ver", 0) > 0;
  ok &= putSettingsString(preferences, "wifi_ssid", settings.wifiSsid);
  ok &= putSettingsString(preferences, "wifi_pass", settings.wifiPassword);
  ok &= putSettingsString(preferences, "mqtt_host", settings.mqttHost);
  ok &= preferences.putUShort("mqtt_port", settings.mqttPort) > 0;
  ok &= putSettingsString(preferences, "mqtt_user", settings.mqttUser);
  ok &= putSettingsString(preferences, "mqtt_pass", settings.mqttPassword);
  ok &= putSettingsString(preferences, "client_id", settings.clientId);
  ok &= preferences.putUChar("cfg_ver", 1) > 0;  // commit marker: written last
  preferences.end();

  if (ok) {
    deviceSettings = settings;
    mqttClientConfigured = false;  // re-apply host/port on the next MQTT tick
  }
  return ok;
}

// ============================================================================
// Captive portal implementation (see the portal state block above). The
// WiFi/DNS/WebServer adapters live here in the sketch; the portal state
// machine, form->Settings validation and timeout logic are pinned by the
// static contract tests in tests/firmware/test_firmware_static.py.
// ============================================================================

// ============================================================================
// Dual-core render snapshot mailbox (Task 8). The dependency-free two-slot
// state machine lives in micropad_core (SnapshotMailbox, host-tested); every
// sketch call to it here is wrapped by portENTER_CRITICAL/portEXIT_CRITICAL so
// Core 1 publishes to the non-rendering slot while the Core 0 render task
// draws the newest immutable snapshot. Renderers wait on task notifications:
// delay(1) polling would break light sleep.
// ============================================================================

micropad::SnapshotMailbox snapshotMailbox;
portMUX_TYPE snapshotMux = portMUX_INITIALIZER_UNLOCKED;
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
void loop() {
  esp_task_wdt_reset();  // feed the loop task's watchdog subscription
  const uint32_t nowMs = millis();
  scanMatrix(nowMs);
  scanEncoder(nowMs);
  portalTick(nowMs);
  wifiTick(nowMs);
  mqttTick(nowMs);
  diagnosticsTick(nowMs);
  if (mqttClient.connected()) mqttClient.loop();
  flushEventQueue();
  playerReadyTick();
  resyncTick(nowMs);
  catalogRequestTick(nowMs);
  powerTick(nowMs);
  renderRecoveryTick(nowMs);
  // Light sleep is disabled until the ESP32-S3 wake path is fixed: hardware
  // evidence shows that after a wake the matrix rows stay in their pre-sleep
  // LOW state, so one key press is read in all three rows (phantom actions).
  if (micropad::LIGHT_SLEEP_ENABLED && sleepGateReady(nowMs)) {
    enterLightSleep(nowMs);
  }
}

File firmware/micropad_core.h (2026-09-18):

// AI-assisted development — firmware, HA automation, config generator and docs were created with AI (LLM) help, reviewed and tested by the author. Provided as-is, without warranty; verify on your own hardware, don't use for safety-critical applications.
#pragma once

#include <cstddef>
#include <cstdint>
#include <cstring>

namespace micropad {

// Shared firmware constants (see "Shared Firmware Interfaces").
constexpr size_t KEY_COUNT = 14;
constexpr size_t QUEUE_CAPACITY = 16;
constexpr size_t MAX_FLUSH_PER_LOOP = 4;
constexpr size_t MAX_PAGES = 24;
constexpr size_t MAX_ITEMS_PER_PAGE = 20;
constexpr size_t VISIBLE_ROWS = 4;
constexpr size_t SETUP_PASSWORD_LENGTH = 16;
constexpr uint32_t INPUT_DEBOUNCE_MS = 25;
// How long a key must stay held before the hold counts as a long press. Chosen
// well above a deliberate tap (a normal press here is 25 ms of debounce plus a
// human tap) so the gesture cannot fire by accident.
constexpr uint32_t LONG_PRESS_MS = 600;
constexpr uint32_t RESYNC_SETTLE_MS = 350;
constexpr uint32_t WIFI_RETRY_MS = 5000;
// Recovery: a saved Wi-Fi record that can never associate (typo, moved AP,
// changed AP password) must not leave the pad unreachable. The default keymap
// binds no `settings` action and the effective keymap only arrives over MQTT,
// so after this many failed station attempts the pad re-opens its own setup
// portal instead — the Back key (bound by default) still cancels it and leaves
// the stored settings untouched. 24 attempts x WIFI_RETRY_MS = 2 minutes.
constexpr uint32_t WIFI_FAILS_BEFORE_PORTAL = 24;
constexpr uint32_t MQTT_RETRY_MS = 5000;
// A connected broker that never delivers the retained catalog (dropped because
// it exceeded the 16 KiB client buffer, or a lost retained publication) is
// invisible to the client, so the pad re-requests the catalog at this interval
// while it is connected but has no catalog.
constexpr uint32_t CATALOG_RETRY_MS = 60000;
// Setup-portal inactivity safety net (issue #6). The portal used to restart
// the pad after 5 minutes even while the phone was attached and the user was
// actively pairing, because the page HTTP traffic did not reach the activity
// clock. The pad now never restarts while a setup client is connected
// (portalTick gates the restart on softAPgetStationNum() == 0), and this
// client-free window is a generous 30 minutes so a bumped session does not
// lose the pairing flow.
constexpr uint32_t PORTAL_IDLE_MS = 1800000;
constexpr uint32_t IDLE_SLEEP_MS = 60000;
// Sleeping stays disabled (see the loop() comment): the ESP32-S3 wake path is
// still broken, and isPowered() only detects an open CDC data session, so a pad
// on a plain USB cable would be treated as battery-powered and sleep mid-session
// (MQTT keepalive dies, broker drops, pad never reconnects).
constexpr bool LIGHT_SLEEP_ENABLED = false;
constexpr uint32_t MIN_AWAKE_MS = 3000;
constexpr uint32_t USB_SAMPLE_MS = 500;
constexpr uint32_t USB_STABLE_MS = 1500;
// The warm-sleep predicate is sampled at this interval instead of once per
// loop pass: it can only become true after IDLE_SLEEP_MS (60 s) of idleness, so
// 250 ms of extra latency is irrelevant, while re-scanning the whole matrix on
// every pass (anyMatrixKeyHeld) doubled the input I/O of an awake battery pad.
constexpr uint32_t SLEEP_GATE_SAMPLE_MS = 250;
constexpr size_t MQTT_BUFFER_BYTES = 16384;
constexpr size_t EVENT_BUFFER_BYTES = 512;
// Periodic full-panel updates: a full refresh clears residual panel charge
// that makes black pixels slowly drift toward grey after many partial
// updates (hardware-observed ghosting on this panel). After
// MAX_PARTIAL_REFRESHES partial refreshes the next refresh is forced full;
// the visible flash is the accepted trade for staying black.
constexpr uint8_t MAX_PARTIAL_REFRESHES = 10;
// One streamed 1-bit video frame on the panel (296x128, MSB-first, bit=white).
// The player mode renders these raw frames instead of the menu snapshot; the
// size matches the contract's frame_bytes limit so a frame fits one MQTT
// message inside the 16 KiB PubSubClient buffer.
constexpr size_t PLAYER_FRAME_BYTES = 4736;
constexpr uint32_t MIN_REFRESH_SPACING_MS = 100;
// Loop-task task-WDT deadline (v6-proven 20 s). The default ESP-IDF deadline
// is 5 s with panic; the setup portal's WebServer can block the loop for its
// full socket timeouts while a pairing phone stalls a request, so the shorter
// default panics-reboots the pad during initial setup (issue #6).
constexpr uint32_t TASK_WDT_TIMEOUT_MS = 20000;

// Physical matrix geometry. The first MATRIX_KEY_COUNT KeyId values (r0c0 ..
// r2c3) map directly to (row * MATRIX_COLS + col).
constexpr uint8_t MATRIX_ROWS = 3;
constexpr uint8_t MATRIX_COLS = 4;
constexpr uint8_t MATRIX_KEY_COUNT = MATRIX_ROWS * MATRIX_COLS;

// Bounded string field capacities (see "Fixed Data Model"). Display-only
// fields (title, item name, state, unit) are clipped by safeCopyClip(); the
// identifier fields (page id, entity, target page) stay strict, because a
// clipped identifier would silently address the wrong entity or page. 32
// characters is already far more than the 12-character value column or the
// 22-character title strip can render, so shrinking the caps costs no
// visible information and returns 8 KB of static RAM.
constexpr size_t PAGE_ID_CAP = 33;
constexpr size_t TITLE_CAP = 33;
constexpr size_t ITEM_NAME_CAP = 33;
constexpr size_t ENTITY_CAP = 97;
constexpr size_t STATE_CAP = 33;
constexpr size_t UNIT_CAP = 17;

// Bounded credential fields (see "Persist Validated Device Settings"). Sizes
// match the NVS wire format: SSID 32+1, MQTT host 64+1, passwords 64+1, user
// 32+1, client id 48+1. Real credentials are never constants in source.
constexpr size_t WIFI_SSID_CAP = 33;
constexpr size_t WIFI_PASS_CAP = 65;
constexpr size_t MQTT_HOST_CAP = 65;
constexpr size_t MQTT_USER_CAP = 33;
constexpr size_t MQTT_PASS_CAP = 65;
constexpr size_t CLIENT_ID_CAP = 49;

// Firmware release reported in the retained device-info payload (micropad/device)
// so the backend/UI can see which build is on the pad and refuse a config whose
// fields this build would clip. Bump on behaviour changes that affect the wire
// contract's limits.
inline constexpr const char *FIRMWARE_VERSION = "1.2.0";
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

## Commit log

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2026-09-10 feat: per-page keymap tree + USB-aware sleep (#1)
    - Web editor: page tree sidebar (indented hierarchy), per-page key map
    editor with inheritance (global -> parent chain -> page overrides),
    scope switcher + 'inherit' reset per key.
    - Automation: publishes page + the page's effective keymap on every
    navigate/home; keymap request answers per page_id (fallback global).
    - Firmware: no light sleep while a USB host (PC) is attached
    (tud_cdc_n_connected(0) || (bool)USBSerial).
    - app.py/core.py: effective_keymap_for_page() merge + validation of
    per-page keymap entries.
2026-09-11 fix: MQTT buffer 8192 + compile in both USB modes (#2) [squash]
    Raises mqtt buffer 4096 -> 8192 so the 9-page retained catalog survives. NUL-cap raised in lockstep. tusb.h include made conditional so the sketch also builds on Hardware CDC + JTAG boards (ARDUINO_USB_MODE=1). mqttPass stays "replace-me" placeholder.
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2026-09-11 fix(fw): full-pass partial refresh (SSD1680 band windows drift randomly) + poll USB power so the power icon clears on unplug
2026-09-11 feat(fw): consolidate to v6 firmware on main
    - Replace firmware with the v6 drop (async render on core 0, safeCopy
    hardening, render-handoff race fix, page cache + prediction-confirm,
    resync, 16-K MQTT buffer, power-aware sleep, micropad/power heartbeat).
    - Keep Jonas' PR #5 features that were missing from the v6 drop:
    media transport actions (volume_up/down, media_next/prev) and
    pollPowerIndicator() so the power icon clears on USB unplug.
    - Fix README/docs/FIRMWARE.md references to the nonexistent v3 filename.
2026-09-11 fix(fw): restore power-icon rendering from PR #5 (M-3)
    The v6 drop regressed Jonas' dc95978 fix: the U+26A1 bolt glyph is not
    in FreeMonoBold9pt7b (invisible) and sat in the MQTT/WiFi indicator
    else-if chain (hidden whenever MQTT/WiFi indicator is active). Re-added
    the dedicated white-rect ring+line slot at LX=270 that always shows
    while USB power is present.
2026-09-11 fix(fw): instant first action after long light-sleep + no stray scroll on page-enter
    Bug 1 (laggy first press after idle): a light-sleep that outlives the
    MQTT keepalive (30 s) leaves a TCP socket that still reads 'connected'
    but whose broker session is already dead. The first publish after wake
    then stalls on the 1 s socket timeout before reconnecting - the
    multi-second 'first key press does nothing' lag. On such wakes, drop the
    stale session outright (WiFi stays associated, so reconnect is ~100 ms)
    and let the queued wake-press publish immediately.
    Bug 2 (navigation 'jumps one item down' on page-enter): the rotary
    encoder's push-switch couples mechanically to the detent, so confirming
    (en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
2026-09-11 revert(fw): drop stray-scroll suppression on page-enter (Bug 2 root cause was not an encoder ghost)
    The captured MQTT round-trip shows the real Bug-2 symptom is NOT a +1 scroll
    tick: the pad intermittently navigates a WHOLE level too deep (home -> steckdosen,
    skipping 'ha'), and only sometimes. That is a stale/inconsistent page-state race,
    not a scroll edge, so the page-entry scroll-suppress window is removed.
    The firmware accumulates (currentPage.id) and (items) inconsistently around wake
    in the flashed build; this v6 already applies pages atomically, so the first
    working hypothesis is an outdated flashed firmware. Tangible fix lives in a
    post-wake authority resync, to be addressed separat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
2026-09-11 fix(fw): clear stale currentPage on wake so the first press cannot skip a page
    MQTT capture of a single deliberate press right after wake showed:
    navigate target_page=steckdosen page_id=ha (the skip)
    home / keymap (reconnect reset, too late)
    The pad wakes with the pre-sleep page still live in currentPage, so the user's
    first press is interpreted against that stale page (ha, item 0 = Steckdosen)
    and fires a spurious multi-level navigation before the reconnect's home request
    lands. Reset currentPage to an empty home state on wake: itemCount==0 makes
    activateItem() a no-op until the authoritative home page arrives from the
    reconnect, closing the stale-input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
2026-09-11 fix(fw): hard-block light sleep while USB power is present (guard inside enterLightSleep)
2026-09-11 fix(fw): revert gap to 120 ms (50 ms ghosted the panel) + debounce the USB-power poll (1.5 s stable) so a flapping host signal cannot redraw forever
2026-09-11 fix(fw): stop refreshing the panel forever while USB-powered - the powered branch queued requestDraw() on every loop pass; indicator is handled by the debounced power poll
2026-09-13 feat: replace software with clean-room MicroPad implementation
    Replace firmware, Home Assistant automation, configurator, tests,
    deployment assets, README, and software documentation with the reviewed
    clean-room implementation. Preserve repository history, PCB and STL assets,
    and the existing project license.
    [MicroPad_HA_Controller.ino]
2026-09-14 fix: show live state instead of trailing zero; cut refresh spacing to 100ms; restore proven v6 gpio wakeup
    [micropad_core.h, test_core.cpp, test_firmware_static.py]
2026-09-14 fix(fw): persist setup-portal password, never sleep in portal, raise render stack
    Fixes GitHub issues #6 (crash/reboot during initial WiFi setup) and #7
    (new AP password on every portal entry).
    - Portal AP password: generated once from hardware entropy and persisted in
    NVS under setup_pass; every later portal entry loads it instead of
    regenerating (issue #7). A phone that already joined keeps its saved network.
    - The setup portal can no longer enter light sleep: sleepGateReady() and
    enterLightSleep() both refuse while portalActive, so the AP/DNS/web server
    stay alive mid-setup instead of silently dying under the phone (issue #6).
    - Render task stack raised 6144 -> 8192 and drawNetwo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
    [MicroPad_HA_Controller.ino, test_firmware_static.py]
2026-09-14 fix(fw): stop portal self-restart, restore 20 s task-WDT, keep persisted AP password
    Serial evidence from the pad showed the setup-portal reboots were clean
    textbook ESP.restart() calls (rst:0xc RTC_SW_CPU_RST), not panics: boot A
    restarted after exactly 300.5 s (= PORTAL_IDLE_MS) and boot B ~77 s after
    the page was opened.
    - portalTick(): the idle restart is a client-free safety net only. It is
    gated on softAPgetStationNum() == 0, so a connected phone (an active
    user) can no longer be reset mid-pairing; PORTAL_IDLE_MS 300000 -> 1800000.
    - setup(): configure the task watchdog explicitly like the proven v6
    firmware (20 s, idle_core_mask = 0, panic) with a
    esp_task_wdt_reconfigure() f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
    [MicroPad_HA_Controller.ino, micropad_core.h, test_firmware_static.py]
2026-09-14 fix(backend): schema equality, finite numbers, JSON strictness, state truncation (P1.9, P1.13)
    - Dynamic HA state/unit strings are truncated to display-safe UTF-8 byte
    budgets (128/8) before JSON generation, never splitting a codepoint, so a
    rendered page stays <= 8192 bytes and valid JSON even with 20k-char states.
    - PageItem.name must not be empty; value/min/max/step reject NaN/Infinity.
    - json.dumps/dump use allow_nan=False at config-store, generator and deploy
    wire boundaries.
    - Non-object top-level JSON and non-dict settings now yield structured JSON
    400/422, never an HTML 500.
    - Contract tests validate real generator output against page/keymap schemas.
2026-09-14 fix(ci/release): explicit gates, workflow hardening, hashed deps, preview verify (P1.17, P1.19, P1.20, P2.1, P2.2)
    - ci.sh now runs explicit ruff/mypy/coverage(>=90)/workflow-validate stages plus
    the existing unit/integration/browser/firmware/deployment/release stages
    (P1.20); REQUIRED_CI_STAGES and the orchestration contract updated to 16.
    - firmware.yml artifact names use safe fixed matrix ids hwcdc-psram,
    tinyusb-psram, hwcdc-no-psram instead of the FQBN (P1.17); static workflow
    validation test added (actionlint-equivalent).
    - All third-party GitHub actions pinned to commit SHAs (P2.1).
    - Build backend pinned exactly (setuptools==84.0.0); uv.lock committed and
    requirements-lock.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
2026-09-14 fix(firmware/backend): entity-binding contract, sleep interlock, refresh spacing, NVS/MQTT robustness (P1.1-P1.6, P1.14)
    [MicroPad_HA_Controller.ino]
2026-09-15 fix(firmware): optimisation fixes — static RAM, silent-failure paths, recovery
    Static RAM: display-only caps 49 -> 33 (name/title) with a new clipping copy helper, RENDER_PRIM_CAP 48 -> 32 (measured worst case 22), dead portal view fields removed. Measured: static RAM 181,548 -> 173,276 B (55% -> 52%), pad 126,408 -> 118,344 B, free DRAM +8,272 B.
    Stack/heap: the MQTT callback parses the PubSubClient receive buffer in place instead of copying up to 16,385 bytes onto the stack; the callback frame drops 23,424 -> 6,704 B (objdump) and the loop-task stack 32 -> 16 KiB, returning another 16,384 B to the heap.
    Robustness: client payloads are never discarded for being long (name/title/state/un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
    [MicroPad_HA_Controller.ino, micropad_core.h, test_core.cpp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]
2026-09-15 feat(contract): single source of truth (codegen + drift gates), item-type descriptors, device caps
    A1 — one source of truth. contracts/mqtt-contract.json gains action_meta,
    item_type_meta, a caps block and the sixth topic (micropad/device);
    scripts/generate_contract.py renders firmware/protocol_contract.h and the
    browser's key-id/version block (--write / --check), and micropad.constants /
    micropad.ui_meta derive from the JSON at import time instead of repeating the
    vocabulary by hand. The drift gate runs inside the existing mqtt-contract CI
    stage (the stage list is a pinned release contract, so no stage was added).
    A2 — one descriptor row per item type. micropad_core.h/.cpp gain
    ItemTyp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
    [MicroPad_HA_Controller.ino, micropad_core.h]
2026-09-15 feat(preview): firmware-in-the-loop panel preview, budget meters and config analysis
    A4 — the firmware core runs on the host. tools/micropad_sim.cpp compiles the shipped
    core into a small binary (scripts/build-simulator.sh, plain g++) that answers "what
    does the panel render for this page, and what does this key do" in one JSON object:
    the row window, the prim list from layoutNormalUi/layoutPortalUi, would_reject plus
    findings for fields the pad would clip or refuse, and the resolved binding/item
    action for a pressed key. The tool holds no geometry or policy of its own — it reads
    a documented directive format and calls the core. The sketch's buildSnapshot() row
    loop moved into the core a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
    [MicroPad_HA_Controller.ino, micropad_core.h]
2026-09-15 feat(lint): config-lint CLI and a complete firmware-host CI stage
    scripts/lint_config.py runs the same analysis as POST /api/lint from the command
    line, so a config can be checked before deployment or in CI: exit 0 publishable,
    1 for findings (errors always, warnings with --strict), 2 when the file cannot be
    read, plus --json for machine-readable output.
    The firmware-host CI stage only ran scripts/test_firmware_contract.sh, which
    covered the header/contract checks alone: tests/firmware/test_core.cpp (the core
    host binary) and tests/firmware/test_firmware_static.py (140 static contract
    tests) ran only on a developer machine, so a core regression could reach review
    unnoticed. Both are seconds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
2026-09-15 feat(firmware): retained diagnostics topic (C2)
    The pad now publishes micropad/diag: on every connect and then once a minute while
    connected. The payload carries uptime, successful MQTT connects, accept/reject
    counters for the catalog, page and keymap payloads, dropped events (queue full) and
    the heap high-water mark — the questions a serial console used to answer. A pad
    that reconnects in a loop, silently rejects a retained payload or runs the queue
    full no longer looks identical to a healthy one.
    The struct and the formatter live in the core (Diagnostics + formatDiagnostics in
    micropad_core.h/.cpp): the sketch only bumps counters and publishes from a
    256-byte stack buffer, with no Ardui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
    [MicroPad_HA_Controller.ino, micropad_core.h, test_core.cpp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]
2026-09-15 feat(firmware): long-press gesture resolves to the item's alternate action (C1)
    Holding the row under the cursor now dispatches that item type's alternate action
    instead of its default one: a light or a switch turns *off* on a hold instead of
    toggling, and every other type ignores the hold. This is the first gesture, and it
    deliberately costs no binding storage: the alternate comes from a new
    alternate_action column in the contract's item_type_meta (mirrored by the firmware's
    ITEM_TYPE_DESCRIPTORS table, asserted by the existing drift test), rather than from
    per-binding gesture fields — which would have cost ~1.8 KB of RAM plus a
    keymap-schema change for the same user-visible behaviour.
    T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
    [MicroPad_HA_Controller.ino, micropad_core.h, test_core.cpp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]
2026-09-15 feat(configurator): hardware-shaped keymap board with per-key action and origin (B4)
    The key selector is now the board: three rows of four keys beside the encoder, in the
    arrangement the operator's fingers find on the pad. Each key face shows the key id and
    the action that key currently performs, and data-binding-origin marks where that action
    comes from — global, inherited (from global or an ancestor page) or override (this
    page's own) — plus title text with the bound entity. A page's whole keymap is therefore
    readable at a glance instead of clicking through fourteen keys to see whether anything
    is overridden.
    The face is built by one helper (keyFace) that resolves the effective bindin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
2026-09-15 docs: publish the feature roadmap and the done/todo status (scrubbed)
    Two documents that were living in local scratch now live in the repo, because they answer
    the two questions the code cannot: what is planned, and what is actually shipped.
    - docs/roadmap.md — the 33-item backlog with effort, risk, hardware dependency and a
    definition of done per item.
    - docs/status.md — the ship list: per item the commit that landed it and the evidence
    (host test, drift gate, browser test, compile measurement), plus what is left, split
    into unblocked, blocked-on-a-decision and needs-the-physical-pad.
    Scrubbed before publishing: the local working paths, the second-person framing that made
    sense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
2026-09-15 fix(tests): the firmware CI stage was silently skipping four contract classes
    `unittest.main()` sat in the middle of tests/firmware/test_firmware_static.py, above the
    four newest classes. Run as a script - which is exactly what the `firmware-host` CI stage
    does - `unittest.main()` executes at that line, so every class defined below it never ran:
    FirmwareRobustnessFindingsTest, FirmwareStrictJsonTest, FirmwareSleepInterlockTest and
    FirmwareOptimisationContractTest, 48 test cases in total, including all twelve checks that
    pin this branch's silent-failure fixes (payload parsed in place, clipped display strings,
    subscribe/publish result handling, unreachable-Wi-Fi portal fallback, sleep-gate sam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
    [test_firmware_static.py]
2026-09-15 fix(firmware): a configured pad re-entered the setup portal on every boot
    The NVS read helpers checked a stored value with `Preferences::getBytesLength()`, which is
    a *blob* accessor - it calls `nvs_get_blob` under the hood. An IDF blob read on an entry
    written with `nvs_set_str` fails with `ESP_ERR_NVS_TYPE_MISMATCH`, so the helper returned 0
    for a value that was present. Every stored string therefore looked absent, `loadSettings()`
    rejected a complete record, `settingsLoaded` stayed false, and setup() called startPortal()
    - on every single boot, for a pad whose credentials were stored perfectly well. It presents
    as a Wi-Fi problem, which is why it survived this long: the settings themselve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
    [MicroPad_HA_Controller.ino, micropad_core.h, test_core.cpp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]
2026-09-15 chore(release): 1.2.0 - contract revision 2, changelog, version pins
    The wire format changed since the branch's baseline, so the contract revision moves 1 -> 2:
    two new retained topics (`micropad/device`, `micropad/diag`), four new item types, and the
    `alternate_action` field on bindings. A contract-2 configuration must not be pushed to a pad
    that reports revision 1 on `micropad/device` (the configurator warns on the mismatch).
    `scripts/generate_contract.py` refused the bump until it was taught the revision. That refusal
    is the point - it forces the bump to be a conscious edit instead of a number change that
    regenerates the old shape - so the accepted set is now an explicit constant and a d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
2026-09-15 fix(ui): a typed page title was discarded by the next re-render
    Found by the first CI run that ever reached the frontend stage. `test_page_commands_-
    persist_complete_config` failed on the runner with "Office copy never appeared" while the
    same test passed locally every time, and the captured log showed why: two configuration
    writes where the sequence needs three.
    The page toolbar is rebuilt from scratch on every render, so the title field is a fresh
    element each time, and its value lived only in that element. A re-render landing between
    typing the title and clicking "Rename page" - the autosave of the *previous* action is
    enough - threw the value away, `renamePage` then received an empty t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
2026-09-15 fix(fw): keep light sleep disabled until the S3 wake path is fixed
    The loop() comment already documented light sleep as disabled (phantom
    key presses after wake, so one press reads in all three rows), but
    LIGHT_SLEEP_ENABLED had been flipped to true. On a plain USB cable
    without an open CDC data session isPowered() reports false (battery),
    so after IDLE_SLEEP_MS (60 s) of idle the pad entered light sleep,
    mqttClient.loop() stopped being pumped, the 15 s MQTT keepalive died,
    the broker dropped the connection, and the pad never reconnected -
    it sat on the network screen until a key woke it.
    Set the constant back to false to match the documented policy, and pin
    it with a static contract test.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
    [micropad_core.h, test_firmware_static.py]
2026-09-15 fix(fw): keep light sleep disabled until the S3 wake path is fixed
    The loop() comment already documents that light sleep must stay disabled
    (phantom key presses after wake), but LIGHT_SLEEP_ENABLED was true. On a
    plain USB cable with no open CDC session isPowered() reads false, so after
    60 s idle the pad slept, mqttClient.loop() stopped, the 15 s keepalive
    died, the broker dropped the pad, and it never reconnected. Pin the
    constant to false with a static contract test.
2026-09-15 chore(repo): drop the committed .arduino symlink and egg-info artifacts
    The commit that followed the light-sleep policy change carried a build tree into
    version control: `.arduino` (a symlink into a local /tmp toolchain checkout),
    `src/micropad_configurator.egg-info/`, and a .gitignore whose `*.egg-info/` line
    had been merged into `*.egg-info/.arduino` instead of ignoring egge-info and
    .arduino separately.
    The dangling symlink made the firmware CI job fail at "Install and verify pinned
    toolchain (core 3.3.11 + libraries)", so none of the three device builds ran.
    Remove both paths from the index (the files stay on disk) and ignore them again.
2026-09-15 fix(fw): a powered pad must not be treated as battery
    isPowered() returned static_cast<bool>(Serial) only. In the hwcdc build that is
    HWCDC::isCDC_Connected(), whose `connected` flag is set exclusively by
    hw_cdc_isr_handler() -- and that handler is installed only by HWCDC::begin().
    The sketch never called begin(): the core starts USB CDC automatically for the
    TinyUSB build only (cores/esp32/main.cpp: `#if ARDUINO_USB_CDC_ON_BOOT &&
    !ARDUINO_USB_MODE`). isPowered() was therefore permanently false, the pad
    counted as battery-powered on every cable, slept after IDLE_SLEEP_MS, stopped
    pumping mqttClient.loop(), lost the 15 s keepalive and the broker dropped it --
    the pad looked dead until a key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
    [MicroPad_HA_Controller.ino, test_firmware_static.py]
2026-09-15 feat(ui): paper design language and a content-hashed asset version
    The frontend shipped no typography, colour or component styling at all: the
    workspace grid was laid out, everything inside it rendered with the browser's
    default serif and native form controls, so a working page read as "the CSS is
    missing". This gives the configurator one deliberate design language, chosen
    for a tool that configures an e-paper device: paper surfaces, ink type,
    hairline rules, no shadows or gradients, ink as the single accent.
    - tokens for palette, type (serif display, system sans, mono for identifiers)
    and status colours, with an ink dark mode behind prefers-color-scheme
    - panels, page tree, item editor,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
2026-09-15 fix(configurator): link created pages, read legacy configs, work in a container
    Four defects that all showed up in one session on the live deployment:
    * A page created from a template (or with "Add child page") was added to the config
    but linked from nothing. The pad builds its menus from a page's *items*, so the
    page existed in the configurator and could never be opened on the device -
    reported as "the website says there is a Spotify page, the board does not show
    it". New pages now get a category item on their parent (skipped when the parent is
    at the item cap, with the notice saying so), and the analysis reports any page
    nothing links to as `page_unreachable`.
    * `/api/lint` fe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
2026-09-15 fix(fw): keep black pixels black - panel hibernate + periodic full refresh
    Hardware observation of ghosting (black areas slowly drifting to grey after
    many partial updates) triggers the anti-ghosting policy the code was already
    waiting for: MAX_PARTIAL_REFRESHES goes from 0 (fulls disabled) to 10, so a
    full-panel clear runs after every 10 partial refreshes and resets residual
    panel charge.
    Also hibernate the SSD1680 after every successful refresh: with the driver
    left awake the bistable image bleeds over time; deep sleep keeps the pixels
    charged and the panel truly bistable between updates.
    [MicroPad_HA_Controller.ino, micropad_core.h, test_core.cpp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]
2026-09-16 fix(fw): row names use the full width and truncate with an ellipsis
    A long item name was hard-clipped at the fixed 150 px name column, so
    "3D Drucker Outlet" rendered as "3D Drucker O" - a mid-word cut with
    no indication that text was missing.
    The name now spans everything left of the right-aligned value span (plus
    one character of breathing room), so a short value such as on/off leaves
    almost the whole row to the name. When the source still cannot fit, the
    name is truncated to the budget with a trailing "..." marker instead of
    ending mid-word. Adds clipTextEllipsis() to the core with host tests, and
    unifies the refresh-spacing guard now that MAX_PARTIAL_REFRESHES > 0.
    [MicroPad_HA_Controller.ino, micropad_core.h, test_core.cpp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]
2026-09-16 fix(web): offer entity autocomplete in the new-item draft too
    The draft area rendered its Entity ID as a plain text input while existing
    item cards got the full autocomplete, so adding a fresh item offered no
    Home Assistant entity suggestions. Wire attachEntityAutocomplete into the
    draft field with the same getEntities/onSelect/onError contract (dispatching
    draft-update instead of commitChange) and pin it with a browser test.
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
